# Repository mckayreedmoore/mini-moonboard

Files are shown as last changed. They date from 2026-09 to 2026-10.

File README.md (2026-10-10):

# Mini MoonBoard DIY frame

Engineering models, calculations, viewers and conditional shop documents for
a Mini MoonBoard-sized climbing wall. This independent project is not affiliated
with or endorsed by Moon Climbing.

## Main development: Compact bolted frame

Start at the **[development summary and revision map](docs/bolted-frame-development/README.md)**.
It identifies the current geometry, matching nominal shop records, applicable
numerical evidence and remaining work.

The current geometry is **`eoere-raised-kicker-screws-v1`**:
[open the current viewer](https://mckayreedmoore.github.io/mini-moonboard/?model=eoere-selected-hardware-frame-development&view=rear).
Its optional extra grid remains off and unofficial. The
[checked revision index](docs/bolted-frame-development/development-revisions.json)
separates this geometry and its matching shop plan from the preceding
six-case numerical evidence. The current viewer applies the selected bolt lengths and eight spacers
through a separately bound hardware overlay.
Actual hardware-fit, installation and joint-strength holds remain. No fabrication or climbing
release is established.

| Need | Start here |
| --- | --- |
| Model, shop records and next actions | [Main development entry](docs/bolted-frame-development/README.md) |
| Detailed evidence and task dispositions | [Development ledger](docs/wood-joints-mvp/completion-ledger.md#build-package-completion) |
| Preserved selected baseline | [Baseline reference packet](docs/README.md) · [machine authority](current-candidate.json) |
| Earlier options, failures and lessons | [Design-history catalog](docs/history/design-history.md) |
| Repository organization and evidence recovery | [Cleanup record](docs/repository-cleanup-evaluation-2026-09-28.md) |

## Selected baseline and history

The selected screw-and-bracket baseline remains `compact-floor-flush-development`
under [current-candidate.json](current-candidate.json). Its
[working set](docs/selected-working-set.md) and conditional shop/evidence packet
stay preserved. Its passes do not qualify the compact bolted development frame.

Earlier Eoere, HL35, thin-frame and wood-joint studies remain accessible through
the history catalog and [full viewer collection](https://mckayreedmoore.github.io/mini-moonboard/).
The viewer's no-query default remains the selected baseline; use the explicit
current-development link above. Original proposal contracts keep their own
revision identities.

## Contributor setup

Work on `master` and coordinate file ownership and publication with other agents.
Read [AGENTS.md](AGENTS.md) and [CONTRIBUTING.md](CONTRIBUTING.md) before changing
geometry, evidence or archived files.

```sh
uv sync --locked
uv run python -m http.server 8767 --directory site
```

Open [the local current-development viewer](http://localhost:8767/index.html?model=eoere-selected-hardware-frame-development&view=rear).
Required ignored inputs stay active; follow the documented recovery workflow
before reproducing or archiving evidence.

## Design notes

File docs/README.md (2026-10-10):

# Selected baseline reference packet

For ongoing compact bolted-frame engineering and builder-support work, start at the
**[main development summary and revision map](bolted-frame-development/README.md)**.
Its [active builder reading path](bolted-frame-development/README.md#active-builder-reading-path)
identifies the geometry, source-bound shop records, overrides and remaining holds.
The current geometry is **`eoere-raised-kicker-screws-v1`**:
[current viewer](https://mckayreedmoore.github.io/mini-moonboard/?model=eoere-selected-hardware-frame-development&view=rear).
The [checked revision index](bolted-frame-development/development-revisions.json) keeps
the matching shop plan separate from the preceding six-case numerical evidence.
The plan includes the current channel/screw changes and selected hardware
overrides, now applied by the separately bound hardware viewer overlay.
Historical results retain their own revision limits.

The instructions below belong to the selected screw-and-bracket baseline,
`compact-floor-flush-development`, governed by
[current-candidate.json](../current-candidate.json). They preserve that baseline's
conditional shop packet and evidence. Earlier models and results remain in the
[design-history catalog](history/design-history.md).

## 1. Baseline plywood variants

| You have | Open |
| --- | --- |
| Bought **4×4** sheets (or Mini kit panels) | [https://mckayreedmoore.github.io/mini-moonboard/](https://mckayreedmoore.github.io/mini-moonboard/) · [cut sheets](https://github.com/mckayreedmoore/mini-moonboard/tree/master/docs/floor-flush-construction) |
| **Cut 4×8** sheets | [https://mckayreedmoore.github.io/mini-moonboard/?model=compact-floor-flush-kerf-right](https://mckayreedmoore.github.io/mini-moonboard/?model=compact-floor-flush-kerf-right) · [cut sheets](https://github.com/mckayreedmoore/mini-moonboard/tree/master/docs/floor-flush-construction-kerf-right) |

Or open the first 3D link and pick the matching line under **Design**.
Details: [Which plywood packet](floor-flush-width-option.md).

Bought 4×4 versus cut 4×8

Left is A, right is K

## 2. Baseline cut, drill and assembly records

1. [Shop checklist](floor-flush-shop-checklist.md)
2. [Assembly guide](floor-flush-assembly-guide.md)
3. The cut-sheet folder from step 1

Supporting baseline references: [orientation](orientation.md) (left is A, right is K),
[hold hardware](moonboard-hold-hardware.md), [LED routing](led-wiring-reference.md),
[panel screws](current-panel-screw-purchase.md), [pads](current-crash-pad-construction.md),
[later insert option](screw-repair-inserts.md).

## 3. Baseline calculations and conditions

[Build package](floor-flush-build-package.md) ·
[Master plan](floor-runner-mvp-master-plan.md) ·
[Completion ledger](floor-runner-mvp-completion-ledger.md)

## Reading paths

For baseline shop records, use the matching **4×4** or **4×8** folder, the
**checklist** and the **assembly guide** together. Read their recorded conditions.
For the active development lane, return to the [compact bolted-frame summary](bolted-frame-development/README.md).
For earlier ideas and the writeup, use [history/](history/).

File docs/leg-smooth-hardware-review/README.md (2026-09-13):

# Smooth-body leg hardware investigation

> **Historical document — superseded as current guidance on September 12, 2026.**
> Start with the [current design basis](../current-design-basis.md) and
> [current design review](../current-design-review.md) for `no-shoes-development`.
> The original text below preserves its candidate-specific decisions and evidence;
> “current,” “next,” and release requirements below refer to that historical scope.
> Its dimensions, schedules and results do not qualify the latest candidate.

This is an isolated hardware candidate for the eight existing leg bolts in
`round-reinforcement-development`. It is **not selected or strength-qualified**.
The frame, holes, and all other hardware remain unchanged. Joint bending still
requires assessment; passing the stack and collision checks does not resolve it.

Each candidate stack contains a 3/8-16 × 5-inch SAE J429 Grade 5 bolt, two
fabricated A36 round plate washers (38.1 mm outside diameter, 11.1125 mm bore,
6.35 mm thickness), one nut-side steel spacer (20 mm outside diameter,
11.1125 mm bore, 19.05 mm length), and a matching Grade 5 nut. The spacer lies
between the nut-side plate and nut, outside the wood. Finished dimensions are
acceptance requirements. No existing purchased hardware is claimed compliant.

The dimensional calculation assumes each wood member measures 37.5–38.5 mm,
a maximum bolt length shortfall of 2.54 mm, a 25.4 mm reference thread length,
and five pitches of runout. The supplier must meet these assumptions. The
minimum smooth body covers both complete wood members and the head-side plate.
The nut seats beyond the maximum gaging length, with at least two pitches of
bolt projection beyond the maximum-height nut. Cylindrical head and nut
representations bound the conservative dimensional envelope; they do not model
thread engagement surfaces or certify a product standard.

`hardware.step` contains the 48 individually named candidate components only.
`review.json` records the dimensional corners, mass envelope and nominal CAD
checks. The CAD check tests intersections against the unchanged frame and other
hardware, and full ring support by translating each plate into its receiving
wood member. This is not a manufacturing-tolerance or installation-tool check.

Reproduce the review from the repository root:

```python
import json
from pathlib import Path
from mini_moonboard import leg_smooth_hardware as model

folder = Path("docs/leg-smooth-hardware-review")
report = model.export_review(folder)
report["geometry"] = model.geometry_review()
(folder / "review.json").write_text(json.dumps(report, indent=2) + "\n")
```

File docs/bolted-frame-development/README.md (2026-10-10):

# Compact bolted frame development

This is the main entry for `compact-bolted-frame-development`.
The current geometry is **`eoere-raised-kicker-screws-v1`**,
with the optional extra grid **off**: 22 timbers, six panels, 22 angles,
100 bolt stacks and 66 purchased Hillman panel/kicker screws. The retained
evidence folder keeps earlier wood-joint studies at their frozen paths. The selected
[baseline authority](../../current-candidate.json) stays separate.

The [checked revision index](development-revisions.json) binds geometry,
optional preview, applied hardware and response separately. The current geometry
raises two upper outer kicker screws/holes from Z192 to **Z212 mm**, retaining
all 100 bolt axes. The modeled maximum-bore/screw gap is **3.94375 mm**;
post-top axis distance is 26.9 mm and end-distance strength remains unqualified.
The preceding smaller channels and eleven filled principal arc cuts remain.
The viewer applies `eoere-selected-purchase-hardware-v1`: 32 longer bolts and eight spacers, with all axes retained.

## Active builder reading path

| Need | Start here | Boundary |
| --- | --- | --- |
| Current geometry | [Selected-hardware viewer](https://mckayreedmoore.github.io/mini-moonboard/?model=eoere-selected-hardware-frame-development&view=rear) · [receipt](../wood-joints-mvp/hypotheses/hl35-candidate/thin-frame-comparison/eoere-successor-v1/occupied-kicker-clearance-v1.json) | Geometry evidence only; 100 bolts fixed, two screws raised. |
| Current shop records and hardware choice | [Matching shop packet](../wood-joints-mvp/hypotheses/hl35-candidate/thin-frame-comparison/eoere-successor-v1/shop-assembly-v1/extended-cleat-followup-v1/current-model-followup-v1/README.md) · [100 selected stacks](../wood-joints-mvp/hypotheses/hl35-candidate/thin-frame-comparison/eoere-successor-v1/shop-assembly-v1/extended-cleat-followup-v1/current-model-followup-v1/hardware-selection.csv) | Current screw/channel datums; selected bolt lengths and eight spacers are now applied in the viewer. Actual fit and strength remain open. |
| Preserved fixture concepts | [Builder drilling guide](../wood-joints-mvp/eoere-builder-drilling-guide.md) | Frozen aligned-wire geometry; later v3 moved 22 shafts and ten screws. Actual reach, fixtures and tools remain unresolved. |
| Latest numerical evidence | [Six fresh cases](../../fea/generated/thin-bolted-current-contact-v1/eoere-successor-v1/adjusted-base-mechanics-v1/current-cases-v1/result-v1.json) · [parent verification](../../fea/generated/thin-bolted-current-contact-v1/eoere-successor-v1/adjusted-base-mechanics-v1/current-cases-v1/parent-verification-v1.json) | Preceding extended-cleat geometry, extra grid off. Passing numerical audits do not transfer to the channel or raised-screw revisions. |
| Structural assessment | [Current bounded assessment](../wood-joints-mvp/hypotheses/hl35-candidate/thin-frame-comparison/eoere-successor-v1/selected-hardware-v1/README.md#bounded-mechanics-review) | All 100 stacks/120 timber intervals; 68 potential thread/runout bounds exceed one quarter. Earlier references retain exceedances; current complete resistance remains null. |
| Detailed tasks and holds | [Completion ledger](../wood-joints-mvp/completion-ledger.md#build-package-completion) · [qualification status](../wood-joints-mvp/completion-ledger.md#current-model-completion-scope-and-qualification-status) | Source bindings, reviews and missing inputs; earlier “current” sections keep their historical meaning. |

## Revision map

Geometry, response and shop coverage have different boundaries:

| Role | Exact revision / record | Viewer or scope |
| --- | --- | --- |
| **Main geometry** | `eoere-raised-kicker-screws-v1` · [receipt](../wood-joints-mvp/hypotheses/hl35-candidate/thin-frame-comparison/eoere-successor-v1/occupied-kicker-clearance-v1.json) | [Extra grid off](https://mckayreedmoore.github.io/mini-moonboard/?model=eoere-selected-hardware-frame-development&view=rear); two holes/screws raised, bolts fixed. |
| Optional unofficial preview | Current geometry plus `eoere-expanded-right-column-v1` · [receipt](../wood-joints-mvp/hypotheses/hl35-candidate/thin-frame-comparison/eoere-successor-v1/occupied-right-column-v1.json) | [Extra grid on](https://mckayreedmoore.github.io/mini-moonboard/?model=eoere-selected-hardware-grid-development&view=rear); 264 main positions, with a new column 100 mm right of K. |
| Preserved 252-position preview | `eoere-2026-horizontal-midpoint-grid-v3` | [Earlier extra grid](https://mckayreedmoore.github.io/mini-moonboard/?model=eoere-kicker-clearance-2026-development&view=rear); 120 added T-nuts/lights and 119 links. |
| Smaller-channel predecessor | `eoere-uniform-small-service-channels-v1` · [receipt](../wood-joints-mvp/hypotheses/hl35-candidate/thin-frame-comparison/eoere-successor-v1/occupied-uniform-channels-v1.json) | [Preserved viewer](https://mckayreedmoore.github.io/mini-moonboard/?model=eoere-uniform-channels-frame-development&view=rear); preceding kicker positions. |
| Applied hardware geometry | `eoere-selected-purchase-hardware-v1` · [receipt](../wood-joints-mvp/hypotheses/hl35-candidate/thin-frame-comparison/eoere-successor-v1/occupied-selected-hardware-v1.json) | [Nominal installation followup](../wood-joints-mvp/hypotheses/hl35-candidate/thin-frame-comparison/eoere-successor-v1/selected-hardware-v1/README.md); 100 bolt axes retained, 32 shafts extended, eight spacers added. |
| **Current shop plan** | `eoere-raised-kicker-screws-v1` | [Current packet](../wood-joints-mvp/hypotheses/hl35-candidate/thin-frame-comparison/eoere-successor-v1/shop-assembly-v1/extended-cleat-followup-v1/current-model-followup-v1/README.md), composing current channels/screws with unchanged raw cuts, nesting, recesses and receiver axes. The separately bound hardware overlay applies the purchase override. |
| **Latest six-case response** | `eoere-base-side-edge-cleats-v1` · [receipt](../wood-joints-mvp/hypotheses/hl35-candidate/thin-frame-comparison/eoere-successor-v1/occupied-extended-cleats-v1.json) | [Preserved viewer](https://mckayreedmoore.github.io/mini-moonboard/?model=eoere-extended-cleat-frame-development&view=rear); six own-case admissions and twelve component reports, fixed-rear-leg support scenario. |
| Unadopted lower-corner proposal | `eoere-lower-cleat-z180-proposal-v1` | [Z180 preview](https://mckayreedmoore.github.io/mini-moonboard/?model=eoere-lower-cleat-z180-development&view=rear) · [separate shop packet](../wood-joints-mvp/hypotheses/hl35-candidate/thin-frame-comparison/eoere-successor-v1/shop-assembly-v1/extended-cleat-followup-v1/z180-proposal-v1/README.md); four stacks lowered 20 mm and eight replacement holes, with its own six-case response. |
| Original Eoere proposal | `eoere-far-pairs-cleat-corners-v1` · [frozen contract](../../eoere-bolted-candidate.json) | [Earlier viewer](https://mckayreedmoore.github.io/mini-moonboard/?model=eoere-bolted-development&view=rear); retained proposal identity. |

## Current disposition

The current shop packet covers 28 profiles, 120 receiver-hole occurrences,
66 screw axes, 340 panel datums, 32 base channel occurrences, 100 selected
hardware sets and 200 access sides. It keeps the 13-stick / 150-board-foot
stock scenario. The combined nominal mass estimate is 219.517834 kg,
including selected hardware increments; actual weight is unmeasured.

Selected Grade 5 full-body partial-thread lengths clear the catalog seating
and two-tip-pitch comparisons. Forty-eight added hardware envelopes clear
nominal parts. The dated fastener basket is $148.51 before angles/tax/shipping.
**Cleat/post holds concern end strength, actual tolerances/contact and
tool qualification.** The modeled screw conflict and nominal stack choice are
resolved. Nominal box-wrench insertion, a 60° handle sweep, counterhold and
removal clear all 200 sides; twelve need raised/reoriented support and up to 93.222 mm below-frame clearance.
The assumed long socket fails at 24 nut sides.
Guide rings and two clamp pads have nominal finished-face support at all
120 receivers. The proposed alignment budget has only 0.011771 mm remaining
at the longest path; actual tooling and observations stay unresolved/blank.
See the [installation study](../wood-joints-mvp/hypotheses/hl35-candidate/thin-frame-comparison/eoere-successor-v1/selected-hardware-v1/README.md) and [current followup](../wood-joints-mvp/completion-ledger.md#current-shop-and-hardware-selection).

The preceding extended-cleat numerical packet retains six genuine own-case
admissions under the original loads, 32 compression-only floor points and two
rear-leg XY restraints under the unverified no-slip assumption. Its largest
full-gradient residual is **6.128662e-6 N**, within the unchanged 1e-5-N gate.
Reference exceedances remain for generic screw heads, panel bending/rolling
shear and the t6/Ri6 heel scenario. The owner nominal t6.35/Ri6.35 heel reference
has a small margin; actual formed-product resistance remains unknown.
Physical applicability, finished sections, restraint, demand bounds and all
complete-joint resistances remain open. See the
[detailed numerical record](../wood-joints-mvp/completion-ledger.md#current-extended-cleat-numerical-completion)
for comparisons, sensitivity exceedances and the source-captured panel-RHS limit.

## Proposed Z180 evaluation

The **unadopted** Z180 layout has six fresh admitted cases and six combined
component reports under its own inputs. Maximum full-gradient residual is
**4.585086e-6 N**, within the same 1e-5-N gate. Reference exceedances and small
nominal heel margins remain; first-order applicability and complete-joint
resistance are unqualified. Its results do not select the proposal or release
current Z200 operations. The [detailed proposal record](../wood-joints-mvp/completion-ledger.md#lowered-cleat-bolt-proposal-conditional-numerical-completion)
links the full comparisons, fixtures, reviews and retained raw evidence.

The owner-requested optional column adds twelve T-nuts and matching LEDs at
X2300 mm: **264 main positions**, plus ten unchanged kicker positions.
The two right panels include the new bores. Three right rails receive the
existing smaller cable-channel profile; all 100 bolt and 66 screw axes stay fixed.
Exact CAD checks clear the new services and generic rear-bolt envelopes:
**33.625 mm** flange-to-right-4×6 gap and **14.325 mm** cable gap.
The original-grid option and preceding 252-position viewer remain available.
Future official grid/holds, actual hold footprints, cable installation and
changed-section strength remain unresolved. See the
[right-column implementation](../wood-joints-mvp/completion-ledger.md#owner-requested-right-column-preview).

## Remaining work and next actions

1. The owner-directed bounded structural assessment is complete. Current screw/end,
   complete-joint, finished-section and restraint acceptance remain unresolved.
2. Retain every recorded exceedance without a remedy. Catalog bounds do not
   establish actual thread exposure, connected contact/yield or current resistance.
3. Actual build-fit work is excluded from this continuation; observations stay blank.
   The existing physical-operation limits remain, without commissioning more fit work.
4. Keep CI passing through its existing publication gates. Preserve the 66-screw policy;
   panel/screw remedies remain stopped, and the extra grid and Z180 stay unadopted.

## Engineering reading order

Use the geometry and shop paths above, then the
[bounded studies](../wood-joints-mvp/hypotheses/hl35-candidate/thin-frame-comparison/eoere-successor-v1/bounded-strength-v1/README.md),
[resistance followup](../wood-joints-mvp/hypotheses/hl35-candidate/thin-frame-comparison/eoere-successor-v1/bounded-strength-v1/resistance-followup-v1/README.md),
[adjusted-base audit](../wood-joints-mvp/hypotheses/hl35-candidate/thin-frame-comparison/eoere-successor-v1/bounded-strength-v1/revised-base-audit-v1/README.md)
and [connected-stack followup](../wood-joints-mvp/hypotheses/hl35-candidate/thin-frame-comparison/eoere-successor-v1/bounded-strength-v1/connected-stack-followup-v1/README.md).
Their older actions, local geometry and trial bearing parameters keep their limits.
Use the [guarded reproduction entrypoints](../wood-joints-mvp/hypotheses/hl35-candidate/thin-frame-comparison/eoere-successor-v1/bounded-strength-v1/revised-base-audit-v1/reproduction-guard-v1/README.md).

## Conditional operations and purchasing

Shop tables apply only to their named revision and explicit overrides. Model
occupancy and CSV lengths are analysis envelopes. Partially threaded bolts
remain the basis; delivered shank and full nut seating require per-stack checks.
No insert pilots, physical testing, cutting or drilling release is supplied here.

## History and evidence recovery

Use the [history catalog](../history/design-history.md#eoere-development-sequence)
for preceding Eoere, thin-frame and wood-joint options. The
[frozen pre-compaction summary](../history/eoere-development-summary-before-compaction.md)
preserves the `845e2e0c` payload; [browse its original commit](https://github.com/mckayreedmoore/mini-moonboard/blob/845e2e0cf2bf1514398e115c382865579fd77141/docs/wood-joints-mvp/README.md)
for working historical relative links. The ledger and frozen packets stay in place.

Earlier [wood-joint records](../history/wood-joint-development-summary-before-navigation-cleanup.md#current-working-model),
[Eoere A12 discussion](../history/eoere-development-summary-before-compaction.md#preserved-earlier-eoere-a12-packet)
and [thin-frame discussion](../history/eoere-development-summary-before-compaction.md#preserved-thin-b103b104-predecessor)
retain their own geometry, loads and unresolved criteria.

Required cached solids, fields, operators, source banks and reviews remain
**active inputs**, including ignored `fea/generated/`. The 1,446 hardware-geometry and 1,535 access-study pins remain active. Use the
[cleanup/recovery record](../repository-cleanup-evaluation-2026-09-28.md) and
[contributor workflow](../../CONTRIBUTING.md) before moving files. Historical
viewers and mesh aliases stay available. The persistent kit restored all 1,219 recorded inputs; no raw inputs are pruned.
Pages publication requires successful CI for the exact master revision; see the [CI repair record](../wood-joints-mvp/completion-ledger.md#ci-repair-and-current-structural-assessment).

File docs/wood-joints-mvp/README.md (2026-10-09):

# Wood-joint studies and former development entry

Active work is now **[Compact bolted frame development](../bolted-frame-development/README.md)**,
with the [checked revision index](../bolted-frame-development/development-revisions.json).
Its neutral candidate name is `compact-bolted-frame-development`. This legacy
folder retains source-bound wood-joint and Eoere evidence at its original paths;
older candidate and geometry IDs keep their recorded meanings.

## Active builder reading path

Use the [current reading path](../bolted-frame-development/README.md#active-builder-reading-path).

## Revision map

Use the [current revision map](../bolted-frame-development/README.md#revision-map).

## Current disposition

Use the [current disposition](../bolted-frame-development/README.md#current-disposition).

## Proposed Z180 evaluation

The [separate proposal](../bolted-frame-development/README.md#proposed-z180-evaluation)
remains unadopted.

## Remaining work and next actions

Use the [current next actions](../bolted-frame-development/README.md#remaining-work-and-next-actions).

## Engineering reading order

Use the [current engineering reading order](../bolted-frame-development/README.md#engineering-reading-order).

## Conditional operations and purchasing

Use the [current conditions](../bolted-frame-development/README.md#conditional-operations-and-purchasing).

## History and evidence recovery

Use [history and recovery](../bolted-frame-development/README.md#history-and-evidence-recovery).
The [completion ledger](completion-ledger.md) and immutable hypothesis packets
remain here; this navigation change supplies no geometry or acceptance change.

Earlier [wood-joint records](../history/wood-joint-development-summary-before-navigation-cleanup.md#current-working-model),
[Eoere A12 discussion](../history/eoere-development-summary-before-compaction.md#preserved-earlier-eoere-a12-packet)
and [thin-frame discussion](../history/eoere-development-summary-before-compaction.md#preserved-thin-b103b104-predecessor)
retain their original evidence scope.

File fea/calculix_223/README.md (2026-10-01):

# CalculiX 2.23 development toolchain

The owner requested this update on September 27, 2026. The locally installed
image is `mini-moonboard-fea:ccx-upstream-2.23-v1`. Use the immutable image ID,
explicit binary path and binary hash in `solver-profile.json` for new wood-joint
diagnostics. The binary is `/usr/local/bin/ccx-upstream-2.23`; invoking the
inherited `/usr/bin/ccx` would still run the preserved 2.21 package.

The selected baseline, existing 2.21 images, frozen inputs and previous
evidence retain their original pins. Existing historical runners have not
been rewritten to silently use a different solver. A new joint runner must
consume the new profile explicitly and bind it into its input manifest.

The six unchanged method fixtures reproduce the 2.21 numerical audit values
exactly at the available output precision. Balanced-force loading passes;
the prescribed dynamic average-MPC route remains unsuitable. These tests do
not validate the actual joint's C3D10 elements, contact or bolt/nut coupling.
See the [upgrade record](../../docs/wood-joints-mvp/hypotheses/evaluation-resume-2026-09-24/calculix-2.23-upgrade-attempt01/README.md).

The official 2.23 source archive is pinned by SHA-256. The build uses the
existing immutable development image for its compilers and libraries. No
upstream source files are patched. `Makefile.upstream` adapts library paths
and uses `-cpp`, as required by the official 2.23 Makefile. The first attempt
omitted that flag and failed on `ifport.mod`; its record is retained.

To reproduce on a machine with the recorded base image and no existing 2.23
tag, use a fresh output directory:

```bash
python3 fea/calculix_223/build.py fea/generated/calculix-2.23-build-NEW
.venv/bin/python fea/calculix_223/replay.py \
  fea/generated/calculix-2.23-build-NEW \
  fea/generated/calculix-2.23-replay-NEW
```

The builder refuses to replace an existing evidence image. Replays copy
source-bound input decks and auditor implementations into a new directory,
run jobs serially, and preserve raw output and executable identity. A failed
motion fixture is a retained diagnostic, not an overall structural pass.

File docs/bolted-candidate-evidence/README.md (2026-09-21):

# Astra RV-3: PB-01 four-contact quarter diagnostic evidence

This directory preserves the latest relevant `a12-left` quarter-labelled
four-contact run found in `/tmp`: `mini_pb01_quarter_contact4_a12left_4c60e46`.
The top-level report SHA-256 is
`c10b2b2d1b979fe82ffc5bca31c60e374650610e4c44245e8e56431c7b0c4918`.
The copied archive SHA-256 is
`fc298a3a481437a5dc9f24c02bc9a234458074c2ffcba6753fe33875f4805546`.
It is a byte-for-byte copy of the existing frozen archive in
`docs/bolted-candidate-prototypes/`; no native solve was run for RV-3.

The [archive](pb01-quarter-contact4-a12left-evidence.tar.gz) contains the
original report and its 260-entry source SHA-256 manifest, all 260 source
snapshots, diagnostic scope, and matching `cycle-13` input and report. It also
contains that cycle's native solver deck (`frame.inp`), data (`frame.dat`),
run log (`frame.log`) and status (`frame.sta`). The report records the full
14-cycle contact history and original artifact hashes; earlier raw cycles are
not packaged. The empty or nonessential native outputs and model pickle are
not needed for the local-force extraction.

[Local forces](local-forces.json) are the signed bolt/contact actions and
interface resultants from the existing source-authenticated extractor.
[Replay seed](replay-seed.json) records the source commit, case, variant,
contact update strategy, initial contacts, solver image, trial stiffnesses,
scope and runner arguments. The native source snapshots are the preserved
source-of-record for this run; the current checkout may have changed.

To verify or regenerate the two small JSON sidecars from the frozen archive,
run `python3 docs/bolted-candidate-evidence/archive.py` from the repository
root. This checks the archive identity, source snapshots, final-cycle hashes,
and local extraction. It never invokes the solver. The source archive is only
needed if the copied archive is absent. The original extractor can also run
against this copy with `python3 -m scripts.simple_pb01_hybrid_local_actions
--archive docs/bolted-candidate-evidence/pb01-quarter-contact4-a12left-evidence.tar.gz`.

This run uses one trial 1/4-in four-bolt cleat at PB-01 with four
compression-only contact samples on each face; 23 other ML24Z/SDS stations
remain old-topology proxies. Bolt axial, bolt lateral and total face normal
stiffness were each assumed 1,000 N/mm. The quarter variant changes trial
stack mass only in this native model; bore diameter does not change its mesh.
Convergence and equilibrium apply to this numerical diagnostic only. It is
not a V4 same-case demand, joint rating, design acceptance or drilling release.

## Later six-inch, tension-only diagnostic (different model)

The separate [A12-left ZIP](pb01-short-tension-a12-165adbf-evidence.zip),
[K12-right ZIP](pb01-short-tension-k12-165adbf-evidence.zip), and
[signed comparison](pb01-short-tension-a12-k12-165adbf-comparison.json)
record the 152.4-mm corner-block variant with no-preload tension-only bolt
axial springs and compression-only face contacts. Both cases converged at
cycle 13 with numerical equilibrium. Each ZIP contains the final-cycle
input/report/native files and 260 authenticated source snapshots. Run
`uv run --no-sync python -m scripts.simple_pb01_short_tension_evidence verify`
followed by the ZIP path to verify it without the temporary run directory.
See [the case note](../bolted-candidate-prototypes/simple-pb01-short-tension-evidence.md)
for hashes and scope. These newer runs still retain 23 legacy connector
stations and do not qualify a complete V4 frame, joint or drilling plan.

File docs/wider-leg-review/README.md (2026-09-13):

# Single-2×8 leg connection review package

> **Historical document — superseded as current guidance on September 12, 2026.**
> Start with the [current design basis](../current-design-basis.md) and
> [current design review](../current-design-review.md) for `no-shoes-development`.
> The original text below preserves its candidate-specific decisions and evidence;
> “current,” “next,” and release requirements below refer to that historical scope.
> Its dimensions, schedules and results do not qualify the latest candidate.

This package implements the six-bolt connection in actual frame geometry.
**Assessment failed; do not use these drilling coordinates for construction.**
See the [decision and specific failures](../wider-leg-decision.md). It is
an isolated fresh-stock candidate, not a construction release. Use the final
[assessment](../../fea/results/wider-leg-assessment.json) for numerical decisions;
the earlier 0.818 feasibility ratio describes a different, centered-stock layout.

## What changed

- Replace both support legs and both adjoining outer rims with single nominal
  2×8 members. No doubled vertical stock is used.
- Keep the rims' panel-facing surfaces fixed; the additional depth grows rearward.
- Use six ½-inch bolts per leg, replacing four. The pattern has three stations
  at 66 mm along the leg and two stations at 84 mm along the rim.
- Move the group center 27 mm along the leg and 4 mm along the rim from the old
  four-bolt center. Extend the leg's upper end by 50 mm to maintain end distance.
- Use catalog bearing plates and extra-thick washers. The new leg detail needs
  no custom metal fabrication.

The assembly retains the preceding reinforcement candidate's other components,
including its historical base shoes. This package does not convert the whole
board to a fabrication-free design or qualify those base shoes.

## Lumber and hardware

Require dry, unincised, grade-stamped Douglas Fir–Larch No. 2 or a separately
checked substitute. Nominal section is 38.1 × 184.15 mm; accepted thickness
for the bolt stack is 37.5–38.5 mm. Dimensions and grain direction matter;
an unspecified species or grade is not interchangeable.

| New stock | Quantity | Minimum modeled blank length | Practical stock length |
| --- | ---: | ---: | ---: |
| Single 2×8 outer rim | 2 | 2608.024 mm | 10 ft |
| Single 2×8 support leg | 2 | 1863.960 mm | 8 ft |

Blank lengths are stock envelopes, not instructions to make both ends square.
The STEP model defines bearing-end cuts and the level leg foot. Hardware totals
are 12 Grade 5 ½-13 × 5-inch bolts, 12 matching nuts, 24 Simpson BP1/2 plates,
and 36 Wrought MCX 014943 washers. See the complete
[hardware schedule and acceptance dimensions](../wider-leg-hardware.md).

## Geometry and drilling

- [Complete STEP assembly](assembly.step)
- [24 member-hole drilling records](drilling.csv)
- [Geometry, mass, interference and source-hash report](review.json)
- [Parametric source](../../mini_moonboard/wider_leg_frame.py)

The CSV identifies each member, world Y/Z position, grain station, depth
coordinate and datum. Each bolt passes through two members, hence 24 records
for 12 bolts. Bore diameter is 14.2875 mm (9/16 inch). The coordinates describe
fresh stock; they are not a repair pattern for previously drilled members.
Use the STEP datum geometry when laying out the CSV. Do not substitute the
older preliminary pattern's −20 mm group shift.

Nominal checks find no new interference, all bores fully contained, and all 24
plates fully supported. The narrowest nominal plate-edge reserve is about
2.45 mm. That reserve is the total available allowance for stock-edge,
hole-location and plate-orientation errors together; it is not an additional
per-operation tolerance. Verify full plate support on the actual assembly.
This report does not claim a manufacturing-tolerance sweep.

Complete modeled assembly mass is 194.583 kg before the separately applied
hold/electrical equipment allowance. Existing panel attachment and LED axes
remain in the model. Source hashes bind the nominal geometry evidence to the
files used to generate it.

## Scope of acceptance

The wood, dowel, plate and washer calculations are analytical comparisons with
explicit load/contact/material assumptions. They are not measured breaking
strengths. A passing conditional ratio cannot establish an unverified plate
material property, foot-pressure distribution or lap-joint prying bound.
Owner acceptance of panel construction and exclusion of floor-friction testing
remain the scope basis; no additional panel or floor test is requested here.

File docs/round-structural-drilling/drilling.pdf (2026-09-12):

# main_lower_left — HOLD / LED DRILLING

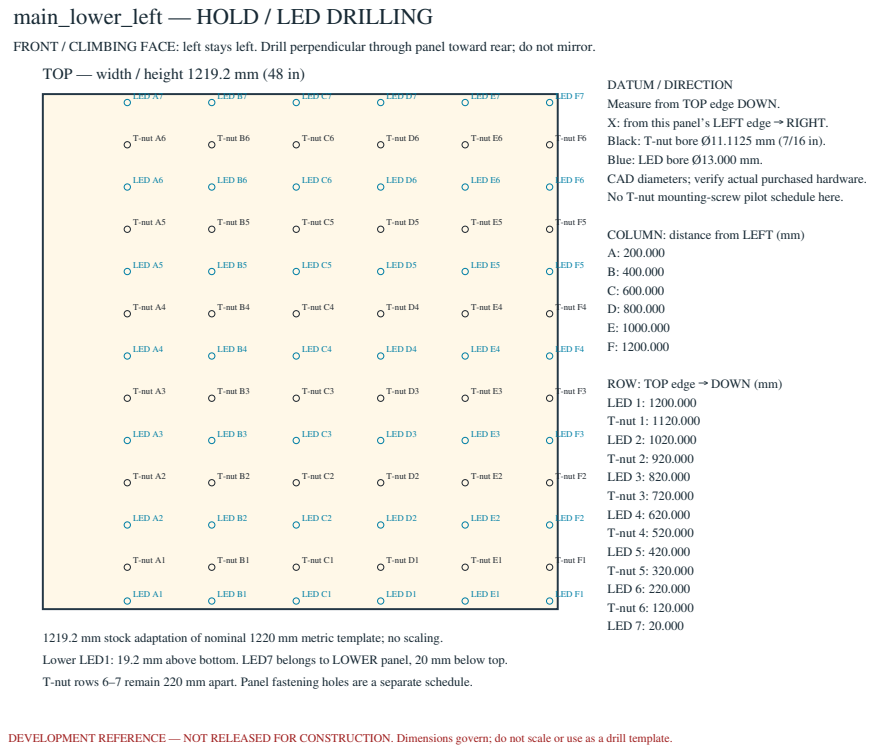
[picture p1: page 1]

FRONT / CLIMBING FACE: left stays left. Drill perpendicular through panel toward rear; do not mirror.
TOP — width / height 1219.2 mm (48 in)

DATUM / DIRECTION
Measure from TOP edge DOWN.
X: from this panel’s LEFT edge → RIGHT.
Black: T-nut bore Ø11.1125 mm (7/16 in).
Blue: LED bore Ø13.000 mm.
CAD diameters; verify actual purchased hardware.
No T-nut mounting-screw pilot schedule here.

1219.2 mm stock adaptation of nominal 1220 mm metric template; no scaling.
Lower LED1: 19.2 mm above bottom. LED7 belongs to LOWER panel, 20 mm below top.
T-nut rows 6–7 remain 220 mm apart. Panel fastening holes are a separate schedule.

DEVELOPMENT REFERENCE — NOT RELEASED FOR CONSTRUCTION. Dimensions govern; do not scale or use as a drill template.

# main_lower_right — HOLD / LED DRILLING

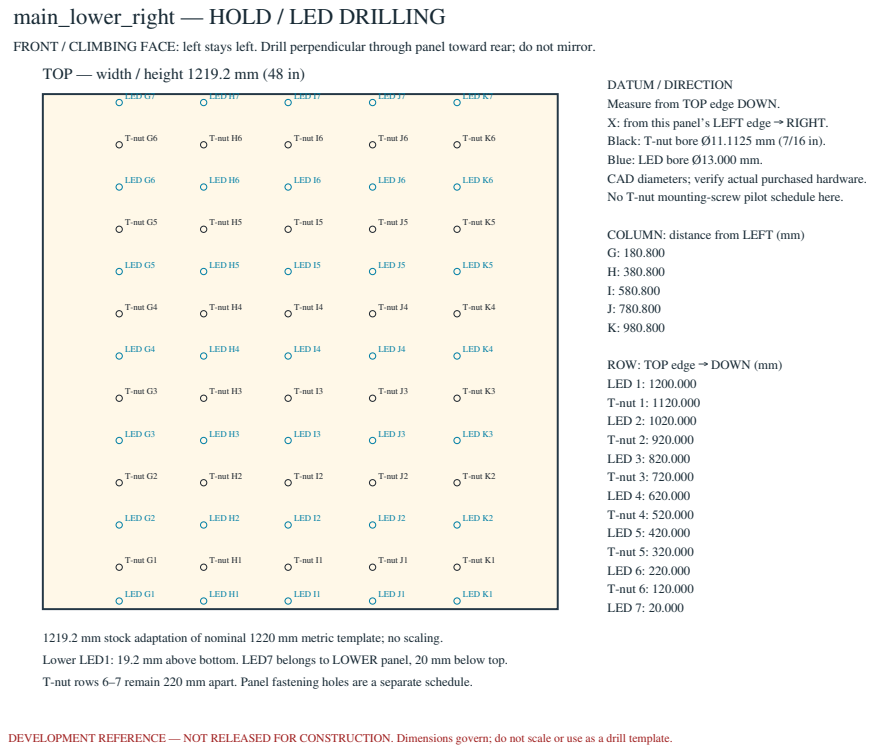
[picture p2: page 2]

FRONT / CLIMBING FACE: left stays left. Drill perpendicular through panel toward rear; do not mirror.
TOP — width / height 1219.2 mm (48 in)

DATUM / DIRECTION
Measure from TOP edge DOWN.
X: from this panel’s LEFT edge → RIGHT.
Black: T-nut bore Ø11.1125 mm (7/16 in).
Blue: LED bore Ø13.000 mm.
CAD diameters; verify actual purchased hardware.
No T-nut mounting-screw pilot schedule here.

1219.2 mm stock adaptation of nominal 1220 mm metric template; no scaling.
Lower LED1: 19.2 mm above bottom. LED7 belongs to LOWER panel, 20 mm below top.
T-nut rows 6–7 remain 220 mm apart. Panel fastening holes are a separate schedule.

# main_upper_left — HOLD / LED DRILLING

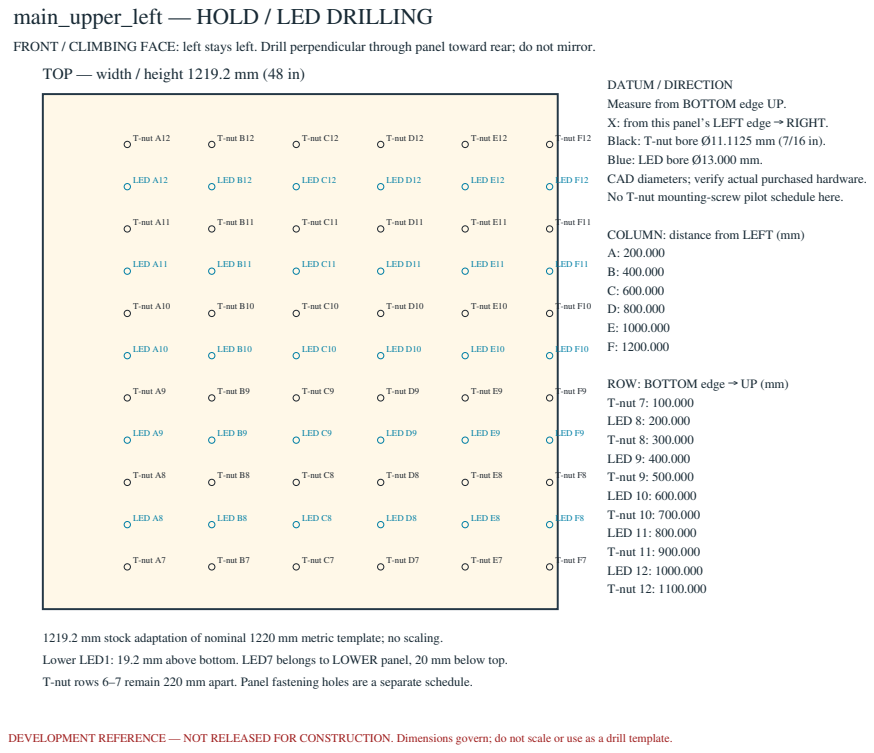
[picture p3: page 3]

FRONT / CLIMBING FACE: left stays left. Drill perpendicular through panel toward rear; do not mirror.
TOP — width / height 1219.2 mm (48 in)

DATUM / DIRECTION
Measure from BOTTOM edge UP.
X: from this panel’s LEFT edge → RIGHT.
Black: T-nut bore Ø11.1125 mm (7/16 in).
Blue: LED bore Ø13.000 mm.
CAD diameters; verify actual purchased hardware.
No T-nut mounting-screw pilot schedule here.

1219.2 mm stock adaptation of nominal 1220 mm metric template; no scaling.
Lower LED1: 19.2 mm above bottom. LED7 belongs to LOWER panel, 20 mm below top.
T-nut rows 6–7 remain 220 mm apart. Panel fastening holes are a separate schedule.

# main_upper_right — HOLD / LED DRILLING

FRONT / CLIMBING FACE: left stays left. Drill perpendicular through panel toward rear; do not mirror.

### TOP — width / height 1219.2 mm (48 in)

DATUM / DIRECTION
Measure from BOTTOM edge UP.
X: from this panel’s LEFT edge → RIGHT. Black: T-nut bore Ø11.1125 mm (7/16 in).
Blue: LED bore Ø13.000 mm.
CAD diameters; verify actual purchased hardware. No T-nut mounting-screw pilot schedule here.

COLUMN: distance from LEFT (mm)
G: 180.800
H: 380.800
I: 580.800
J: 780.800
K: 980.800

ROW: BOTTOM edge → UP (mm) T-nut 7: 100.000
LED 8: 200.000
T-nut 8: 300.000
LED 9: 400.000
T-nut 9: 500.000
LED 10: 600.000
T-nut 10: 700.000
LED 11: 800.000
T-nut 11: 900.000
LED 12: 1000.000
T-nut 12: 1100.000

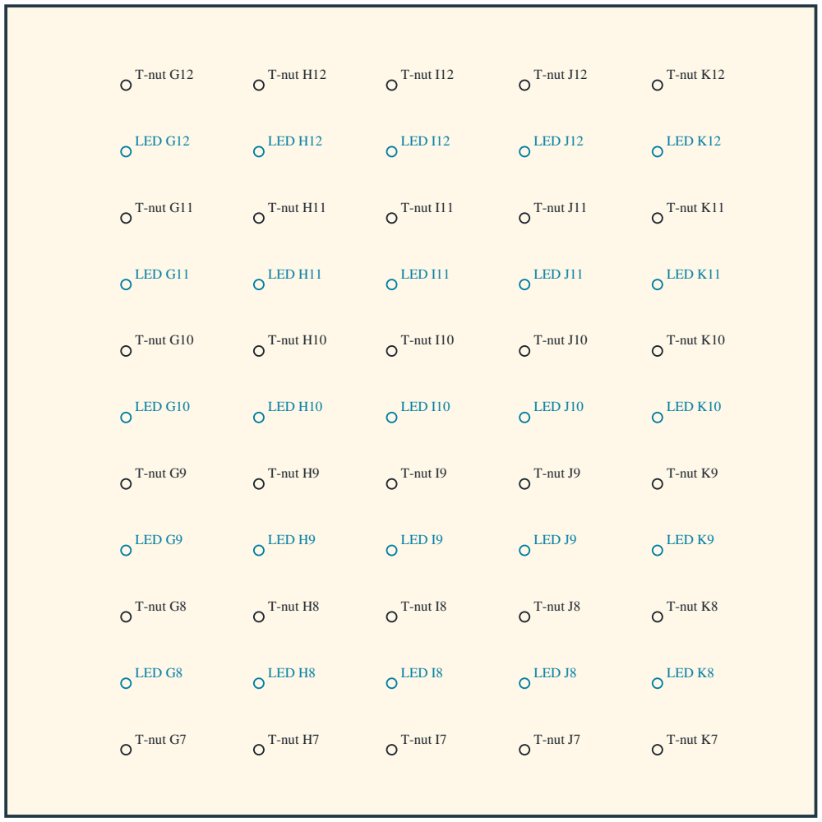
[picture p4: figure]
T-nut G7; T-nut G8; T-nut G9; T-nut G10; T-nut G11; T-nut G12; T-nut H7; T-nut H8; T-nut H9; T-nut H10; T-nut H11; T-nut H12; T-nut I7; T-nut I8; T-nut I9; T-nut I10; T-nut I11; T-nut I12; T-nut J7; T-nut J8; T-nut J9; T-nut J10; T-nut J11; T-nut J12; T-nut K7; T-nut K8; T-nut K9; T-nut K10; T-nut K11; T-nut K12; LED G8; LED G9; LED G10; LED G11; LED G12; LED H8; LED H9; LED H10; LED H11; LED H12; LED I8; LED I9; LED I10; LED I11; LED I12; LED J8; LED J9; LED J10; LED J11; LED J12; LED K8; LED K9; LED K10; LED K11; LED K12

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

# kicker_left — FIVE HOLD / T-NUT BORES

FRONT / CLIMBING FACE: left stays left. Drill perpendicular toward rear (-Y); do not mirror.

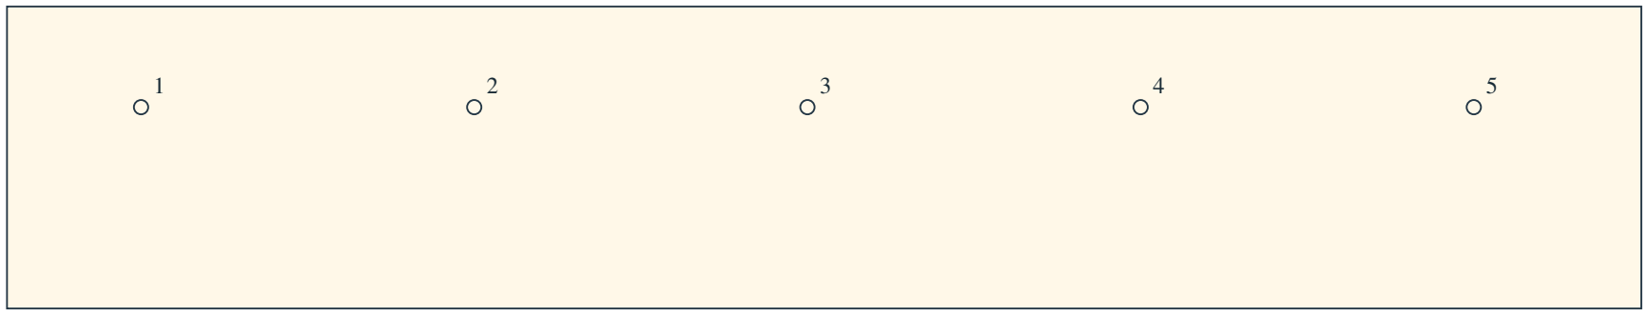
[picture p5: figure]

Panel: 1219.200 mm wide x 225.000 mm high.
Measure RIGHT from this panel’s LEFT edge (+X); measure DOWN from TOP.
Every bore: 75.000 mm below TOP, 150.000 mm above BOTTOM; diameter 11.1125 mm (7/16 in). These are existing hold/T-nut axes; no LED holes or panel-fastening pilots are added.
Verify the purchased T-nut; retention-screw instructions remain separate.

HOLD LABEL — FROM THIS PANEL’S LEFT EDGE (mm)
1: 100.000
2: 348.560
3: 597.120
4: 845.680
5: 1094.240

# kicker_right — FIVE HOLD / T-NUT BORES

FRONT / CLIMBING FACE: left stays left. Drill perpendicular toward rear (-Y); do not mirror.

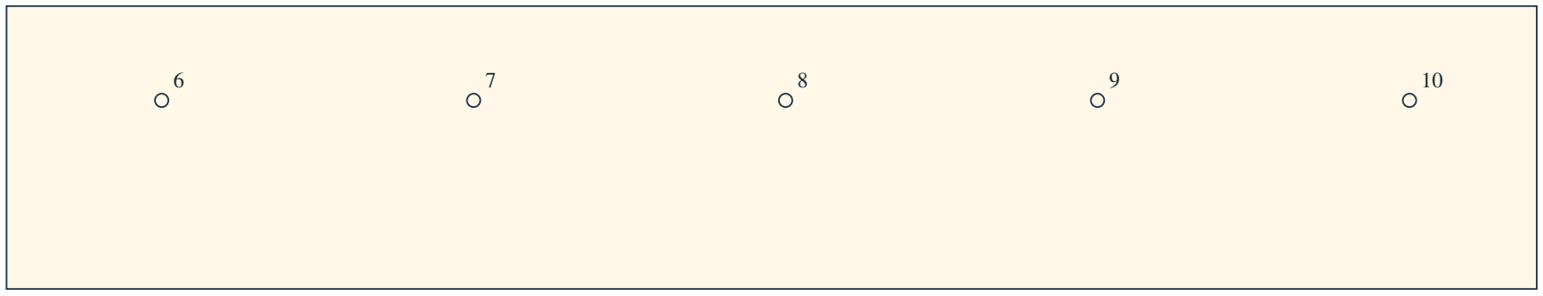
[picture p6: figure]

Panel: 1219.200 mm wide x 225.000 mm high.
Measure RIGHT from this panel’s LEFT edge (+X); measure DOWN from TOP.
Every bore: 75.000 mm below TOP, 150.000 mm above BOTTOM; diameter 11.1125 mm (7/16 in). These are existing hold/T-nut axes; no LED holes or panel-fastening pilots are added.
Verify the purchased T-nut; retention-screw instructions remain separate.

HOLD LABEL — FROM THIS PANEL’S LEFT EDGE (mm)
6: 123.600
7: 372.160
8: 620.720
9: 869.280
10: 1117.840

# main_lower_left — PANEL FASTENING AXES

FRONT / CLIMBING FACE: measure right from LEFT edge and up from BOTTOM edge; do not mirror.

Development layout: 12 screws on this panel; count does not establish resistance.
Coordinates below are panel-local millimeters. Drill axis is perpendicular to the panel.
SPAX XFT08P-2000 #8 x 2 inch: nominal 90-degree included head angle, 8.128 mm head diameter. Set a flush seat using the actual screw and a matched tool on an offcut; do not overdrive.
No full-shank pilot diameter or countersink machining depth is specified here.
Reference: docs/round-panel-countersink-reference.json (nominal US family drawing).

AXIS FROM LEFT FROM BOTTOM RECEIVER
rim 1: 19.050 / 59.050 mm; base_side_left
rim 2: 19.050 / 417.433 mm; base_side_left
rim 3: 19.050 / 775.817 mm; base_side_left
rim 4: 19.050 / 1134.200 mm; base_side_left
center 1: 1149.200 / 59.050 mm; base_principal_center_left center 2: 1149.200 / 417.433 mm; base_principal_center_left center 3: 1149.200 / 775.817 mm; base_principal_center_left center 4: 1149.200 / 1134.200 mm; base_principal_center_left edge 1: 784.125 / 59.050 mm; base_rail_bottom_left
edge 2: 384.125 / 59.050 mm; base_rail_bottom_left
service 1: 784.125 / 1134.200 mm; base_rail_service_lower_left service 2: 384.125 / 1134.200 mm; base_rail_service_lower_left

Future insert space is reserved only; no inserts installed or future insert pilots cut.

# main_upper_left — PANEL FASTENING AXES

FRONT / CLIMBING FACE: measure right from LEFT edge and up from BOTTOM edge; do not mirror.

Development layout: 12 screws on this panel; count does not establish resistance.
Coordinates below are panel-local millimeters. Drill axis is perpendicular to the panel.
SPAX XFT08P-2000 #8 x 2 inch: nominal 90-degree included head angle, 8.128 mm head diameter. Set a flush seat using the actual screw and a matched tool on an offcut; do not overdrive.
No full-shank pilot diameter or countersink machining depth is specified here.
Reference: docs/round-panel-countersink-reference.json (nominal US family drawing).

AXIS FROM LEFT FROM BOTTOM RECEIVER
rim 1: 19.050 / 59.050 mm; base_side_left
rim 2: 19.050 / 417.433 mm; base_side_left
rim 3: 19.050 / 775.817 mm; base_side_left
rim 4: 19.050 / 1134.200 mm; base_side_left
center 1: 1149.200 / 59.050 mm; base_principal_center_left center 2: 1149.200 / 417.433 mm; base_principal_center_left center 3: 1149.200 / 775.817 mm; base_principal_center_left center 4: 1149.200 / 1134.200 mm; base_principal_center_left edge 1: 784.125 / 1200.150 mm; base_rail_top
edge 2: 384.125 / 1200.150 mm; base_rail_top
service 1: 784.125 / 59.050 mm; base_rail_service_upper_left service 2: 384.125 / 59.050 mm; base_rail_service_upper_left

Future insert space is reserved only; no inserts installed or future insert pilots cut.

# kicker_left — PANEL FASTENING AXES

FRONT / CLIMBING FACE: measure right from LEFT edge and up from BOTTOM edge; do not mirror.

Development layout: 4 screws on this panel; count does not establish resistance.
Coordinates below are panel-local millimeters. Drill axis is perpendicular to the panel.
SPAX XFT08P-2000 #8 x 2 inch: nominal 90-degree included head angle, 8.128 mm head diameter. Set a flush seat using the actual screw and a matched tool on an offcut; do not overdrive.
No full-shank pilot diameter or countersink machining depth is specified here.
Reference: docs/round-panel-countersink-reference.json (nominal US family drawing).

AXIS FROM LEFT FROM BOTTOM RECEIVER
rim 1: 19.050 / 60.000 mm; base_post_outer_left
rim 2: 19.050 / 140.000 mm; base_post_outer_left center 1: 1149.200 / 60.000 mm; base_post_center_left center 2: 1149.200 / 140.000 mm; base_post_center_left

Future insert space is reserved only; no inserts installed or future insert pilots cut.

# main_lower_right — PANEL FASTENING AXES

FRONT / CLIMBING FACE: measure right from LEFT edge and up from BOTTOM edge; do not mirror.

Development layout: 12 screws on this panel; count does not establish resistance.
Coordinates below are panel-local millimeters. Drill axis is perpendicular to the panel.
SPAX XFT08P-2000 #8 x 2 inch: nominal 90-degree included head angle, 8.128 mm head diameter. Set a flush seat using the actual screw and a matched tool on an offcut; do not overdrive.
No full-shank pilot diameter or countersink machining depth is specified here.
Reference: docs/round-panel-countersink-reference.json (nominal US family drawing).

AXIS FROM LEFT FROM BOTTOM RECEIVER
rim 1: 1200.150 / 59.050 mm; base_side_right
rim 2: 1200.150 / 417.433 mm; base_side_right
rim 3: 1200.150 / 775.817 mm; base_side_right
rim 4: 1200.150 / 1134.200 mm; base_side_right
center 1: 70.000 / 59.050 mm; base_principal_center_right center 2: 70.000 / 417.433 mm; base_principal_center_right center 3: 70.000 / 775.817 mm; base_principal_center_right center 4: 70.000 / 1134.200 mm; base_principal_center_right edge 1: 435.075 / 59.050 mm; base_rail_bottom_right
edge 2: 835.075 / 59.050 mm; base_rail_bottom_right
service 1: 435.075 / 1134.200 mm; base_rail_service_lower_right service 2: 835.075 / 1134.200 mm; base_rail_service_lower_right

Future insert space is reserved only; no inserts installed or future insert pilots cut.

# main_upper_right — PANEL FASTENING AXES

FRONT / CLIMBING FACE: measure right from LEFT edge and up from BOTTOM edge; do not mirror.

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

AXIS FROM LEFT FROM BOTTOM RECEIVER
rim 1: 1200.150 / 59.050 mm; base_side_right
rim 2: 1200.150 / 417.433 mm; base_side_right
rim 3: 1200.150 / 775.817 mm; base_side_right
rim 4: 1200.150 / 1134.200 mm; base_side_right
center 1: 70.000 / 59.050 mm; base_principal_center_right center 2: 70.000 / 417.433 mm; base_principal_center_right center 3: 70.000 / 775.817 mm; base_principal_center_right center 4: 70.000 / 1134.200 mm; base_principal_center_right edge 1: 435.075 / 1200.150 mm; base_rail_top
edge 2: 835.075 / 1200.150 mm; base_rail_top
service 1: 435.075 / 59.050 mm; base_rail_service_upper_right service 2: 835.075 / 59.050 mm; base_rail_service_upper_right

Future insert space is reserved only; no inserts installed or future insert pilots cut.

# kicker_right — PANEL FASTENING AXES

FRONT / CLIMBING FACE: measure right from LEFT edge and up from BOTTOM edge; do not mirror.

Development layout: 4 screws on this panel; count does not establish resistance.
Coordinates below are panel-local millimeters. Drill axis is perpendicular to the panel.
SPAX XFT08P-2000 #8 x 2 inch: nominal 90-degree included head angle, 8.128 mm head diameter. Set a flush seat using the actual screw and a matched tool on an offcut; do not overdrive.
No full-shank pilot diameter or countersink machining depth is specified here.
Reference: docs/round-panel-countersink-reference.json (nominal US family drawing).

AXIS FROM LEFT FROM BOTTOM RECEIVER
rim 1: 1200.150 / 60.000 mm; base_post_outer_right
rim 2: 1200.150 / 140.000 mm; base_post_outer_right center 1: 70.000 / 60.000 mm; base_post_center_right center 2: 70.000 / 140.000 mm; base_post_center_right

Future insert space is reserved only; no inserts installed or future insert pilots cut.

# base_side_left — FOUR LEG-JOINT BORES

OUTER broad face, left side of assembled frame; drill +X, toward frame center.

Measure DOWN along grain from the TOP end.
Measure ACROSS from the named long edge:
panel-contact front edge.
Coordinates are per member; do not transfer a rim pattern onto its leg or mirror the opposite side. Nominal through clearance Ø11.1125 mm (7/16 in). Complete member thickness: 38.1 mm (1.5 in). Top/edge offsets below are hole CENTER distances. Outer face: smaller X on LEFT; larger X on RIGHT. Width arrow follows stated world axis; opposite outer-face views have opposite handedness.

LOCAL AXIS PROJECTION / ENLARGED HOLE REGION

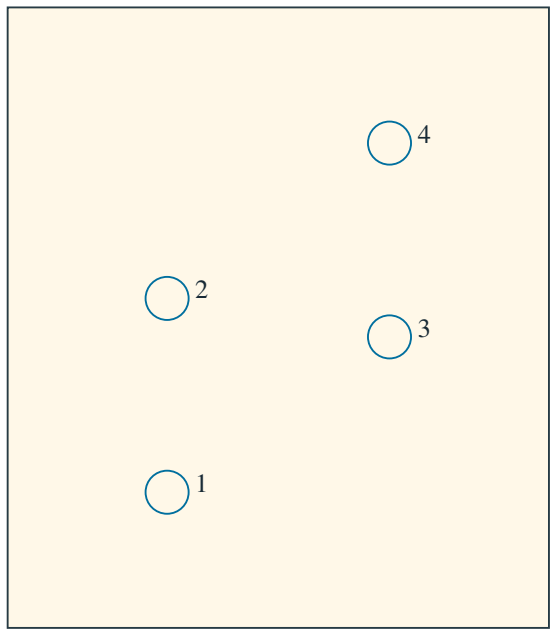
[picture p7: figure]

Width 139.700 mm; down-window starts 693.881 mm

HOLE / CONNECTION FROM TOP FROM LONG EDGE OPPOSITE EDGE NEAREST END (mm) 1 lumber_leg_bolt_left_1 818.952 41.152 98.548 818.952
2 lumber_leg_bolt_left_2 768.952 41.152 98.548 768.952
3 lumber_leg_bolt_left_3 778.881 98.548 41.152 778.881
4 lumber_leg_bolt_left_4 728.881 98.548 41.152 728.881

DOWN unit vector, world XYZ: [-0.0, -0.642788, -0.766044]
WIDTH unit vector, world XYZ: [0.0, -0.766044, 0.642788]
Dashed region is a detail window, not stock ends. End distances follow grain at each bore. These pages cover eight leg/rim bolt axes only. Panel screws are a separate schedule.

Leg joint: head OUTSIDE, nut INSIDE; retain one washer at each end.

# lumber_leg_left — FOUR LEG-JOINT BORES

OUTER broad face, left side of assembled frame; drill +X, toward frame center.

Measure DOWN along grain from the TOP end.
Measure ACROSS from the named long edge:
frontmost long edge (smaller world Y at a fixed leg station).
Coordinates are per member; do not transfer a rim
pattern onto its leg or mirror the opposite side.
Nominal through clearance Ø11.1125 mm (7/16 in). Complete member thickness: 38.1 mm (1.5 in). Top/edge offsets below are hole CENTER distances. Outer face: smaller X on LEFT; larger X on RIGHT. Width arrow follows stated world axis; opposite outer-face views have opposite handedness.

LOCAL AXIS PROJECTION / ENLARGED HOLE REGION

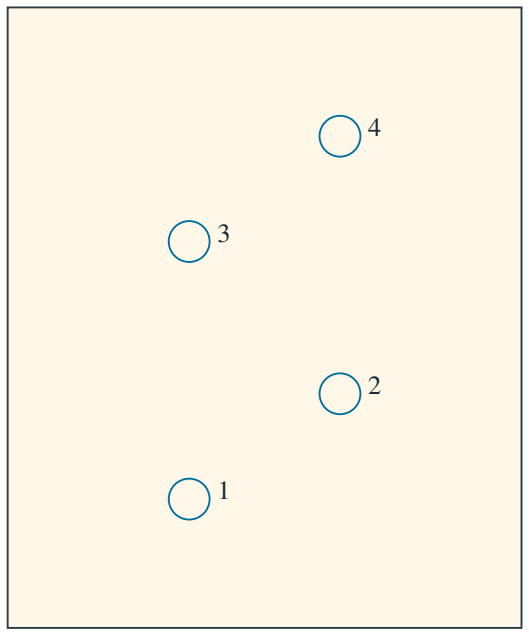
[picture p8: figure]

Width 139.700 mm; down-window starts 92.794 mm

HOLE / CONNECTION FROM TOP FROM LONG EDGE OPPOSITE EDGE NEAREST END (mm) 1 lumber_leg_bolt_left_1 226.416 49.351 90.349 226.416
2 lumber_leg_bolt_left_2 197.794 90.349 49.351 197.794
3 lumber_leg_bolt_left_3 156.416 49.351 90.349 156.416
4 lumber_leg_bolt_left_4 127.794 90.349 49.351 127.794

DOWN unit vector, world XYZ: [-0.0, 0.260157, -0.965566]
WIDTH unit vector, world XYZ: [0.0, 0.965566, 0.260157]
Dashed region is a detail window, not stock ends. End distances follow grain at each bore. These pages cover eight leg/rim bolt axes only. Panel screws are a separate schedule.

Leg joint: head OUTSIDE, nut INSIDE; retain one washer at each end.

# base_side_right — FOUR LEG-JOINT BORES

OUTER broad face, right side of assembled frame; drill -X, toward frame center.

Measure DOWN along grain from the TOP end.
Measure ACROSS from the named long edge:
panel-contact front edge.
Coordinates are per member; do not transfer a rim pattern onto its leg or mirror the opposite side. Nominal through clearance Ø11.1125 mm (7/16 in). Complete member thickness: 38.1 mm (1.5 in). Top/edge offsets below are hole CENTER distances. Outer face: smaller X on LEFT; larger X on RIGHT. Width arrow follows stated world axis; opposite outer-face views have opposite handedness.

LOCAL AXIS PROJECTION / ENLARGED HOLE REGION

Width 139.700 mm; down-window starts 693.881 mm

HOLE / CONNECTION FROM TOP FROM LONG EDGE OPPOSITE EDGE NEAREST END (mm) 1 lumber_leg_bolt_right_1 818.952 41.152 98.548 818.952
2 lumber_leg_bolt_right_2 768.952 41.152 98.548 768.952
3 lumber_leg_bolt_right_3 778.881 98.548 41.152 778.881
4 lumber_leg_bolt_right_4 728.881 98.548 41.152 728.881

DOWN unit vector, world XYZ: [-0.0, -0.642788, -0.766044]
WIDTH unit vector, world XYZ: [0.0, -0.766044, 0.642788]
Dashed region is a detail window, not stock ends. End distances follow grain at each bore. These pages cover eight leg/rim bolt axes only. Panel screws are a separate schedule.

Leg joint: head OUTSIDE, nut INSIDE; retain one washer at each end.

# lumber_leg_right — FOUR LEG-JOINT BORES

OUTER broad face, right side of assembled frame; drill -X, toward frame center.

Measure DOWN along grain from the TOP end.
Measure ACROSS from the named long edge:
frontmost long edge (smaller world Y at a fixed leg station).
Coordinates are per member; do not transfer a rim
pattern onto its leg or mirror the opposite side.
Nominal through clearance Ø11.1125 mm (7/16 in). Complete member thickness: 38.1 mm (1.5 in). Top/edge offsets below are hole CENTER distances. Outer face: smaller X on LEFT; larger X on RIGHT. Width arrow follows stated world axis; opposite outer-face views have opposite handedness.

LOCAL AXIS PROJECTION / ENLARGED HOLE REGION

Width 139.700 mm; down-window starts 92.794 mm

HOLE / CONNECTION FROM TOP FROM LONG EDGE OPPOSITE EDGE NEAREST END (mm) 1 lumber_leg_bolt_right_1 226.416 49.351 90.349 226.416
2 lumber_leg_bolt_right_2 197.794 90.349 49.351 197.794
3 lumber_leg_bolt_right_3 156.416 49.351 90.349 156.416
4 lumber_leg_bolt_right_4 127.794 90.349 49.351 127.794

DOWN unit vector, world XYZ: [-0.0, 0.260157, -0.965566]
WIDTH unit vector, world XYZ: [0.0, 0.965566, 0.260157]
Dashed region is a detail window, not stock ends. End distances follow grain at each bore. These pages cover eight leg/rim bolt axes only. Panel screws are a separate schedule.

Leg joint: head OUTSIDE, nut INSIDE; retain one washer at each end.

# bore_base_principal_center_left_060 — CIRCULAR STRAND PASSAGE

LEFT broad face; drill RIGHT along +X

LOCAL ENTRY-FACE PROJECTION; circle is not a template.

base_principal_center_left
LED segment: E12 → F12
Circular diameter: 38.100 mm.
THROUGH actual wood: 38.100 mm along stated axis.
Width datum: Member LOWER end, increasing S along slope. Center from width datum / opposite edge: 2292.915 / 181.100 mm.
Center from panel-contact FRONT / REAR face: 69.850 / 69.850 mm. Width offsets follow their axis at bore-center N; respect any oblique end cut. FRONT is N=0; depth increases INTO timber (+N).
No front-open slot, countersink or counterbore is specified.
Member entry XYZ (mm): [-89.05, 1341.177259, 1981.47472] Member exit XYZ (mm): [-50.95, 1341.177259, 1981.47472] Drill unit direction XYZ: [1.0, 0.0, 0.0]
Width unit direction XYZ: [0.0, 0.642788, 0.766044]
Local remaining wood, width low/high/front/rear (mm):
2273.865 / 162.050 / 50.800 / 50.800
Ligaments above are center-section checks, not a strength approval.
Oblique end cuts and the complete circular bore require the separate fit audit. Fit panels first; feed harness and install lights afterward.
Verify actual feeding access, bends and connector length before machining. Future insert space is reserved only; no future insert pilots cut.

# bore_base_principal_center_right_072 — CIRCULAR STRAND PASSAGE

LEFT broad face; drill RIGHT along +X

LOCAL ENTRY-FACE PROJECTION; circle is not a template.

base_principal_center_right
LED segment: F1 → G1
Circular diameter: 38.100 mm.
THROUGH actual wood: 38.100 mm along stated axis.
Width datum: Member LOWER end, increasing S along slope. Center from width datum / opposite edge: 92.915 / 2381.100 mm.
Center from panel-contact FRONT / REAR face: 69.850 / 69.850 mm. Width offsets follow their axis at bore-center N; respect any oblique end cut. FRONT is N=0; depth increases INTO timber (+N).
No front-open slot, countersink or counterbore is specified.
Member entry XYZ (mm): [50.95, -72.955482, 296.176945] Member exit XYZ (mm): [89.05, -72.955482, 296.176945] Drill unit direction XYZ: [1.0, 0.0, 0.0]
Width unit direction XYZ: [0.0, 0.642788, 0.766044] Local remaining wood, width low/high/front/rear (mm):
73.865 / 2362.050 / 50.800 / 50.800
Ligaments above are center-section checks, not a strength approval.
Oblique end cuts and the complete circular bore require the separate fit audit. Fit panels first; feed harness and install lights afterward.
Verify actual feeding access, bends and connector length before machining. Future insert space is reserved only; no future insert pilots cut.

# bore_base_rail_bottom_left_001 — CIRCULAR STRAND PASSAGE

LOWER station end face; drill UP along +S

LOCAL ENTRY-FACE PROJECTION; circle is not a template.

base_rail_bottom_left
LED segment: A1 → A2
Circular diameter: 38.100 mm.
THROUGH actual wood: 38.100 mm along stated axis.
Width datum: Member LEFT edge, increasing X.
Center from width datum / opposite edge: 191.900 / 900.150 mm.
Center from panel-contact FRONT / REAR face: 69.850 / 69.850 mm. Width offsets follow their axis at bore-center N; respect any oblique end cut. FRONT is N=0; depth increases INTO timber (+N).
No front-open slot, countersink or counterbore is specified.
Member entry XYZ (mm): [-989.2, -59.5855, 312.110669] Member exit XYZ (mm): [-989.2, -35.095292, 341.296963] Drill unit direction XYZ: [0.0, 0.642788, 0.766044]
Width unit direction XYZ: [1.0, 0.0, 0.0]
Local remaining wood, width low/high/front/rear (mm):
172.850 / 881.100 / 50.800 / 50.800
Ligaments above are center-section checks, not a strength approval.
Oblique end cuts and the complete circular bore require the separate fit audit. Fit panels first; feed harness and install lights afterward.
Verify actual feeding access, bends and connector length before machining. Future insert space is reserved only; no future insert pilots cut.

# bore_base_rail_bottom_left_023 — CIRCULAR STRAND PASSAGE

LOCAL ENTRY-FACE PROJECTION; circle is not a template.

base_rail_bottom_left
LED segment: B2 → B1
Circular diameter: 38.100 mm.
THROUGH actual wood: 38.100 mm along stated axis.
Width datum: Member LEFT edge, increasing X.
Center from width datum / opposite edge: 391.900 / 700.150 mm.
Center from panel-contact FRONT / REAR face: 69.850 / 69.850 mm. Width offsets follow their axis at bore-center N; respect any oblique end cut. FRONT is N=0; depth increases INTO timber (+N).
No front-open slot, countersink or counterbore is specified.
Member entry XYZ (mm): [-789.2, -59.5855, 312.110669] Member exit XYZ (mm): [-789.2, -35.095292, 341.296963] Drill unit direction XYZ: [0.0, 0.642788, 0.766044]
Width unit direction XYZ: [1.0, 0.0, 0.0]
Local remaining wood, width low/high/front/rear (mm):
372.850 / 681.100 / 50.800 / 50.800
Ligaments above are center-section checks, not a strength approval.
Oblique end cuts and the complete circular bore require the separate fit audit. Fit panels first; feed harness and install lights afterward.
Verify actual feeding access, bends and connector length before machining. Future insert space is reserved only; no future insert pilots cut.

# bore_base_rail_bottom_left_025 — CIRCULAR STRAND PASSAGE

LOCAL ENTRY-FACE PROJECTION; circle is not a template.

base_rail_bottom_left
LED segment: C1 → C2
Circular diameter: 38.100 mm.
THROUGH actual wood: 38.100 mm along stated axis.
Width datum: Member LEFT edge, increasing X.
Center from width datum / opposite edge: 591.900 / 500.150 mm.
Center from panel-contact FRONT / REAR face: 69.850 / 69.850 mm. Width offsets follow their axis at bore-center N; respect any oblique end cut. FRONT is N=0; depth increases INTO timber (+N).
No front-open slot, countersink or counterbore is specified.
Member entry XYZ (mm): [-589.2, -59.5855, 312.110669] Member exit XYZ (mm): [-589.2, -35.095292, 341.296963] Drill unit direction XYZ: [0.0, 0.642788, 0.766044]
Width unit direction XYZ: [1.0, 0.0, 0.0]
Local remaining wood, width low/high/front/rear (mm):
572.850 / 481.100 / 50.800 / 50.800
Ligaments above are center-section checks, not a strength approval.
Oblique end cuts and the complete circular bore require the separate fit audit. Fit panels first; feed harness and install lights afterward.
Verify actual feeding access, bends and connector length before machining. Future insert space is reserved only; no future insert pilots cut.

# bore_base_rail_bottom_left_047 — CIRCULAR STRAND PASSAGE

LOCAL ENTRY-FACE PROJECTION; circle is not a template.

base_rail_bottom_left
LED segment: D2 → D1
Circular diameter: 38.100 mm.
THROUGH actual wood: 38.100 mm along stated axis.
Width datum: Member LEFT edge, increasing X.
Center from width datum / opposite edge: 791.900 / 300.150 mm.
Center from panel-contact FRONT / REAR face: 69.850 / 69.850 mm. Width offsets follow their axis at bore-center N; respect any oblique end cut. FRONT is N=0; depth increases INTO timber (+N).
No front-open slot, countersink or counterbore is specified.
Member entry XYZ (mm): [-389.2, -59.5855, 312.110669] Member exit XYZ (mm): [-389.2, -35.095292, 341.296963] Drill unit direction XYZ: [0.0, 0.642788, 0.766044]
Width unit direction XYZ: [1.0, 0.0, 0.0]
Local remaining wood, width low/high/front/rear (mm):
772.850 / 281.100 / 50.800 / 50.800
Ligaments above are center-section checks, not a strength approval.
Oblique end cuts and the complete circular bore require the separate fit audit. Fit panels first; feed harness and install lights afterward.
Verify actual feeding access, bends and connector length before machining. Future insert space is reserved only; no future insert pilots cut.

# bore_base_rail_bottom_left_049 — CIRCULAR STRAND PASSAGE

LOCAL ENTRY-FACE PROJECTION; circle is not a template.

base_rail_bottom_left
LED segment: E1 → E2
Circular diameter: 38.100 mm.
THROUGH actual wood: 38.100 mm along stated axis.
Width datum: Member LEFT edge, increasing X.
Center from width datum / opposite edge: 991.900 / 100.150 mm.
Center from panel-contact FRONT / REAR face: 69.850 / 69.850 mm. Width offsets follow their axis at bore-center N; respect any oblique end cut. FRONT is N=0; depth increases INTO timber (+N).
No front-open slot, countersink or counterbore is specified.
Member entry XYZ (mm): [-189.2, -59.5855, 312.110669] Member exit XYZ (mm): [-189.2, -35.095292, 341.296963] Drill unit direction XYZ: [0.0, 0.642788, 0.766044]
Width unit direction XYZ: [1.0, 0.0, 0.0]
Local remaining wood, width low/high/front/rear (mm):
972.850 / 81.100 / 50.800 / 50.800
Ligaments above are center-section checks, not a strength approval.
Oblique end cuts and the complete circular bore require the separate fit audit. Fit panels first; feed harness and install lights afterward.
Verify actual feeding access, bends and connector length before machining. Future insert space is reserved only; no future insert pilots cut.

# bore_base_rail_service_lower_left_006 — CIRCULAR STRAND PASSAGE

LOCAL ENTRY-FACE PROJECTION; circle is not a template.

base_rail_service_lower_left
LED segment: A6 → A7
Circular diameter: 38.100 mm.
THROUGH actual wood: 38.100 mm along stated axis.
Width datum: Member LEFT edge, increasing X.
Center from width datum / opposite edge: 191.900 / 900.150 mm.
Center from panel-contact FRONT / REAR face: 69.850 / 69.850 mm. Width offsets follow their axis at bore-center N; respect any oblique end cut. FRONT is N=0; depth increases INTO timber (+N).
No front-open slot, countersink or counterbore is specified.
Member entry XYZ (mm): [-989.2, 631.507599, 1135.723352] Member exit XYZ (mm): [-989.2, 655.997807, 1164.909646] Drill unit direction XYZ: [0.0, 0.642788, 0.766044]
Width unit direction XYZ: [1.0, 0.0, 0.0]
Local remaining wood, width low/high/front/rear (mm):
172.850 / 881.100 / 50.800 / 50.800
Ligaments above are center-section checks, not a strength approval.
Oblique end cuts and the complete circular bore require the separate fit audit. Fit panels first; feed harness and install lights afterward.
Verify actual feeding access, bends and connector length before machining. Future insert space is reserved only; no future insert pilots cut.

# bore_base_rail_service_lower_left_018 — CIRCULAR STRAND PASSAGE

LOCAL ENTRY-FACE PROJECTION; circle is not a template.

base_rail_service_lower_left
LED segment: B7 → B6
Circular diameter: 38.100 mm.
THROUGH actual wood: 38.100 mm along stated axis.
Width datum: Member LEFT edge, increasing X.
Center from width datum / opposite edge: 391.900 / 700.150 mm.
Center from panel-contact FRONT / REAR face: 69.850 / 69.850 mm. Width offsets follow their axis at bore-center N; respect any oblique end cut. FRONT is N=0; depth increases INTO timber (+N).
No front-open slot, countersink or counterbore is specified.
Member entry XYZ (mm): [-789.2, 631.507599, 1135.723352] Member exit XYZ (mm): [-789.2, 655.997807, 1164.909646] Drill unit direction XYZ: [0.0, 0.642788, 0.766044]
Width unit direction XYZ: [1.0, 0.0, 0.0]
Local remaining wood, width low/high/front/rear (mm):
372.850 / 681.100 / 50.800 / 50.800
Ligaments above are center-section checks, not a strength approval.
Oblique end cuts and the complete circular bore require the separate fit audit. Fit panels first; feed harness and install lights afterward.
Verify actual feeding access, bends and connector length before machining. Future insert space is reserved only; no future insert pilots cut.

# bore_base_rail_service_lower_left_030 — CIRCULAR STRAND PASSAGE

LOCAL ENTRY-FACE PROJECTION; circle is not a template.

base_rail_service_lower_left
LED segment: C6 → C7
Circular diameter: 38.100 mm.
THROUGH actual wood: 38.100 mm along stated axis.
Width datum: Member LEFT edge, increasing X.
Center from width datum / opposite edge: 591.900 / 500.150 mm.
Center from panel-contact FRONT / REAR face: 69.850 / 69.850 mm. Width offsets follow their axis at bore-center N; respect any oblique end cut. FRONT is N=0; depth increases INTO timber (+N).
No front-open slot, countersink or counterbore is specified.
Member entry XYZ (mm): [-589.2, 631.507599, 1135.723352] Member exit XYZ (mm): [-589.2, 655.997807, 1164.909646] Drill unit direction XYZ: [0.0, 0.642788, 0.766044]
Width unit direction XYZ: [1.0, 0.0, 0.0]
Local remaining wood, width low/high/front/rear (mm):
572.850 / 481.100 / 50.800 / 50.800
Ligaments above are center-section checks, not a strength approval.
Oblique end cuts and the complete circular bore require the separate fit audit. Fit panels first; feed harness and install lights afterward.
Verify actual feeding access, bends and connector length before machining. Future insert space is reserved only; no future insert pilots cut.

# bore_base_rail_service_lower_left_042 — CIRCULAR STRAND PASSAGE

LOCAL ENTRY-FACE PROJECTION; circle is not a template.

base_rail_service_lower_left
LED segment: D7 → D6
Circular diameter: 38.100 mm.
THROUGH actual wood: 38.100 mm along stated axis.
Width datum: Member LEFT edge, increasing X.
Center from width datum / opposite edge: 791.900 / 300.150 mm.
Center from panel-contact FRONT / REAR face: 69.850 / 69.850 mm. Width offsets follow their axis at bore-center N; respect any oblique end cut. FRONT is N=0; depth increases INTO timber (+N).
No front-open slot, countersink or counterbore is specified.
Member entry XYZ (mm): [-389.2, 631.507599, 1135.723352] Member exit XYZ (mm): [-389.2, 655.997807, 1164.909646] Drill unit direction XYZ: [0.0, 0.642788, 0.766044]
Width unit direction XYZ: [1.0, 0.0, 0.0]
Local remaining wood, width low/high/front/rear (mm):
772.850 / 281.100 / 50.800 / 50.800
Ligaments above are center-section checks, not a strength approval.
Oblique end cuts and the complete circular bore require the separate fit audit. Fit panels first; feed harness and install lights afterward.
Verify actual feeding access, bends and connector length before machining. Future insert space is reserved only; no future insert pilots cut.

# bore_base_rail_service_lower_left_054 — CIRCULAR STRAND PASSAGE

LOCAL ENTRY-FACE PROJECTION; circle is not a template.

base_rail_service_lower_left
LED segment: E6 → E7
Circular diameter: 38.100 mm.
THROUGH actual wood: 38.100 mm along stated axis.
Width datum: Member LEFT edge, increasing X.
Center from width datum / opposite edge: 991.900 / 100.150 mm.
Center from panel-contact FRONT / REAR face: 69.850 / 69.850 mm. Width offsets follow their axis at bore-center N; respect any oblique end cut. FRONT is N=0; depth increases INTO timber (+N).
No front-open slot, countersink or counterbore is specified.
Member entry XYZ (mm): [-189.2, 631.507599, 1135.723352] Member exit XYZ (mm): [-189.2, 655.997807, 1164.909646] Drill unit direction XYZ: [0.0, 0.642788, 0.766044]
Width unit direction XYZ: [1.0, 0.0, 0.0]
Local remaining wood, width low/high/front/rear (mm):
972.850 / 81.100 / 50.800 / 50.800
Ligaments above are center-section checks, not a strength approval.
Oblique end cuts and the complete circular bore require the separate fit audit. Fit panels first; feed harness and install lights afterward.
Verify actual feeding access, bends and connector length before machining. Future insert space is reserved only; no future insert pilots cut.

# bore_base_rail_service_upper_left_007 — CIRCULAR STRAND PASSAGE

LOCAL ENTRY-FACE PROJECTION; circle is not a template.

base_rail_service_upper_left
LED segment: A7 → A8
Circular diameter: 38.100 mm.
THROUGH actual wood: 38.100 mm along stated axis.
Width datum: Member LEFT edge, increasing X.
Center from width datum / opposite edge: 191.900 / 900.150 mm.
Center from panel-contact FRONT / REAR face: 69.850 / 69.850 mm. Width offsets follow their axis at bore-center N; respect any oblique end cut. FRONT is N=0; depth increases INTO timber (+N).
No front-open slot, countersink or counterbore is specified.
Member entry XYZ (mm): [-989.2, 724.101154, 1246.072054] Member exit XYZ (mm): [-989.2, 748.591362, 1275.258348] Drill unit direction XYZ: [0.0, 0.642788, 0.766044]
Width unit direction XYZ: [1.0, 0.0, 0.0]
Local remaining wood, width low/high/front/rear (mm):
172.850 / 881.100 / 50.800 / 50.800
Ligaments above are center-section checks, not a strength approval.
Oblique end cuts and the complete circular bore require the separate fit audit. Fit panels first; feed harness and install lights afterward.
Verify actual feeding access, bends and connector length before machining. Future insert space is reserved only; no future insert pilots cut.

# bore_base_rail_service_upper_left_017 — CIRCULAR STRAND PASSAGE

LOCAL ENTRY-FACE PROJECTION; circle is not a template.

base_rail_service_upper_left
LED segment: B8 → B7
Circular diameter: 38.100 mm.
THROUGH actual wood: 38.100 mm along stated axis.
Width datum: Member LEFT edge, increasing X.
Center from width datum / opposite edge: 391.900 / 700.150 mm.
Center from panel-contact FRONT / REAR face: 69.850 / 69.850 mm. Width offsets follow their axis at bore-center N; respect any oblique end cut. FRONT is N=0; depth increases INTO timber (+N).
No front-open slot, countersink or counterbore is specified.
Member entry XYZ (mm): [-789.2, 724.101154, 1246.072054] Member exit XYZ (mm): [-789.2, 748.591362, 1275.258348] Drill unit direction XYZ: [0.0, 0.642788, 0.766044]
Width unit direction XYZ: [1.0, 0.0, 0.0]
Local remaining wood, width low/high/front/rear (mm):
372.850 / 681.100 / 50.800 / 50.800
Ligaments above are center-section checks, not a strength approval.
Oblique end cuts and the complete circular bore require the separate fit audit. Fit panels first; feed harness and install lights afterward.
Verify actual feeding access, bends and connector length before machining. Future insert space is reserved only; no future insert pilots cut.

# bore_base_rail_service_upper_left_031 — CIRCULAR STRAND PASSAGE

LOCAL ENTRY-FACE PROJECTION; circle is not a template.

base_rail_service_upper_left
LED segment: C7 → C8
Circular diameter: 38.100 mm.
THROUGH actual wood: 38.100 mm along stated axis.
Width datum: Member LEFT edge, increasing X.
Center from width datum / opposite edge: 591.900 / 500.150 mm.
Center from panel-contact FRONT / REAR face: 69.850 / 69.850 mm. Width offsets follow their axis at bore-center N; respect any oblique end cut. FRONT is N=0; depth increases INTO timber (+N).
No front-open slot, countersink or counterbore is specified.
Member entry XYZ (mm): [-589.2, 724.101154, 1246.072054] Member exit XYZ (mm): [-589.2, 748.591362, 1275.258348] Drill unit direction XYZ: [0.0, 0.642788, 0.766044]
Width unit direction XYZ: [1.0, 0.0, 0.0]
Local remaining wood, width low/high/front/rear (mm):
572.850 / 481.100 / 50.800 / 50.800
Ligaments above are center-section checks, not a strength approval.
Oblique end cuts and the complete circular bore require the separate fit audit. Fit panels first; feed harness and install lights afterward.
Verify actual feeding access, bends and connector length before machining. Future insert space is reserved only; no future insert pilots cut.

# bore_base_rail_service_upper_left_041 — CIRCULAR STRAND PASSAGE

LOCAL ENTRY-FACE PROJECTION; circle is not a template.

base_rail_service_upper_left
LED segment: D8 → D7
Circular diameter: 38.100 mm.
THROUGH actual wood: 38.100 mm along stated axis.
Width datum: Member LEFT edge, increasing X.
Center from width datum / opposite edge: 791.900 / 300.150 mm.
Center from panel-contact FRONT / REAR face: 69.850 / 69.850 mm. Width offsets follow their axis at bore-center N; respect any oblique end cut. FRONT is N=0; depth increases INTO timber (+N).
No front-open slot, countersink or counterbore is specified.
Member entry XYZ (mm): [-389.2, 724.101154, 1246.072054] Member exit XYZ (mm): [-389.2, 748.591362, 1275.258348] Drill unit direction XYZ: [0.0, 0.642788, 0.766044]
Width unit direction XYZ: [1.0, 0.0, 0.0]
Local remaining wood, width low/high/front/rear (mm):
772.850 / 281.100 / 50.800 / 50.800
Ligaments above are center-section checks, not a strength approval.
Oblique end cuts and the complete circular bore require the separate fit audit. Fit panels first; feed harness and install lights afterward.
Verify actual feeding access, bends and connector length before machining. Future insert space is reserved only; no future insert pilots cut.

# bore_base_rail_service_upper_left_055 — CIRCULAR STRAND PASSAGE

LOCAL ENTRY-FACE PROJECTION; circle is not a template.

base_rail_service_upper_left
LED segment: E7 → E8
Circular diameter: 38.100 mm.
THROUGH actual wood: 38.100 mm along stated axis.
Width datum: Member LEFT edge, increasing X.
Center from width datum / opposite edge: 991.900 / 100.150 mm.
Center from panel-contact FRONT / REAR face: 69.850 / 69.850 mm. Width offsets follow their axis at bore-center N; respect any oblique end cut. FRONT is N=0; depth increases INTO timber (+N).
No front-open slot, countersink or counterbore is specified.
Member entry XYZ (mm): [-189.2, 724.101154, 1246.072054] Member exit XYZ (mm): [-189.2, 748.591362, 1275.258348] Drill unit direction XYZ: [0.0, 0.642788, 0.766044]
Width unit direction XYZ: [1.0, 0.0, 0.0]
Local remaining wood, width low/high/front/rear (mm):
972.850 / 81.100 / 50.800 / 50.800
Ligaments above are center-section checks, not a strength approval.
Oblique end cuts and the complete circular bore require the separate fit audit. Fit panels first; feed harness and install lights afterward.
Verify actual feeding access, bends and connector length before machining. Future insert space is reserved only; no future insert pilots cut.

# bore_base_rail_bottom_right_073 — CIRCULAR STRAND PASSAGE

LOCAL ENTRY-FACE PROJECTION; circle is not a template.

base_rail_bottom_right
LED segment: G1 → G2
Circular diameter: 38.100 mm.
THROUGH actual wood: 38.100 mm along stated axis.
Width datum: Member LEFT edge, increasing X.
Center from width datum / opposite edge: 121.750 / 970.300 mm.
Center from panel-contact FRONT / REAR face: 69.850 / 69.850 mm. Width offsets follow their axis at bore-center N; respect any oblique end cut. FRONT is N=0; depth increases INTO timber (+N).
No front-open slot, countersink or counterbore is specified.
Member entry XYZ (mm): [210.8, -59.5855, 312.110669] Member exit XYZ (mm): [210.8, -35.095292, 341.296963] Drill unit direction XYZ: [0.0, 0.642788, 0.766044]
Width unit direction XYZ: [1.0, 0.0, 0.0]
Local remaining wood, width low/high/front/rear (mm):
102.700 / 951.250 / 50.800 / 50.800
Ligaments above are center-section checks, not a strength approval.
Oblique end cuts and the complete circular bore require the separate fit audit. Fit panels first; feed harness and install lights afterward.
Verify actual feeding access, bends and connector length before machining. Future insert space is reserved only; no future insert pilots cut.

# bore_base_rail_bottom_right_095 — CIRCULAR STRAND PASSAGE

LOCAL ENTRY-FACE PROJECTION; circle is not a template.

base_rail_bottom_right
LED segment: H2 → H1
Circular diameter: 38.100 mm.
THROUGH actual wood: 38.100 mm along stated axis.
Width datum: Member LEFT edge, increasing X.
Center from width datum / opposite edge: 321.750 / 770.300 mm.
Center from panel-contact FRONT / REAR face: 69.850 / 69.850 mm. Width offsets follow their axis at bore-center N; respect any oblique end cut. FRONT is N=0; depth increases INTO timber (+N).
No front-open slot, countersink or counterbore is specified.
Member entry XYZ (mm): [410.8, -59.5855, 312.110669] Member exit XYZ (mm): [410.8, -35.095292, 341.296963] Drill unit direction XYZ: [0.0, 0.642788, 0.766044]
Width unit direction XYZ: [1.0, 0.0, 0.0]
Local remaining wood, width low/high/front/rear (mm):
302.700 / 751.250 / 50.800 / 50.800
Ligaments above are center-section checks, not a strength approval.
Oblique end cuts and the complete circular bore require the separate fit audit. Fit panels first; feed harness and install lights afterward.
Verify actual feeding access, bends and connector length before machining. Future insert space is reserved only; no future insert pilots cut.

# bore_base_rail_bottom_right_097 — CIRCULAR STRAND PASSAGE

LOCAL ENTRY-FACE PROJECTION; circle is not a template.

base_rail_bottom_right
LED segment: I1 → I2
Circular diameter: 38.100 mm.
THROUGH actual wood: 38.100 mm along stated axis.
Width datum: Member LEFT edge, increasing X.
Center from width datum / opposite edge: 521.750 / 570.300 mm.
Center from panel-contact FRONT / REAR face: 69.850 / 69.850 mm. Width offsets follow their axis at bore-center N; respect any oblique end cut. FRONT is N=0; depth increases INTO timber (+N).
No front-open slot, countersink or counterbore is specified.
Member entry XYZ (mm): [610.8, -59.5855, 312.110669] Member exit XYZ (mm): [610.8, -35.095292, 341.296963] Drill unit direction XYZ: [0.0, 0.642788, 0.766044]
Width unit direction XYZ: [1.0, 0.0, 0.0]
Local remaining wood, width low/high/front/rear (mm):
502.700 / 551.250 / 50.800 / 50.800
Ligaments above are center-section checks, not a strength approval.
Oblique end cuts and the complete circular bore require the separate fit audit. Fit panels first; feed harness and install lights afterward.
Verify actual feeding access, bends and connector length before machining. Future insert space is reserved only; no future insert pilots cut.

# bore_base_rail_bottom_right_119 — CIRCULAR STRAND PASSAGE

LOCAL ENTRY-FACE PROJECTION; circle is not a template.

base_rail_bottom_right
LED segment: J2 → J1
Circular diameter: 38.100 mm.
THROUGH actual wood: 38.100 mm along stated axis.
Width datum: Member LEFT edge, increasing X.
Center from width datum / opposite edge: 721.750 / 370.300 mm.
Center from panel-contact FRONT / REAR face: 69.850 / 69.850 mm. Width offsets follow their axis at bore-center N; respect any oblique end cut. FRONT is N=0; depth increases INTO timber (+N).
No front-open slot, countersink or counterbore is specified.
Member entry XYZ (mm): [810.8, -59.5855, 312.110669] Member exit XYZ (mm): [810.8, -35.095292, 341.296963] Drill unit direction XYZ: [0.0, 0.642788, 0.766044]
Width unit direction XYZ: [1.0, 0.0, 0.0]
Local remaining wood, width low/high/front/rear (mm):
702.700 / 351.250 / 50.800 / 50.800
Ligaments above are center-section checks, not a strength approval.
Oblique end cuts and the complete circular bore require the separate fit audit. Fit panels first; feed harness and install lights afterward.
Verify actual feeding access, bends and connector length before machining. Future insert space is reserved only; no future insert pilots cut.

# bore_base_rail_bottom_right_121 — CIRCULAR STRAND PASSAGE

LOCAL ENTRY-FACE PROJECTION; circle is not a template.

base_rail_bottom_right
LED segment: K1 → K2
Circular diameter: 38.100 mm.
THROUGH actual wood: 38.100 mm along stated axis.
Width datum: Member LEFT edge, increasing X.
Center from width datum / opposite edge: 921.750 / 170.300 mm.
Center from panel-contact FRONT / REAR face: 69.850 / 69.850 mm. Width offsets follow their axis at bore-center N; respect any oblique end cut. FRONT is N=0; depth increases INTO timber (+N).
No front-open slot, countersink or counterbore is specified.
Member entry XYZ (mm): [1010.8, -59.5855, 312.110669] Member exit XYZ (mm): [1010.8, -35.095292, 341.296963] Drill unit direction XYZ: [0.0, 0.642788, 0.766044]
Width unit direction XYZ: [1.0, 0.0, 0.0]
Local remaining wood, width low/high/front/rear (mm):
902.700 / 151.250 / 50.800 / 50.800
Ligaments above are center-section checks, not a strength approval.
Oblique end cuts and the complete circular bore require the separate fit audit. Fit panels first; feed harness and install lights afterward.
Verify actual feeding access, bends and connector length before machining. Future insert space is reserved only; no future insert pilots cut.

# bore_base_rail_service_lower_right_078 — CIRCULAR STRAND PASSAGE

LOCAL ENTRY-FACE PROJECTION; circle is not a template.

base_rail_service_lower_right
LED segment: G6 → G7
Circular diameter: 38.100 mm.
THROUGH actual wood: 38.100 mm along stated axis.
Width datum: Member LEFT edge, increasing X.
Center from width datum / opposite edge: 121.750 / 970.300 mm.
Center from panel-contact FRONT / REAR face: 69.850 / 69.850 mm. Width offsets follow their axis at bore-center N; respect any oblique end cut. FRONT is N=0; depth increases INTO timber (+N).
No front-open slot, countersink or counterbore is specified.
Member entry XYZ (mm): [210.8, 631.507599, 1135.723352] Member exit XYZ (mm): [210.8, 655.997807, 1164.909646] Drill unit direction XYZ: [0.0, 0.642788, 0.766044]
Width unit direction XYZ: [1.0, 0.0, 0.0]
Local remaining wood, width low/high/front/rear (mm):
102.700 / 951.250 / 50.800 / 50.800
Ligaments above are center-section checks, not a strength approval.
Oblique end cuts and the complete circular bore require the separate fit audit. Fit panels first; feed harness and install lights afterward.
Verify actual feeding access, bends and connector length before machining. Future insert space is reserved only; no future insert pilots cut.

# bore_base_rail_service_lower_right_090 — CIRCULAR STRAND PASSAGE

LOCAL ENTRY-FACE PROJECTION; circle is not a template.

base_rail_service_lower_right
LED segment: H7 → H6
Circular diameter: 38.100 mm.
THROUGH actual wood: 38.100 mm along stated axis.
Width datum: Member LEFT edge, increasing X.
Center from width datum / opposite edge: 321.750 / 770.300 mm.
Center from panel-contact FRONT / REAR face: 69.850 / 69.850 mm. Width offsets follow their axis at bore-center N; respect any oblique end cut. FRONT is N=0; depth increases INTO timber (+N).
No front-open slot, countersink or counterbore is specified.
Member entry XYZ (mm): [410.8, 631.507599, 1135.723352] Member exit XYZ (mm): [410.8, 655.997807, 1164.909646] Drill unit direction XYZ: [0.0, 0.642788, 0.766044]
Width unit direction XYZ: [1.0, 0.0, 0.0]
Local remaining wood, width low/high/front/rear (mm):
302.700 / 751.250 / 50.800 / 50.800
Ligaments above are center-section checks, not a strength approval.
Oblique end cuts and the complete circular bore require the separate fit audit. Fit panels first; feed harness and install lights afterward.
Verify actual feeding access, bends and connector length before machining. Future insert space is reserved only; no future insert pilots cut.

# bore_base_rail_service_lower_right_102 — CIRCULAR STRAND PASSAGE

LOCAL ENTRY-FACE PROJECTION; circle is not a template.

base_rail_service_lower_right
LED segment: I6 → I7
Circular diameter: 38.100 mm.
THROUGH actual wood: 38.100 mm along stated axis.
Width datum: Member LEFT edge, increasing X.
Center from width datum / opposite edge: 521.750 / 570.300 mm.
Center from panel-contact FRONT / REAR face: 69.850 / 69.850 mm. Width offsets follow their axis at bore-center N; respect any oblique end cut. FRONT is N=0; depth increases INTO timber (+N).
No front-open slot, countersink or counterbore is specified.
Member entry XYZ (mm): [610.8, 631.507599, 1135.723352] Member exit XYZ (mm): [610.8, 655.997807, 1164.909646] Drill unit direction XYZ: [0.0, 0.642788, 0.766044]
Width unit direction XYZ: [1.0, 0.0, 0.0]
Local remaining wood, width low/high/front/rear (mm):
502.700 / 551.250 / 50.800 / 50.800
Ligaments above are center-section checks, not a strength approval.
Oblique end cuts and the complete circular bore require the separate fit audit. Fit panels first; feed harness and install lights afterward.
Verify actual feeding access, bends and connector length before machining. Future insert space is reserved only; no future insert pilots cut.

# bore_base_rail_service_lower_right_114 — CIRCULAR STRAND PASSAGE

LOCAL ENTRY-FACE PROJECTION; circle is not a template.

base_rail_service_lower_right
LED segment: J7 → J6
Circular diameter: 38.100 mm.
THROUGH actual wood: 38.100 mm along stated axis.
Width datum: Member LEFT edge, increasing X.
Center from width datum / opposite edge: 721.750 / 370.300 mm.
Center from panel-contact FRONT / REAR face: 69.850 / 69.850 mm. Width offsets follow their axis at bore-center N; respect any oblique end cut. FRONT is N=0; depth increases INTO timber (+N).
No front-open slot, countersink or counterbore is specified.
Member entry XYZ (mm): [810.8, 631.507599, 1135.723352] Member exit XYZ (mm): [810.8, 655.997807, 1164.909646] Drill unit direction XYZ: [0.0, 0.642788, 0.766044]
Width unit direction XYZ: [1.0, 0.0, 0.0]
Local remaining wood, width low/high/front/rear (mm):
702.700 / 351.250 / 50.800 / 50.800
Ligaments above are center-section checks, not a strength approval.
Oblique end cuts and the complete circular bore require the separate fit audit. Fit panels first; feed harness and install lights afterward.
Verify actual feeding access, bends and connector length before machining. Future insert space is reserved only; no future insert pilots cut.

# bore_base_rail_service_lower_right_126 — CIRCULAR STRAND PASSAGE

LOCAL ENTRY-FACE PROJECTION; circle is not a template.

base_rail_service_lower_right
LED segment: K6 → K7
Circular diameter: 38.100 mm.
THROUGH actual wood: 38.100 mm along stated axis.
Width datum: Member LEFT edge, increasing X.
Center from width datum / opposite edge: 921.750 / 170.300 mm.
Center from panel-contact FRONT / REAR face: 69.850 / 69.850 mm. Width offsets follow their axis at bore-center N; respect any oblique end cut. FRONT is N=0; depth increases INTO timber (+N).
No front-open slot, countersink or counterbore is specified.
Member entry XYZ (mm): [1010.8, 631.507599, 1135.723352] Member exit XYZ (mm): [1010.8, 655.997807, 1164.909646] Drill unit direction XYZ: [0.0, 0.642788, 0.766044]
Width unit direction XYZ: [1.0, 0.0, 0.0]
Local remaining wood, width low/high/front/rear (mm):
902.700 / 151.250 / 50.800 / 50.800
Ligaments above are center-section checks, not a strength approval.
Oblique end cuts and the complete circular bore require the separate fit audit. Fit panels first; feed harness and install lights afterward.
Verify actual feeding access, bends and connector length before machining. Future insert space is reserved only; no future insert pilots cut.

# bore_base_rail_service_upper_right_079 — CIRCULAR STRAND PASSAGE

LOCAL ENTRY-FACE PROJECTION; circle is not a template.

base_rail_service_upper_right
LED segment: G7 → G8
Circular diameter: 38.100 mm.
THROUGH actual wood: 38.100 mm along stated axis.
Width datum: Member LEFT edge, increasing X.
Center from width datum / opposite edge: 121.750 / 970.300 mm.
Center from panel-contact FRONT / REAR face: 69.850 / 69.850 mm. Width offsets follow their axis at bore-center N; respect any oblique end cut. FRONT is N=0; depth increases INTO timber (+N).
No front-open slot, countersink or counterbore is specified.
Member entry XYZ (mm): [210.8, 724.101154, 1246.072054] Member exit XYZ (mm): [210.8, 748.591362, 1275.258348] Drill unit direction XYZ: [0.0, 0.642788, 0.766044]
Width unit direction XYZ: [1.0, 0.0, 0.0]
Local remaining wood, width low/high/front/rear (mm):
102.700 / 951.250 / 50.800 / 50.800
Ligaments above are center-section checks, not a strength approval.
Oblique end cuts and the complete circular bore require the separate fit audit. Fit panels first; feed harness and install lights afterward.
Verify actual feeding access, bends and connector length before machining. Future insert space is reserved only; no future insert pilots cut.

# bore_base_rail_service_upper_right_089 — CIRCULAR STRAND PASSAGE

LOCAL ENTRY-FACE PROJECTION; circle is not a template.

base_rail_service_upper_right
LED segment: H8 → H7
Circular diameter: 38.100 mm.
THROUGH actual wood: 38.100 mm along stated axis.
Width datum: Member LEFT edge, increasing X.
Center from width datum / opposite edge: 321.750 / 770.300 mm.
Center from panel-contact FRONT / REAR face: 69.850 / 69.850 mm. Width offsets follow their axis at bore-center N; respect any oblique end cut. FRONT is N=0; depth increases INTO timber (+N).
No front-open slot, countersink or counterbore is specified.
Member entry XYZ (mm): [410.8, 724.101154, 1246.072054] Member exit XYZ (mm): [410.8, 748.591362, 1275.258348] Drill unit direction XYZ: [0.0, 0.642788, 0.766044]
Width unit direction XYZ: [1.0, 0.0, 0.0]
Local remaining wood, width low/high/front/rear (mm):
302.700 / 751.250 / 50.800 / 50.800
Ligaments above are center-section checks, not a strength approval.
Oblique end cuts and the complete circular bore require the separate fit audit. Fit panels first; feed harness and install lights afterward.
Verify actual feeding access, bends and connector length before machining. Future insert space is reserved only; no future insert pilots cut.

# bore_base_rail_service_upper_right_103 — CIRCULAR STRAND PASSAGE

LOCAL ENTRY-FACE PROJECTION; circle is not a template.

base_rail_service_upper_right
LED segment: I7 → I8
Circular diameter: 38.100 mm.
THROUGH actual wood: 38.100 mm along stated axis.
Width datum: Member LEFT edge, increasing X.
Center from width datum / opposite edge: 521.750 / 570.300 mm.
Center from panel-contact FRONT / REAR face: 69.850 / 69.850 mm. Width offsets follow their axis at bore-center N; respect any oblique end cut. FRONT is N=0; depth increases INTO timber (+N).
No front-open slot, countersink or counterbore is specified.
Member entry XYZ (mm): [610.8, 724.101154, 1246.072054] Member exit XYZ (mm): [610.8, 748.591362, 1275.258348] Drill unit direction XYZ: [0.0, 0.642788, 0.766044]
Width unit direction XYZ: [1.0, 0.0, 0.0]
Local remaining wood, width low/high/front/rear (mm):
502.700 / 551.250 / 50.800 / 50.800
Ligaments above are center-section checks, not a strength approval.
Oblique end cuts and the complete circular bore require the separate fit audit. Fit panels first; feed harness and install lights afterward.
Verify actual feeding access, bends and connector length before machining. Future insert space is reserved only; no future insert pilots cut.

# bore_base_rail_service_upper_right_113 — CIRCULAR STRAND PASSAGE

LOCAL ENTRY-FACE PROJECTION; circle is not a template.

base_rail_service_upper_right
LED segment: J8 → J7
Circular diameter: 38.100 mm.
THROUGH actual wood: 38.100 mm along stated axis.
Width datum: Member LEFT edge, increasing X.
Center from width datum / opposite edge: 721.750 / 370.300 mm.
Center from panel-contact FRONT / REAR face: 69.850 / 69.850 mm. Width offsets follow their axis at bore-center N; respect any oblique end cut. FRONT is N=0; depth increases INTO timber (+N).
No front-open slot, countersink or counterbore is specified.
Member entry XYZ (mm): [810.8, 724.101154, 1246.072054] Member exit XYZ (mm): [810.8, 748.591362, 1275.258348] Drill unit direction XYZ: [0.0, 0.642788, 0.766044]
Width unit direction XYZ: [1.0, 0.0, 0.0]
Local remaining wood, width low/high/front/rear (mm):
702.700 / 351.250 / 50.800 / 50.800
Ligaments above are center-section checks, not a strength approval.
Oblique end cuts and the complete circular bore require the separate fit audit. Fit panels first; feed harness and install lights afterward.
Verify actual feeding access, bends and connector length before machining. Future insert space is reserved only; no future insert pilots cut.

# bore_base_rail_service_upper_right_127 — CIRCULAR STRAND PASSAGE

LOCAL ENTRY-FACE PROJECTION; circle is not a template.

base_rail_service_upper_right
LED segment: K7 → K8
Circular diameter: 38.100 mm.
THROUGH actual wood: 38.100 mm along stated axis.
Width datum: Member LEFT edge, increasing X.
Center from width datum / opposite edge: 921.750 / 170.300 mm.
Center from panel-contact FRONT / REAR face: 69.850 / 69.850 mm. Width offsets follow their axis at bore-center N; respect any oblique end cut. FRONT is N=0; depth increases INTO timber (+N).
No front-open slot, countersink or counterbore is specified.
Member entry XYZ (mm): [1010.8, 724.101154, 1246.072054] Member exit XYZ (mm): [1010.8, 748.591362, 1275.258348] Drill unit direction XYZ: [0.0, 0.642788, 0.766044]
Width unit direction XYZ: [1.0, 0.0, 0.0]
Local remaining wood, width low/high/front/rear (mm):
902.700 / 151.250 / 50.800 / 50.800
Ligaments above are center-section checks, not a strength approval.
Oblique end cuts and the complete circular bore require the separate fit audit. Fit panels first; feed harness and install lights afterward.
Verify actual feeding access, bends and connector length before machining. Future insert space is reserved only; no future insert pilots cut.

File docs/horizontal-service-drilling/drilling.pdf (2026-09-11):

## main_lower_left — HOLD / LED DRILLING

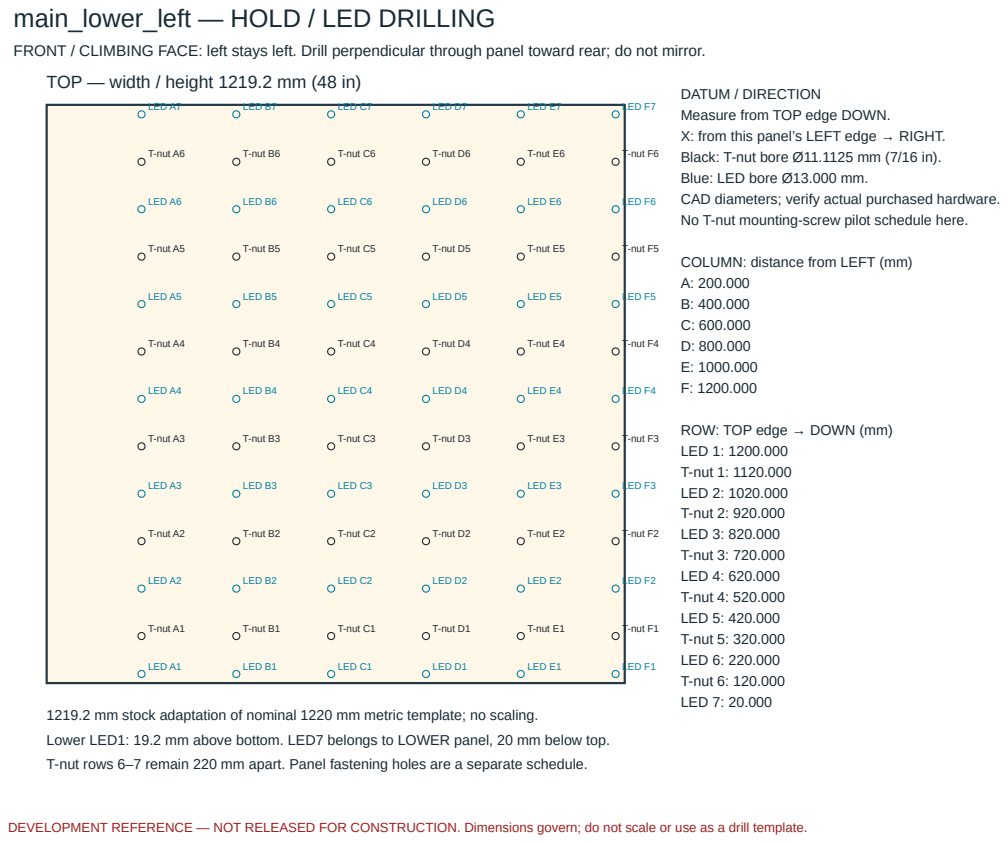
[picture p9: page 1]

FRONT / CLIMBING FACE: left stays left. Drill perpendicular through panel toward rear; do not mirror.
TOP — width / height 1219.2 mm (48 in)

DATUM / DIRECTION
Measure from TOP edge DOWN.
X: from this panel’s LEFT edge → RIGHT.
Black: T-nut bore Ø11.1125 mm (7/16 in).
Blue: LED bore Ø13.000 mm.
CAD diameters; verify actual purchased hardware.
No T-nut mounting-screw pilot schedule here.

1219.2 mm stock adaptation of nominal 1220 mm metric template; no scaling.
Lower LED1: 19.2 mm above bottom. LED7 belongs to LOWER panel, 20 mm below top.
T-nut rows 6–7 remain 220 mm apart. Panel fastening holes are a separate schedule.

DEVELOPMENT REFERENCE — NOT RELEASED FOR CONSTRUCTION. Dimensions govern; do not scale or use as a drill template.

## main_lower_right — HOLD / LED DRILLING

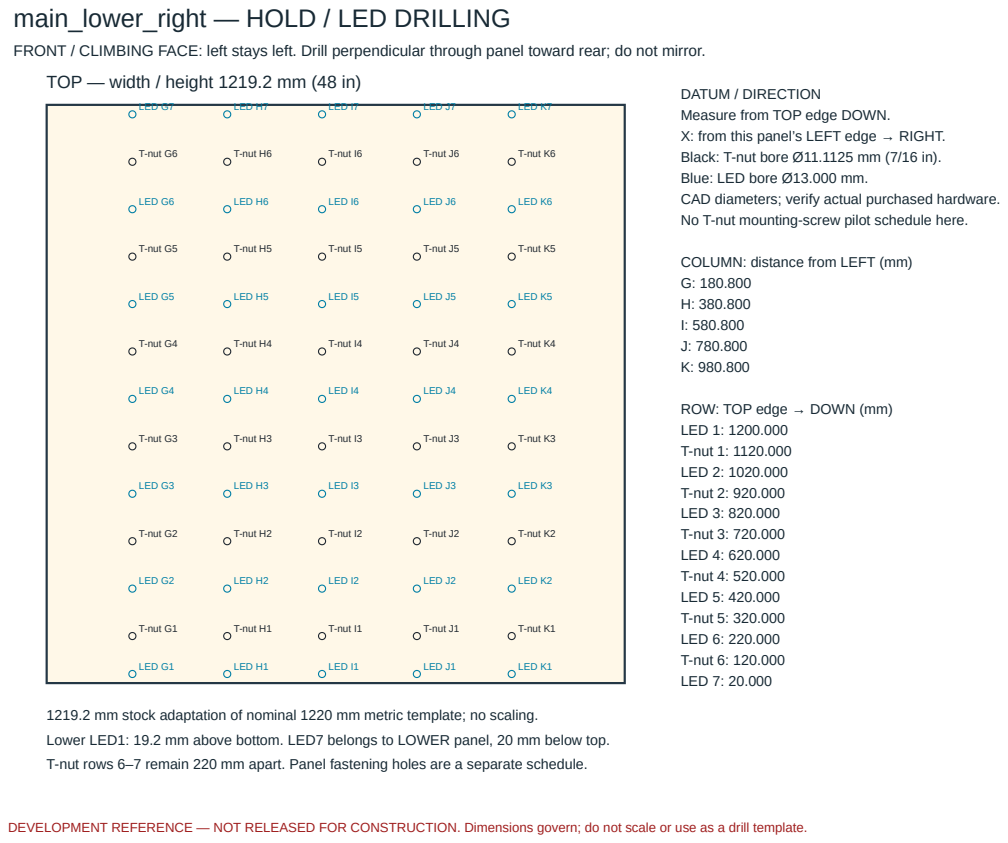
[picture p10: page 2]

FRONT / CLIMBING FACE: left stays left. Drill perpendicular through panel toward rear; do not mirror.
TOP — width / height 1219.2 mm (48 in)

DATUM / DIRECTION
Measure from TOP edge DOWN.
X: from this panel’s LEFT edge → RIGHT.
Black: T-nut bore Ø11.1125 mm (7/16 in).
Blue: LED bore Ø13.000 mm.
CAD diameters; verify actual purchased hardware.
No T-nut mounting-screw pilot schedule here.

1219.2 mm stock adaptation of nominal 1220 mm metric template; no scaling.
Lower LED1: 19.2 mm above bottom. LED7 belongs to LOWER panel, 20 mm below top.
T-nut rows 6–7 remain 220 mm apart. Panel fastening holes are a separate schedule.

## main_upper_left — HOLD / LED DRILLING

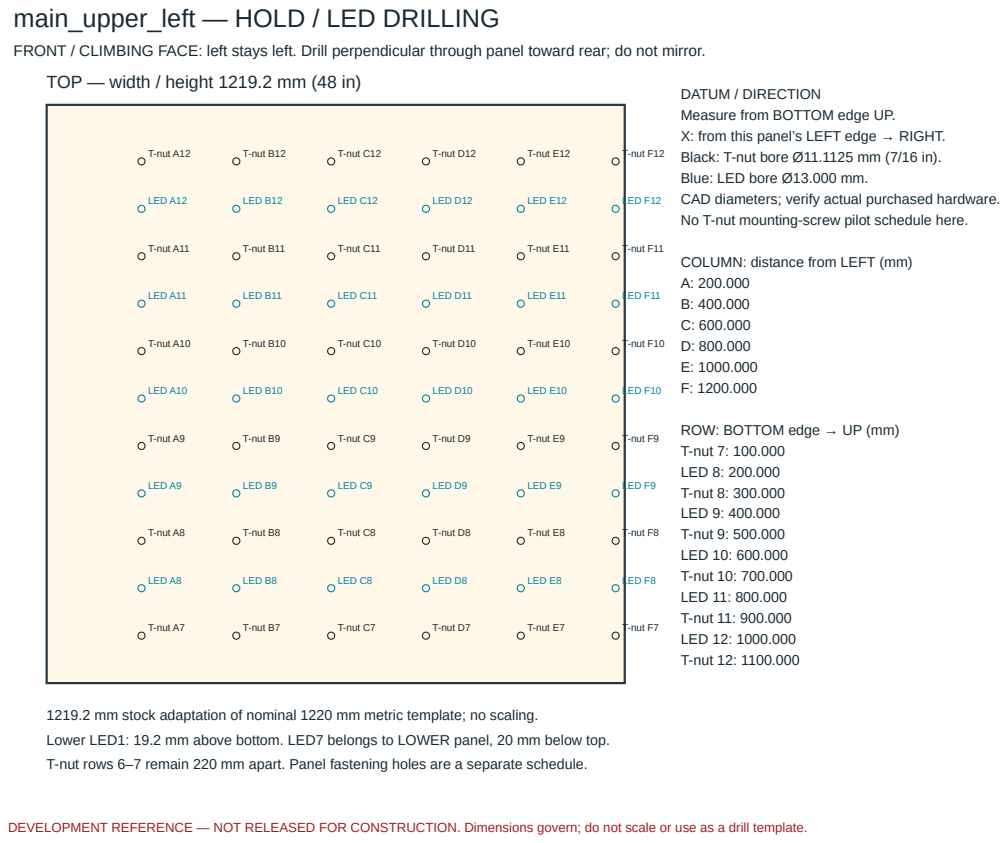
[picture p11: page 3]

FRONT / CLIMBING FACE: left stays left. Drill perpendicular through panel toward rear; do not mirror.
TOP — width / height 1219.2 mm (48 in)

DATUM / DIRECTION
Measure from BOTTOM edge UP.
X: from this panel’s LEFT edge → RIGHT.
Black: T-nut bore Ø11.1125 mm (7/16 in).
Blue: LED bore Ø13.000 mm.
CAD diameters; verify actual purchased hardware.
No T-nut mounting-screw pilot schedule here.

1219.2 mm stock adaptation of nominal 1220 mm metric template; no scaling.
Lower LED1: 19.2 mm above bottom. LED7 belongs to LOWER panel, 20 mm below top.
T-nut rows 6–7 remain 220 mm apart. Panel fastening holes are a separate schedule.

## main_upper_right — HOLD / LED DRILLING

FRONT / CLIMBING FACE: left stays left. Drill perpendicular through panel toward rear; do not mirror. TOP — width / height 1219.2 mm (48 in)
DATUM / DIRECTION
Measure from BOTTOM edge UP.
X: from this panel’s LEFT edge → RIGHT.
Black: T-nut bore Ø11.1125 mm (7/16 in).
Blue: LED bore Ø13.000 mm.
CAD diameters; verify actual purchased hardware. No T-nut mounting-screw pilot schedule here.

COLUMN: distance from LEFT (mm)
G: 180.800
H: 380.800
I: 580.800
J: 780.800
K: 980.800

ROW: BOTTOM edge → UP (mm) T-nut 7: 100.000
LED 8: 200.000
T-nut 8: 300.000
LED 9: 400.000
T-nut 9: 500.000
LED 10: 600.000
T-nut 10: 700.000
LED 11: 800.000
T-nut 11: 900.000
LED 12: 1000.000
T-nut 12: 1100.000

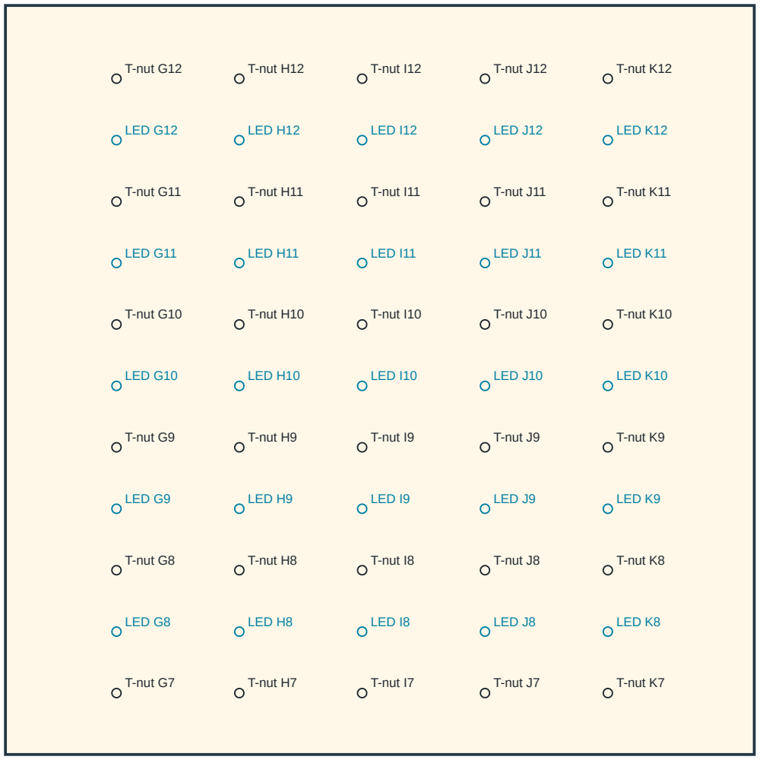
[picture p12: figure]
T-nut G7; T-nut G8; T-nut G9; T-nut G10; T-nut G11; T-nut G12; T-nut H7; T-nut H8; T-nut H9; T-nut H10; T-nut H11; T-nut H12; T-nut I7; T-nut I8; T-nut I9; T-nut I10; T-nut I11; T-nut I12; T-nut J7; T-nut J8; T-nut J9; T-nut J10; T-nut J11; T-nut J12; T-nut K7; T-nut K8; T-nut K9; T-nut K10; T-nut K11; T-nut K12; LED G8; LED G9; LED G10; LED G11; LED G12; LED H8; LED H9; LED H10; LED H11; LED H12; LED I8; LED I9; LED I10; LED I11; LED I12; LED J8; LED J9; LED J10; LED J11; LED J12; LED K8; LED K9; LED K10; LED K11; LED K12

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

## base_side_left — FOUR LEG-JOINT BORES

OUTER broad face, left side of assembled frame; drill +X, toward frame center.

Measure DOWN along grain from the TOP end.
Measure ACROSS from the named long edge:
panel-contact front edge.
Coordinates are per member; do not transfer a rim pattern onto its leg or mirror the opposite side. Nominal through clearance Ø11.1125 mm (7/16 in). Complete member thickness: 38.1 mm (1.5 in). Top/edge offsets below are hole CENTER distances. Outer face: smaller X on LEFT; larger X on RIGHT. Width arrow follows stated world axis; opposite outer-face views have opposite handedness.

LOCAL AXIS PROJECTION / ENLARGED HOLE REGION

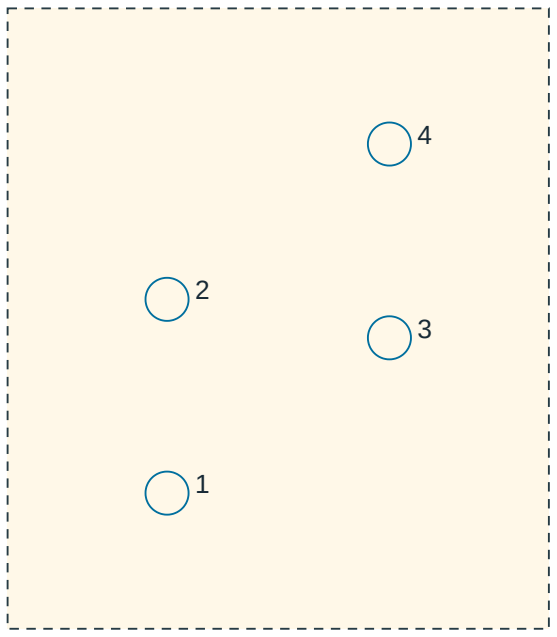
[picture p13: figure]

Width 139.700 mm; down-window starts 693.881 mm

HOLE / CONNECTION FROM TOP FROM LONG EDGE OPPOSITE EDGE NEAREST END (mm) 1 lumber_leg_bolt_left_1 818.952 41.152 98.548 818.952
2 lumber_leg_bolt_left_2 768.952 41.152 98.548 768.952
3 lumber_leg_bolt_left_3 778.881 98.548 41.152 778.881
4 lumber_leg_bolt_left_4 728.881 98.548 41.152 728.881

DOWN unit vector, world XYZ: [-0.0, -0.642788, -0.766044]
WIDTH unit vector, world XYZ: [0.0, -0.766044, 0.642788]
Dashed region is a detail window, not stock ends. End distances follow grain at each bore. These pages cover eight leg/rim bolt axes only. Panel screws are a separate schedule.

## lumber_leg_left — FOUR LEG-JOINT BORES

OUTER broad face, left side of assembled frame; drill +X, toward frame center.

Measure DOWN along grain from the TOP end.
Measure ACROSS from the named long edge:
frontmost long edge (smaller world Y at a fixed leg station).
Coordinates are per member; do not transfer a rim pattern onto its leg or mirror the opposite side.
Nominal through clearance Ø11.1125 mm (7/16 in). Complete member thickness: 38.1 mm (1.5 in). Top/edge offsets below are hole CENTER distances. Outer face: smaller X on LEFT; larger X on RIGHT. Width arrow follows stated world axis; opposite outer-face views have opposite handedness.

LOCAL AXIS PROJECTION / ENLARGED HOLE REGION

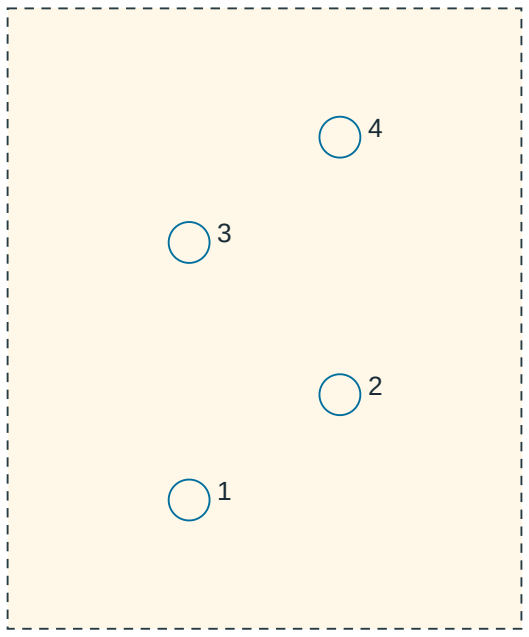
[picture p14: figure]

Width 139.700 mm; down-window starts 92.794 mm

HOLE / CONNECTION FROM TOP FROM LONG EDGE OPPOSITE EDGE NEAREST END (mm) 1 lumber_leg_bolt_left_1 226.416 49.351 90.349 226.416
2 lumber_leg_bolt_left_2 197.794 90.349 49.351 197.794
3 lumber_leg_bolt_left_3 156.416 49.351 90.349 156.416
4 lumber_leg_bolt_left_4 127.794 90.349 49.351 127.794

DOWN unit vector, world XYZ: [-0.0, 0.260157, -0.965566]
WIDTH unit vector, world XYZ: [0.0, 0.965566, 0.260157]
Dashed region is a detail window, not stock ends. End distances follow grain at each bore. These pages cover eight leg/rim bolt axes only. Panel screws are a separate schedule.

## base_side_right — FOUR LEG-JOINT BORES

OUTER broad face, right side of assembled frame; drill -X, toward frame center.

Measure DOWN along grain from the TOP end.
Measure ACROSS from the named long edge:
panel-contact front edge.
Coordinates are per member; do not transfer a rim pattern onto its leg or mirror the opposite side. Nominal through clearance Ø11.1125 mm (7/16 in). Complete member thickness: 38.1 mm (1.5 in). Top/edge offsets below are hole CENTER distances. Outer face: smaller X on LEFT; larger X on RIGHT. Width arrow follows stated world axis; opposite outer-face views have opposite handedness.

LOCAL AXIS PROJECTION / ENLARGED HOLE REGION

Width 139.700 mm; down-window starts 693.881 mm

HOLE / CONNECTION FROM TOP FROM LONG EDGE OPPOSITE EDGE NEAREST END (mm) 1 lumber_leg_bolt_right_1 818.952 41.152 98.548 818.952
2 lumber_leg_bolt_right_2 768.952 41.152 98.548 768.952
3 lumber_leg_bolt_right_3 778.881 98.548 41.152 778.881
4 lumber_leg_bolt_right_4 728.881 98.548 41.152 728.881

DOWN unit vector, world XYZ: [-0.0, -0.642788, -0.766044]
WIDTH unit vector, world XYZ: [0.0, -0.766044, 0.642788]
Dashed region is a detail window, not stock ends. End distances follow grain at each bore. These pages cover eight leg/rim bolt axes only. Panel screws are a separate schedule.

## lumber_leg_right — FOUR LEG-JOINT BORES

OUTER broad face, right side of assembled frame; drill -X, toward frame center.

Measure DOWN along grain from the TOP end.
Measure ACROSS from the named long edge:
frontmost long edge (smaller world Y at a fixed leg station).
Coordinates are per member; do not transfer a rim pattern onto its leg or mirror the opposite side.
Nominal through clearance Ø11.1125 mm (7/16 in). Complete member thickness: 38.1 mm (1.5 in). Top/edge offsets below are hole CENTER distances. Outer face: smaller X on LEFT; larger X on RIGHT. Width arrow follows stated world axis; opposite outer-face views have opposite handedness.

LOCAL AXIS PROJECTION / ENLARGED HOLE REGION

Width 139.700 mm; down-window starts 92.794 mm

HOLE / CONNECTION FROM TOP FROM LONG EDGE OPPOSITE EDGE NEAREST END (mm) 1 lumber_leg_bolt_right_1 226.416 49.351 90.349 226.416
2 lumber_leg_bolt_right_2 197.794 90.349 49.351 197.794
3 lumber_leg_bolt_right_3 156.416 49.351 90.349 156.416
4 lumber_leg_bolt_right_4 127.794 90.349 49.351 127.794

DOWN unit vector, world XYZ: [-0.0, 0.260157, -0.965566]
WIDTH unit vector, world XYZ: [0.0, 0.965566, 0.260157]
Dashed region is a detail window, not stock ends. End distances follow grain at each bore. These pages cover eight leg/rim bolt axes only. Panel screws are a separate schedule.
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

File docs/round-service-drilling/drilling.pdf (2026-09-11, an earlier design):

# main_lower_left — HOLD / LED DRILLING


FRONT / CLIMBING FACE: left stays left. Drill perpendicular through panel toward rear; do not mirror.
TOP — width / height 1219.2 mm (48 in)

DATUM / DIRECTION
Measure from TOP edge DOWN.
X: from this panel’s LEFT edge → RIGHT.
Black: T-nut bore Ø11.1125 mm (7/16 in).
Blue: LED bore Ø13.000 mm.
CAD diameters; verify actual purchased hardware.
No T-nut mounting-screw pilot schedule here.

1219.2 mm stock adaptation of nominal 1220 mm metric template; no scaling.
Lower LED1: 19.2 mm above bottom. LED7 belongs to LOWER panel, 20 mm below top.
T-nut rows 6–7 remain 220 mm apart. Panel fastening holes are a separate schedule.

DEVELOPMENT REFERENCE — NOT RELEASED FOR CONSTRUCTION. Dimensions govern; do not scale or use as a drill template.
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

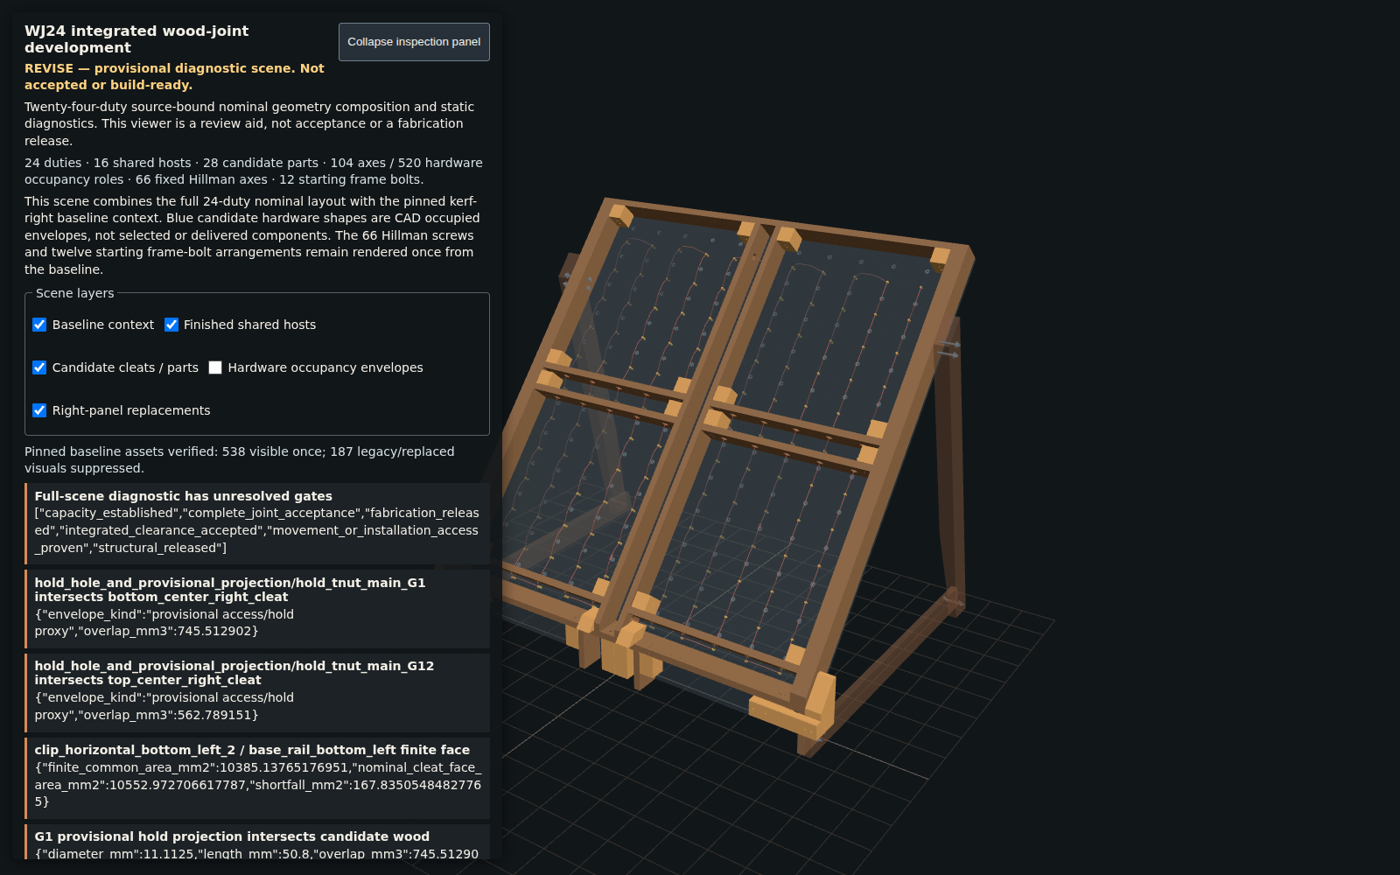
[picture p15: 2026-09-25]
docs/wood-joints-mvp/hypotheses/wj24-viewer-review/browser-evidence/final/layer-candidate_hardware-hidden.png

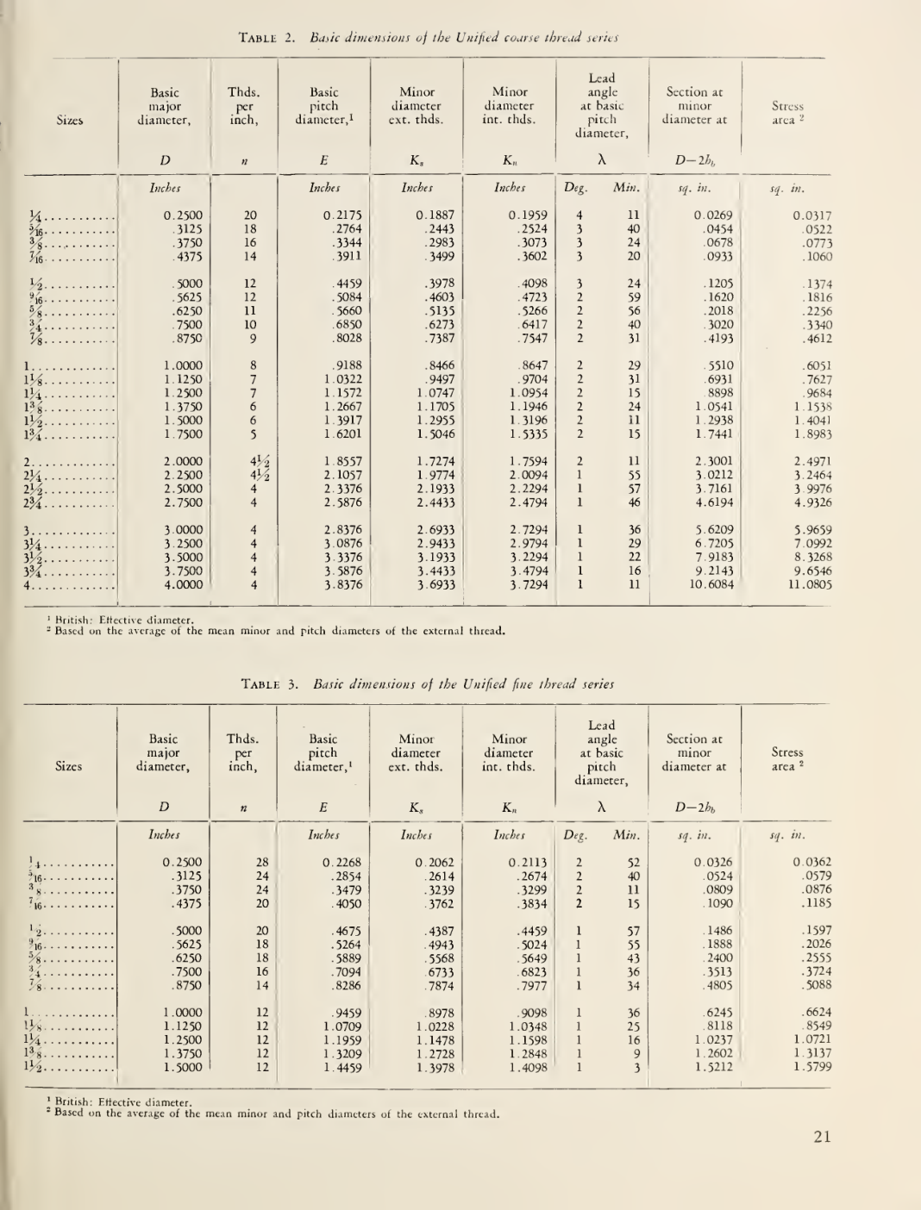
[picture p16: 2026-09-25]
docs/wood-joints-mvp/hypotheses/wj04-mechanics-hardware/nbs-table2-parent-render.png

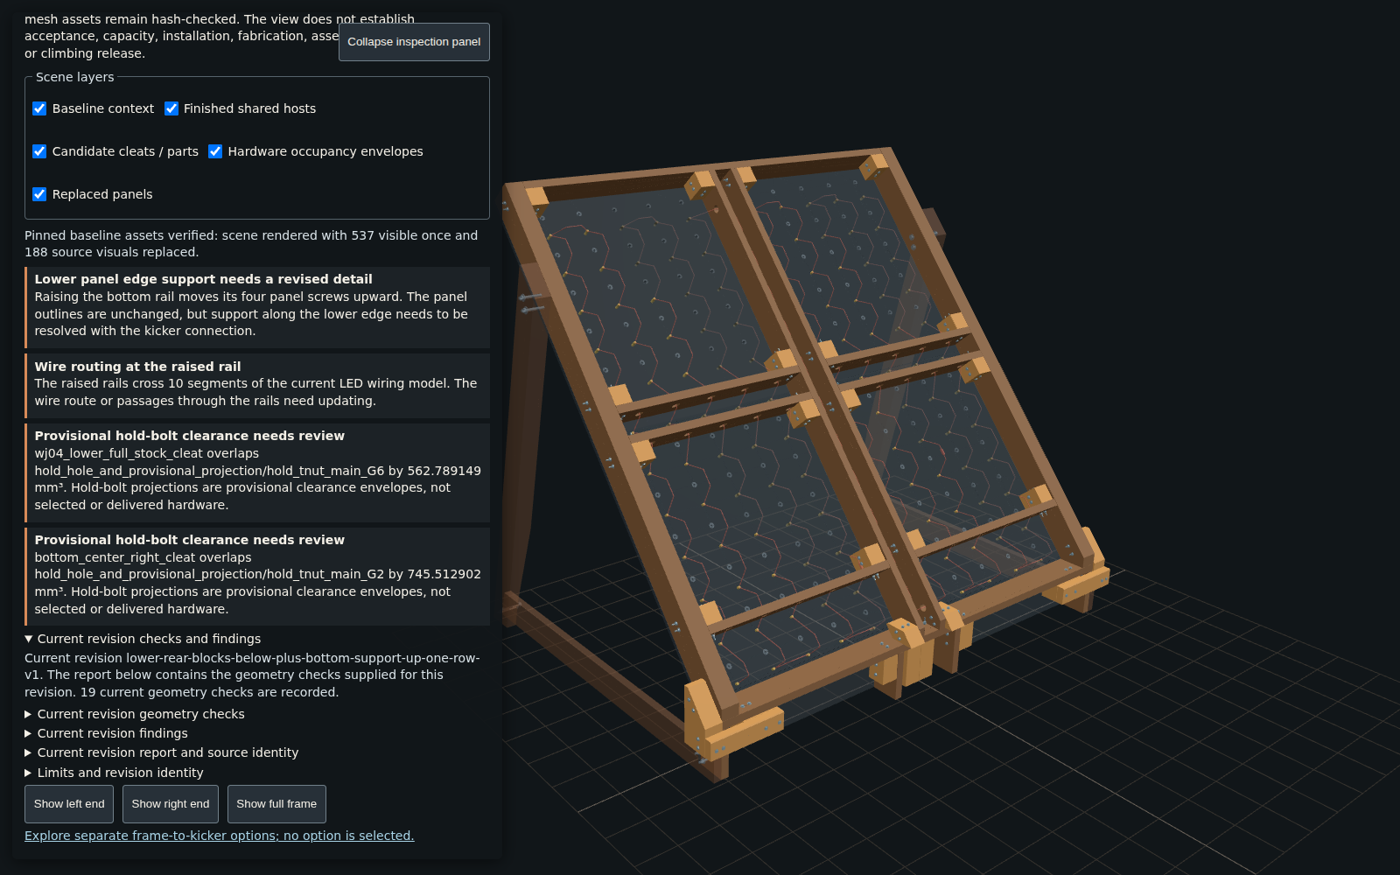
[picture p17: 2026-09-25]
docs/wood-joints-mvp/hypotheses/wj24-owner-design-review-2026-09-24/browser-evidence/desktop-left-end.png

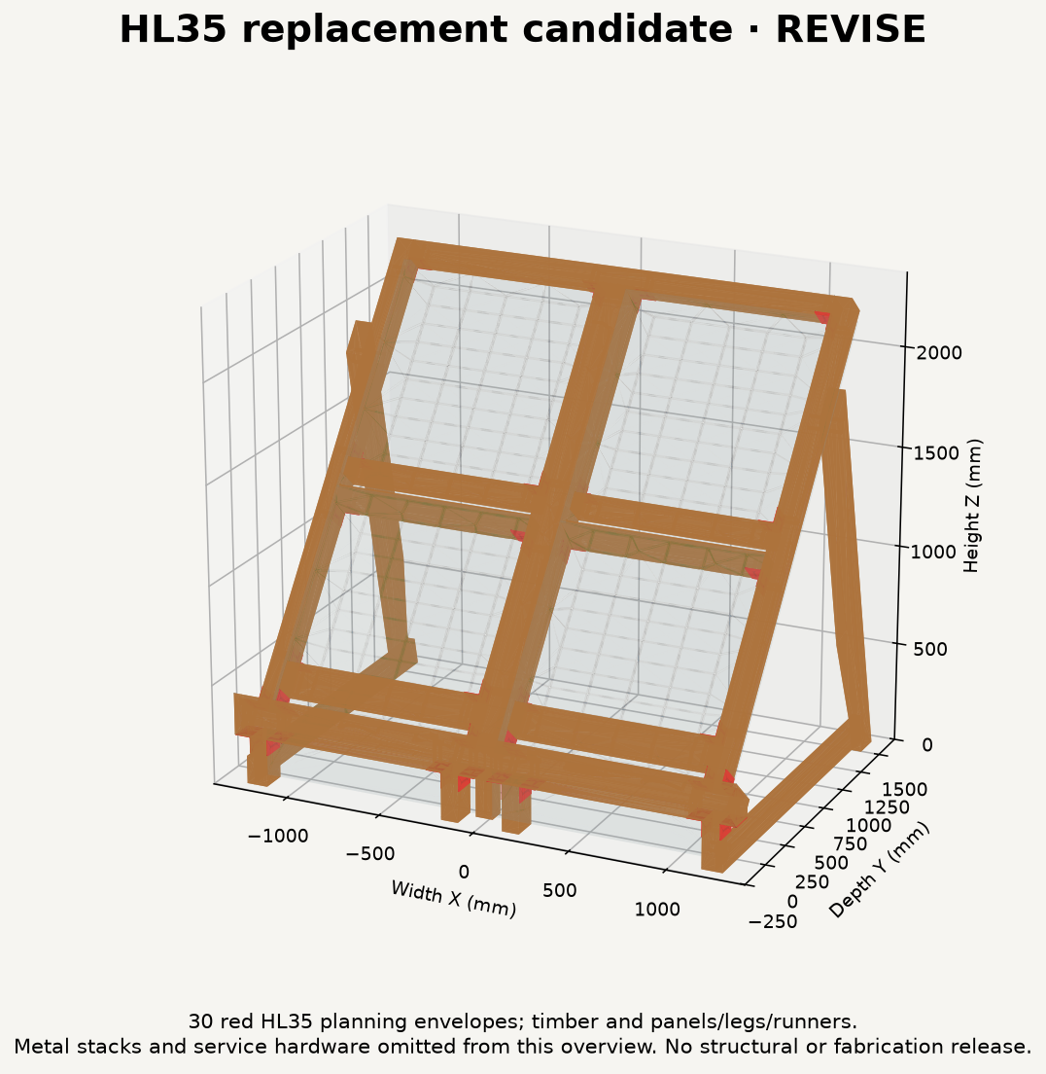
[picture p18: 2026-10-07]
docs/wood-joints-mvp/hypotheses/hl35-candidate/counterbore-fit-v8/overview.png

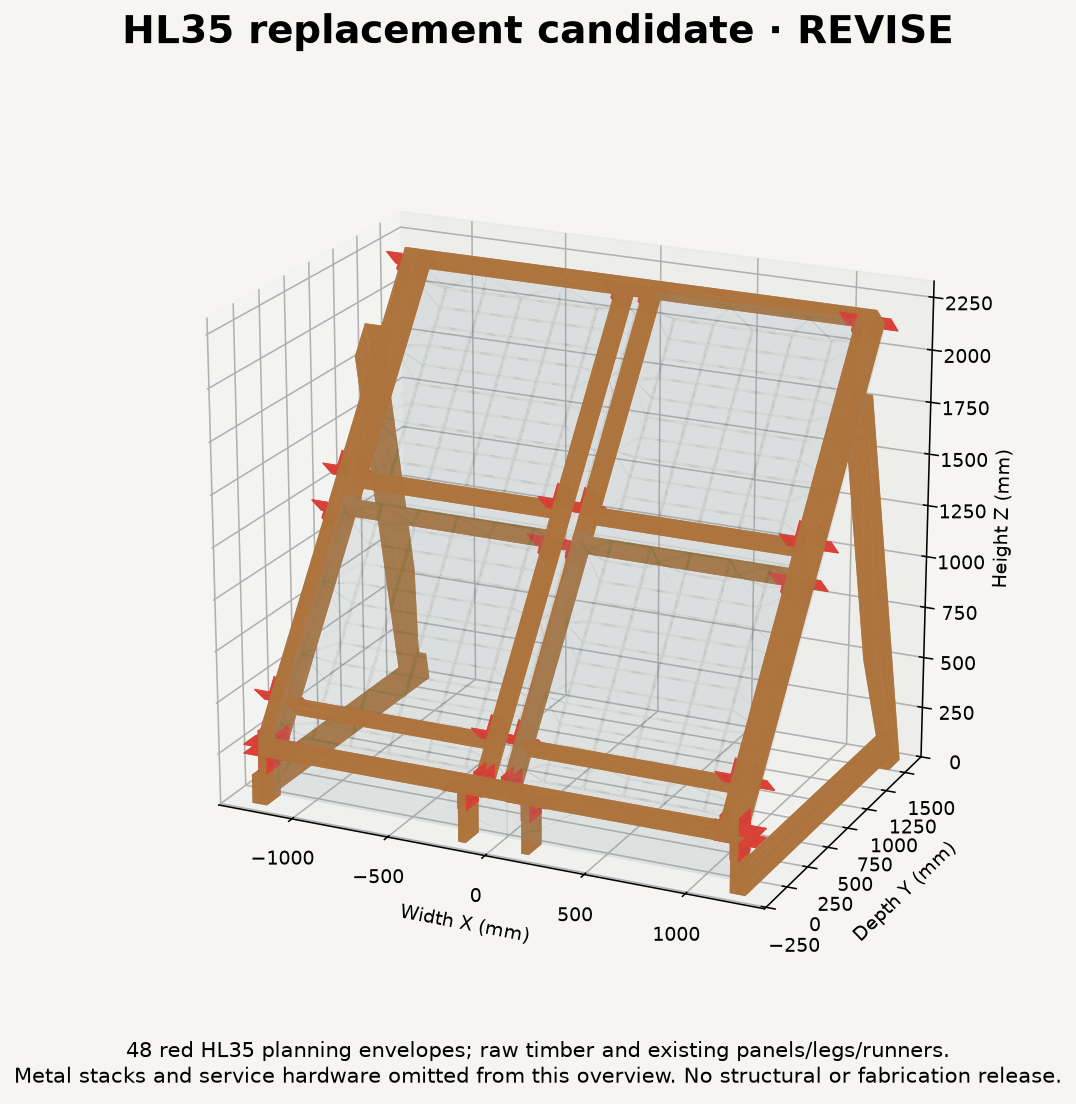
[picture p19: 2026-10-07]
docs/wood-joints-mvp/hypotheses/hl35-candidate/overview.png

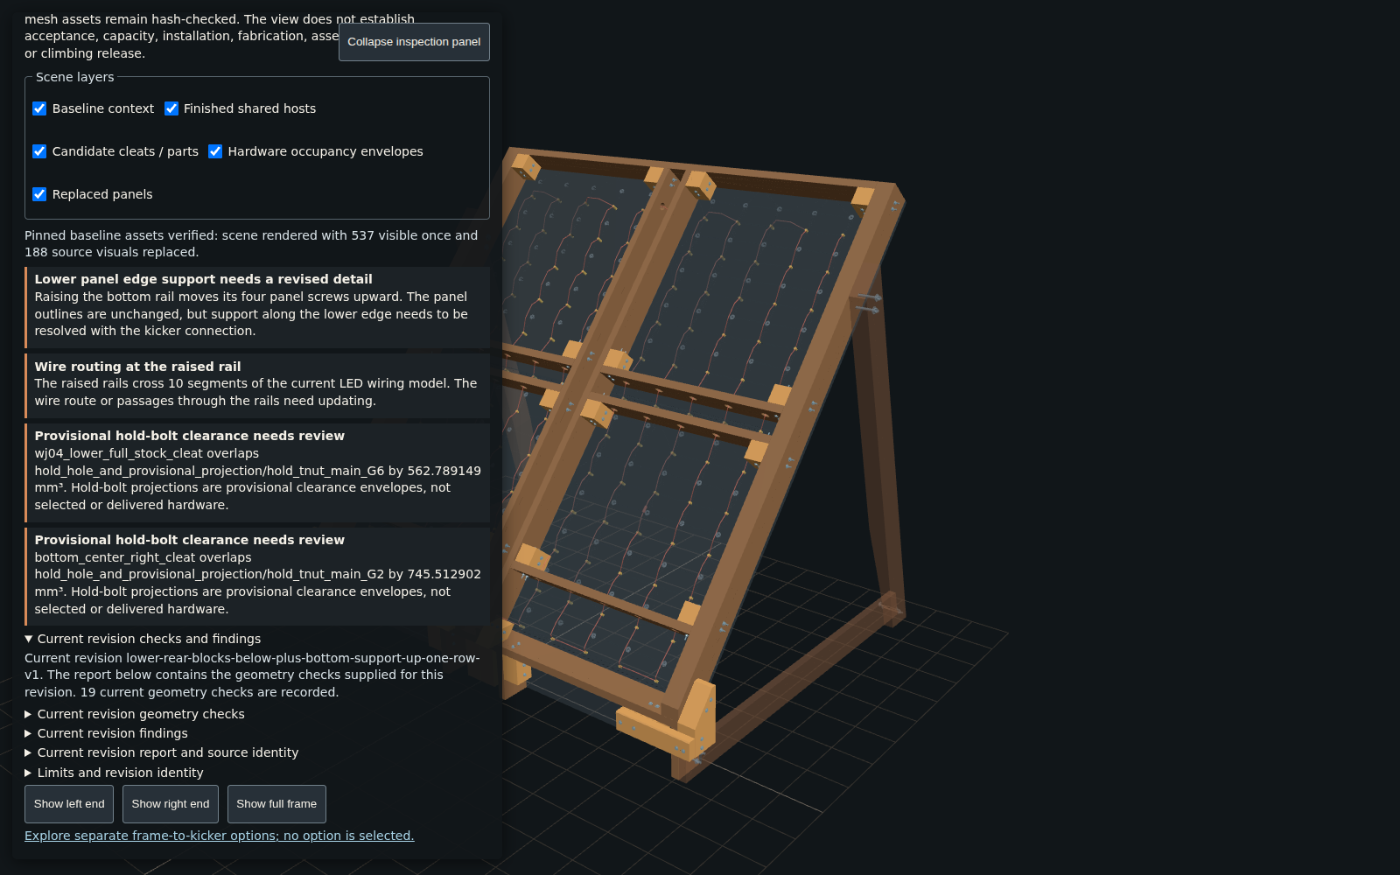
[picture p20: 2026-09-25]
docs/wood-joints-mvp/hypotheses/wj24-owner-design-review-2026-09-24/browser-evidence/desktop-right-end.png

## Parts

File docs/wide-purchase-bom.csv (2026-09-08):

item | product | quantity | nominal_length_mm | nominal_length_in | source_url | qualification
bolt | Conquest-family 3/8-16 A307 Grade A plain hex bolt | 6 | 63.5 | 2.5 | https://www.fastenersplus.com/cdn/shop/files/CQ-Hex-Head-Bolts-Spec-Sheet.pdf?v=17509241941931126534 | Nominal candidate length; verify exact orderable SKU, thread engagement and connection resistance
bolt | Conquest-family 3/8-16 A307 Grade A plain hex bolt | 8 | 76.2 | 3.0 | https://www.fastenersplus.com/cdn/shop/files/CQ-Hex-Head-Bolts-Spec-Sheet.pdf?v=17509241941931126534 | Nominal candidate length; verify exact orderable SKU, thread engagement and connection resistance
bolt | Conquest-family 3/8-16 A307 Grade A plain hex bolt | 8 | 95.25 | 3.75 | https://www.fastenersplus.com/cdn/shop/files/CQ-Hex-Head-Bolts-Spec-Sheet.pdf?v=17509241941931126534 | Nominal candidate length; verify exact orderable SKU, thread engagement and connection resistance
bolt | Conquest-family 3/8-16 A307 Grade A plain hex bolt | 2 | 152.4 | 6.0 | https://www.fastenersplus.com/cdn/shop/files/CQ-Hex-Head-Bolts-Spec-Sheet.pdf?v=17509241941931126534 | Nominal candidate length; verify exact orderable SKU, thread engagement and connection resistance
nut | FMW 3/8-16 ASTM A563 Grade A finished hex nut zinc | 24 |  |  | https://www.fmwfasteners.com/products/3-8-16-grade-2-finished-hex-nut-zinc-plated | One per bolt; fit, tightening and locking practice unqualified
washer | CDE 599192 3/8 SAE carbon-steel zinc washer | 48 |  |  | https://cdefasteners.com/sites/default/files/product-specs/washerssae.pdf | Two per bolt; washer material certificate and bending resistance unqualified; not F844-certified
insert | E-Z LOK 801420-13 | 56 | 13.0048 | 0.512 | https://www.ezlok.com/ezhex-insert-801420-13 | Effective engagement, torque and wood anchorage unqualified
machine screw | L.H. Dottie FMDD14114 1/4-20 flat head | 56 | 31.75 | 1.25 | https://lhdottie.com/14-20-flat-head-squarephillips/fmdd14114 | Length includes head; engagement, seating and panel pull-through unqualified
angle | Simpson Strong-Tie ML24Z | 18 |  |  | https://ssttoolbox.widen.net/content/iczmiabsx6/pdf/L-C-MLZ25.pdf | Installation orientation and resistance unqualified; screws purchased separately
connector screw | Simpson Strong-Tie SDS25112 1/4 x1-1/2 in | 108 | 38.1 | 1.5 | https://ssttoolbox.widen.net/content/iczmiabsx6/pdf/L-C-MLZ25.pdf | Six per ML24Z; installation and directional resistance unqualified

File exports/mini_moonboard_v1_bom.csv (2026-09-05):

item | quantity | note
19.05 mm / 3/4 in birch plywood for laminations | 7 sheets | Conservative bounding-blank sheet layout; two layers = 38.1 mm; 2.4 mm separating kerf.
18 mm climbing plywood | 5 sheets | 4 main panels + 2 kicker panels; separate stock thickness.
Mini MoonBoard 2025 Setup Hold Bundle | 1, SKU 60-105-2025 | User-owned; hold-specific bolts and pin screws separate.
Escape 3-hole screw-in T-nuts, 3/8-16 | 142 + spares | Received flange geometry; fixing screws included per selected listing.
MoonBoard LED System | 1, SKU 60-201-V5 | 132 installed lights; retain unused kit lights.
3/8 in washers, 25.4 mm OD x 2 mm | 40 | Two per bolt; nominal dimensions modelled.
3/8 in nuts, 9 mm axial envelope | 20 | Actual thread engagement and locking method require review.
Lamination adhesive | coverage-dependent | Select product and documented spread/clamping/cure procedure.
Floor pads / anti-slip interface | pending floor properties | No anchoring; pad is a separate user element.
bolt: diameter 9.525 mm, length 95.25 mm / 3.75 in | 20 | Provisional hardware envelope; connection schedule gives each axis and joined members.
screw: diameter 4.826 mm, length 50.8 mm / 2 in | 64 | Provisional hardware envelope; connection schedule gives each axis and joined members.
screw: diameter 4.826 mm, length 63.5 mm / 2.5 in | 8 | Provisional hardware envelope; connection schedule gives each axis and joined members.
screw: diameter 4.826 mm, length 88.9 mm / 3.5 in | 54 | Provisional hardware envelope; connection schedule gives each axis and joined members.

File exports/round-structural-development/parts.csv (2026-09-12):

part | kind | dimension_1_mm | dimension_2_mm | dimension_3_mm | description
main_lower_left | part | 1219.2 | 1219.2 | 18.256249999999998 | Purchased 23/32 CAT face; unchanged main backplane; opt-in panel_grid_v2 datums; GEOMETRY CONCEPT ONLY; retention, service access and structural capacity unqualified; NOT build-ready; 56 SPAX structural panel/kicker screws; future inserts optional and unqualified; 38.1 mm LED passages in nominal 2x6 stock, 25.4 mm in other stock; frame, connections, residual sections and stability unqualified; NOT build-ready
main_lower_right | part | 1219.2 | 1219.2 | 18.256249999999998 | Purchased 23/32 CAT face; unchanged main backplane; opt-in panel_grid_v2 datums; GEOMETRY CONCEPT ONLY; retention, service access and structural capacity unqualified; NOT build-ready; 56 SPAX structural panel/kicker screws; future inserts optional and unqualified; 38.1 mm LED passages in nominal 2x6 stock, 25.4 mm in other stock; frame, connections, residual sections and stability unqualified; NOT build-ready
main_upper_left | part | 1219.2 | 1219.2 | 18.256249999999998 | Purchased 23/32 CAT face; unchanged main backplane; opt-in panel_grid_v2 datums; GEOMETRY CONCEPT ONLY; retention, service access and structural capacity unqualified; NOT build-ready; 56 SPAX structural panel/kicker screws; future inserts optional and unqualified; 38.1 mm LED passages in nominal 2x6 stock, 25.4 mm in other stock; frame, connections, residual sections and stability unqualified; NOT build-ready
main_upper_right | part | 1219.2 | 1219.2 | 18.256249999999998 | Purchased 23/32 CAT face; unchanged main backplane; opt-in panel_grid_v2 datums; GEOMETRY CONCEPT ONLY; retention, service access and structural capacity unqualified; NOT build-ready; 56 SPAX structural panel/kicker screws; future inserts optional and unqualified; 38.1 mm LED passages in nominal 2x6 stock, 25.4 mm in other stock; frame, connections, residual sections and stability unqualified; NOT build-ready
kicker_left | part | 1219.2 | 225.0 | 18.256249999999998 | 225mm kicker; ten total active-zone T-nut holes; no main-grid LEDs in kicker; GEOMETRY CONCEPT ONLY; retention, service access and structural capacity unqualified; NOT build-ready; 56 SPAX structural panel/kicker screws; future inserts optional and unqualified; 38.1 mm LED passages in nominal 2x6 stock, 25.4 mm in other stock; frame, connections, residual sections and stability unqualified; NOT build-ready
kicker_right | part | 1219.2 | 225.0 | 18.256249999999998 | 225mm kicker; ten total active-zone T-nut holes; no main-grid LEDs in kicker; GEOMETRY CONCEPT ONLY; retention, service access and structural capacity unqualified; NOT build-ready; 56 SPAX structural panel/kicker screws; future inserts optional and unqualified; 38.1 mm LED passages in nominal 2x6 stock, 25.4 mm in other stock; frame, connections, residual sections and stability unqualified; NOT build-ready
base_side_left | part | 2608.023990442487 | 139.7 | 38.1 | Single nominal 2x6 outer rim; grain along slope; level bearing cut; Four horizontal single 2x6 service rails replace four intermediate principals and posts; split center pair and outer base angles retained; provisional rail placement, panel spans, wiring access, connections and stability unqualified; NOT build-ready; 56 SPAX structural panel/kicker screws; future inserts optional and unqualified; 38.1 mm LED passages in nominal 2x6 stock, 25.4 mm in other stock; frame, connections, residual sections and stability unqualified; NOT build-ready
base_side_right | part | 2608.023990442487 | 139.7 | 38.1 | Single nominal 2x6 outer rim; grain along slope; level bearing cut; Four horizontal single 2x6 service rails replace four intermediate principals and posts; split center pair and outer base angles retained; provisional rail placement, panel spans, wiring access, connections and stability unqualified; NOT build-ready; 56 SPAX structural panel/kicker screws; future inserts optional and unqualified; 38.1 mm LED passages in nominal 2x6 stock, 25.4 mm in other stock; frame, connections, residual sections and stability unqualified; NOT build-ready
base_rail_top | part | 2362.2000000000003 | 139.7 | 38.1 | Single nominal 2x6 top crossmember; grain X; square cut; Four horizontal single 2x6 service rails replace four intermediate principals and posts; split center pair and outer base angles retained; provisional rail placement, panel spans, wiring access, connections and stability unqualified; NOT build-ready; 56 SPAX structural panel/kicker screws; future inserts optional and unqualified; 38.1 mm LED passages in nominal 2x6 stock, 25.4 mm in other stock; frame, connections, residual sections and stability unqualified; NOT build-ready
base_header | part | 2438.4 | 234.95 | 38.1 | Single nominal 2x10 flat header; retained front datum and height; Four horizontal single 2x6 service rails replace four intermediate principals and posts; split center pair and outer base angles retained; provisional rail placement, panel spans, wiring access, connections and stability unqualified; NOT build-ready; 56 SPAX structural panel/kicker screws; future inserts optional and unqualified; 38.1 mm LED passages in nominal 2x6 stock, 25.4 mm in other stock; frame, connections, residual sections and stability unqualified; NOT build-ready
base_post_outer_left | part | 186.9 | 234.95 | 38.1 | Single nominal 2x10 outer post; full-depth header support; retained gusset bolt grips; Four horizontal single 2x6 service rails replace four intermediate principals and posts; split center pair and outer base angles retained; provisional rail placement, panel spans, wiring access, connections and stability unqualified; NOT build-ready; 56 SPAX structural panel/kicker screws; future inserts optional and unqualified; 38.1 mm LED passages in nominal 2x6 stock, 25.4 mm in other stock; frame, connections, residual sections and stability unqualified; NOT build-ready
base_post_outer_right | part | 186.9 | 234.95 | 38.1 | Single nominal 2x10 outer post; full-depth header support; retained gusset bolt grips; Four horizontal single 2x6 service rails replace four intermediate principals and posts; split center pair and outer base angles retained; provisional rail placement, panel spans, wiring access, connections and stability unqualified; NOT build-ready; 56 SPAX structural panel/kicker screws; future inserts optional and unqualified; 38.1 mm LED passages in nominal 2x6 stock, 25.4 mm in other stock; frame, connections, residual sections and stability unqualified; NOT build-ready
lumber_leg_left | part | 1807.9717682704706 | 139.7 | 38.1 | Single nominal 2x6 leg; retained square top and level foot; relocated bolt group; Four horizontal single 2x6 service rails replace four intermediate principals and posts; split center pair and outer base angles retained; provisional rail placement, panel spans, wiring access, connections and stability unqualified; NOT build-ready; 56 SPAX structural panel/kicker screws; future inserts optional and unqualified; 38.1 mm LED passages in nominal 2x6 stock, 25.4 mm in other stock; frame, connections, residual sections and stability unqualified; NOT build-ready
lumber_leg_right | part | 1807.9717682704706 | 139.7 | 38.1 | Single nominal 2x6 leg; retained square top and level foot; relocated bolt group; Four horizontal single 2x6 service rails replace four intermediate principals and posts; split center pair and outer base angles retained; provisional rail placement, panel spans, wiring access, connections and stability unqualified; NOT build-ready; 56 SPAX structural panel/kicker screws; future inserts optional and unqualified; 38.1 mm LED passages in nominal 2x6 stock, 25.4 mm in other stock; frame, connections, residual sections and stability unqualified; NOT build-ready
base_principal_center_left | part | 2532.626011836657 | 139.7 | 38.1 | Independent single nominal 2x6 center principal; no service pockets or housing; level bearing cut; grain along slope; Four horizontal single 2x6 service rails replace four intermediate principals and posts; split center pair and outer base angles retained; provisional rail placement, panel spans, wiring access, connections and stability unqualified; NOT build-ready; 56 SPAX structural panel/kicker screws; future inserts optional and unqualified; 38.1 mm LED passages in nominal 2x6 stock, 25.4 mm in other stock; frame, connections, residual sections and stability unqualified; NOT build-ready; enclosed 38.1 mm strand passage
base_post_center_left | part | 186.9 | 234.95 | 38.1 | Independent single nominal 2x10 center post; vertical grain; full-depth header support; Four horizontal single 2x6 service rails replace four intermediate principals and posts; split center pair and outer base angles retained; provisional rail placement, panel spans, wiring access, connections and stability unqualified; NOT build-ready; 56 SPAX structural panel/kicker screws; future inserts optional and unqualified; 38.1 mm LED passages in nominal 2x6 stock, 25.4 mm in other stock; frame, connections, residual sections and stability unqualified; NOT build-ready
base_principal_center_right | part | 2532.626011836657 | 139.7 | 38.1 | Independent single nominal 2x6 center principal; no service pockets or housing; level bearing cut; grain along slope; Four horizontal single 2x6 service rails replace four intermediate principals and posts; split center pair and outer base angles retained; provisional rail placement, panel spans, wiring access, connections and stability unqualified; NOT build-ready; 56 SPAX structural panel/kicker screws; future inserts optional and unqualified; 38.1 mm LED passages in nominal 2x6 stock, 25.4 mm in other stock; frame, connections, residual sections and stability unqualified; NOT build-ready; enclosed 38.1 mm strand passage
base_post_center_right | part | 186.9 | 234.95 | 38.1 | Independent single nominal 2x10 center post; vertical grain; full-depth header support; Four horizontal single 2x6 service rails replace four intermediate principals and posts; split center pair and outer base angles retained; provisional rail placement, panel spans, wiring access, connections and stability unqualified; NOT build-ready; 56 SPAX structural panel/kicker screws; future inserts optional and unqualified; 38.1 mm LED passages in nominal 2x6 stock, 25.4 mm in other stock; frame, connections, residual sections and stability unqualified; NOT build-ready
base_rail_bottom_left | part | 1092.0500000000002 | 139.7 | 38.1 | Independent square-cut single 2x6 horizontal rail; grain X; no inherited service pockets; Four horizontal single 2x6 service rails replace four intermediate principals and posts; split center pair and outer base angles retained; provisional rail placement, panel spans, wiring access, connections and stability unqualified; NOT build-ready; 56 SPAX structural panel/kicker screws; future inserts optional and unqualified; 38.1 mm LED passages in nominal 2x6 stock, 25.4 mm in other stock; frame, connections, residual sections and stability unqualified; NOT build-ready; enclosed 38.1 mm strand passage; enclosed 38.1 mm strand passage; enclosed 38.1 mm strand passage; enclosed 38.1 mm strand passage; enclosed 38.1 mm strand passage
base_rail_service_lower_left | part | 1092.0500000000002 | 139.7 | 38.1 | Independent square-cut single 2x6 horizontal rail; grain X; no inherited service pockets; Four horizontal single 2x6 service rails replace four intermediate principals and posts; split center pair and outer base angles retained; provisional rail placement, panel spans, wiring access, connections and stability unqualified; NOT build-ready; 56 SPAX structural panel/kicker screws; future inserts optional and unqualified; 38.1 mm LED passages in nominal 2x6 stock, 25.4 mm in other stock; frame, connections, residual sections and stability unqualified; NOT build-ready; enclosed 38.1 mm strand passage; enclosed 38.1 mm strand passage; enclosed 38.1 mm strand passage; enclosed 38.1 mm strand passage; enclosed 38.1 mm strand passage
base_rail_service_upper_left | part | 1092.0500000000002 | 139.7 | 38.1 | Independent square-cut single 2x6 horizontal rail; grain X; no inherited service pockets; Four horizontal single 2x6 service rails replace four intermediate principals and posts; split center pair and outer base angles retained; provisional rail placement, panel spans, wiring access, connections and stability unqualified; NOT build-ready; 56 SPAX structural panel/kicker screws; future inserts optional and unqualified; 38.1 mm LED passages in nominal 2x6 stock, 25.4 mm in other stock; frame, connections, residual sections and stability unqualified; NOT build-ready; enclosed 38.1 mm strand passage; enclosed 38.1 mm strand passage; enclosed 38.1 mm strand passage; enclosed 38.1 mm strand passage; enclosed 38.1 mm strand passage
base_rail_bottom_right | part | 1092.0500000000002 | 139.7 | 38.1 | Independent square-cut single 2x6 horizontal rail; grain X; no inherited service pockets; Four horizontal single 2x6 service rails replace four intermediate principals and posts; split center pair and outer base angles retained; provisional rail placement, panel spans, wiring access, connections and stability unqualified; NOT build-ready; 56 SPAX structural panel/kicker screws; future inserts optional and unqualified; 38.1 mm LED passages in nominal 2x6 stock, 25.4 mm in other stock; frame, connections, residual sections and stability unqualified; NOT build-ready; enclosed 38.1 mm strand passage; enclosed 38.1 mm strand passage; enclosed 38.1 mm strand passage; enclosed 38.1 mm strand passage; enclosed 38.1 mm strand passage
base_rail_service_lower_right | part | 1092.0500000000002 | 139.7 | 38.1 | Independent square-cut single 2x6 horizontal rail; grain X; no inherited service pockets; Four horizontal single 2x6 service rails replace four intermediate principals and posts; split center pair and outer base angles retained; provisional rail placement, panel spans, wiring access, connections and stability unqualified; NOT build-ready; 56 SPAX structural panel/kicker screws; future inserts optional and unqualified; 38.1 mm LED passages in nominal 2x6 stock, 25.4 mm in other stock; frame, connections, residual sections and stability unqualified; NOT build-ready; enclosed 38.1 mm strand passage; enclosed 38.1 mm strand passage; enclosed 38.1 mm strand passage; enclosed 38.1 mm strand passage; enclosed 38.1 mm strand passage
base_rail_service_upper_right | part | 1092.0500000000002 | 139.7 | 38.1 | Independent square-cut single 2x6 horizontal rail; grain X; no inherited service pockets; Four horizontal single 2x6 service rails replace four intermediate principals and posts; split center pair and outer base angles retained; provisional rail placement, panel spans, wiring access, connections and stability unqualified; NOT build-ready; 56 SPAX structural panel/kicker screws; future inserts optional and unqualified; 38.1 mm LED passages in nominal 2x6 stock, 25.4 mm in other stock; frame, connections, residual sections and stability unqualified; NOT build-ready; enclosed 38.1 mm strand passage; enclosed 38.1 mm strand passage; enclosed 38.1 mm strand passage; enclosed 38.1 mm strand passage; enclosed 38.1 mm strand passage
clip_single_top_left_1 | part | 101.6 | 53.35524 | 53.35524 | Purchased ML24Z; six separately purchased SDS25112 screws; Manufacturer nominal geometry; actual fit, installation and resistance unqualified; NOT build-ready
clip_single_top_right_2 | part | 101.6 | 53.35524 | 53.35524 | Purchased ML24Z; six separately purchased SDS25112 screws; Manufacturer nominal geometry; actual fit, installation and resistance unqualified; NOT build-ready
clip_timber_header_outer_left | part | 101.6 | 53.35524 | 53.35524 | Purchased ML24Z; six separately purchased SDS25112 screws; Manufacturer nominal geometry; actual fit, installation and resistance unqualified; NOT build-ready
clip_timber_header_outer_right | part | 101.6 | 53.35524 | 53.35524 | Purchased ML24Z; six separately purchased SDS25112 screws; Manufacturer nominal geometry; actual fit, installation and resistance unqualified; NOT build-ready
clip_split_top_center_left | part | 101.6 | 53.35524 | 53.35524 | Purchased ML24Z; six separately purchased SDS25112 screws; Manufacturer nominal geometry; actual fit, installation and resistance unqualified; NOT build-ready
clip_split_base_center_left | part | 101.6 | 53.35524 | 53.35524 | Purchased ML24Z; six separately purchased SDS25112 screws; Manufacturer nominal geometry; actual fit, installation and resistance unqualified; NOT build-ready
clip_split_header_center_left | part | 101.6 | 53.35524 | 53.35524 | Purchased ML24Z; six separately purchased SDS25112 screws; Manufacturer nominal geometry; actual fit, installation and resistance unqualified; NOT build-ready
clip_split_top_center_right | part | 101.6 | 53.35524 | 53.35524 | Purchased ML24Z; six separately purchased SDS25112 screws; Manufacturer nominal geometry; actual fit, installation and resistance unqualified; NOT build-ready
clip_split_base_center_right | part | 101.6 | 53.35524 | 53.35524 | Purchased ML24Z; six separately purchased SDS25112 screws; Manufacturer nominal geometry; actual fit, installation and resistance unqualified; NOT build-ready
clip_split_header_center_right | part | 101.6 | 53.35524 | 53.35524 | Purchased ML24Z; six separately purchased SDS25112 screws; Manufacturer nominal geometry; actual fit, installation and resistance unqualified; NOT build-ready
clip_angle_base_left | part | 101.6 | 53.35524 | 53.35524 | Purchased ML24Z; six separately purchased SDS25112 screws; Manufacturer nominal geometry; actual fit, installation and resistance unqualified; NOT build-ready
clip_angle_base_right | part | 101.6 | 53.35524 | 53.35524 | Purchased ML24Z; six separately purchased SDS25112 screws; Manufacturer nominal geometry; actual fit, installation and resistance unqualified; NOT build-ready
clip_horizontal_bottom_left_1 | part | 101.6 | 53.35524 | 53.35524 | Purchased ML24Z; six separately purchased SDS25112 screws; Manufacturer nominal geometry; actual fit, installation and resistance unqualified; NOT build-ready
clip_horizontal_bottom_left_2 | part | 101.6 | 53.35524 | 53.35524 | Purchased ML24Z; six separately purchased SDS25112 screws; Manufacturer nominal geometry; actual fit, installation and resistance unqualified; NOT build-ready
clip_horizontal_lower_left_1 | part | 101.6 | 53.35524 | 53.35524 | Purchased ML24Z; six separately purchased SDS25112 screws; Manufacturer nominal geometry; actual fit, installation and resistance unqualified; NOT build-ready
clip_horizontal_lower_left_2 | part | 101.6 | 53.35524 | 53.35524 | Purchased ML24Z; six separately purchased SDS25112 screws; Manufacturer nominal geometry; actual fit, installation and resistance unqualified; NOT build-ready
clip_horizontal_upper_left_1 | part | 101.6 | 53.35524 | 53.35524 | Purchased ML24Z; six separately purchased SDS25112 screws; Manufacturer nominal geometry; actual fit, installation and resistance unqualified; NOT build-ready
clip_horizontal_upper_left_2 | part | 101.6 | 53.35524 | 53.35524 | Purchased ML24Z; six separately purchased SDS25112 screws; Manufacturer nominal geometry; actual fit, installation and resistance unqualified; NOT build-ready
clip_horizontal_bottom_right_1 | part | 101.6 | 53.35524 | 53.35524 | Purchased ML24Z; six separately purchased SDS25112 screws; Manufacturer nominal geometry; actual fit, installation and resistance unqualified; NOT build-ready
clip_horizontal_bottom_right_2 | part | 101.6 | 53.35524 | 53.35524 | Purchased ML24Z; six separately purchased SDS25112 screws; Manufacturer nominal geometry; actual fit, installation and resistance unqualified; NOT build-ready
clip_horizontal_lower_right_1 | part | 101.6 | 53.35524 | 53.35524 | Purchased ML24Z; six separately purchased SDS25112 screws; Manufacturer nominal geometry; actual fit, installation and resistance unqualified; NOT build-ready
clip_horizontal_lower_right_2 | part | 101.6 | 53.35524 | 53.35524 | Purchased ML24Z; six separately purchased SDS25112 screws; Manufacturer nominal geometry; actual fit, installation and resistance unqualified; NOT build-ready
clip_horizontal_upper_right_1 | part | 101.6 | 53.35524 | 53.35524 | Purchased ML24Z; six separately purchased SDS25112 screws; Manufacturer nominal geometry; actual fit, installation and resistance unqualified; NOT build-ready
clip_horizontal_upper_right_2 | part | 101.6 | 53.35524 | 53.35524 | Purchased ML24Z; six separately purchased SDS25112 screws; Manufacturer nominal geometry; actual fit, installation and resistance unqualified; NOT build-ready
light_A1 | light | 12.699999999999932 | 31.34103482513763 | 29.177107043189352 | Provisional light envelope; unknown mass excluded; 56 SPAX structural panel/kicker screws; future inserts optional and unqualified; 38.1 mm LED passages in nominal 2x6 stock, 25.4 mm in other stock; frame, connections, residual sections and stability unqualified; NOT build-ready
light_A2 | light | 12.699999999999932 | 31.34103482513764 | 29.17710704318938 | Provisional light envelope; unknown mass excluded; 56 SPAX structural panel/kicker screws; future inserts optional and unqualified; 38.1 mm LED passages in nominal 2x6 stock, 25.4 mm in other stock; frame, connections, residual sections and stability unqualified; NOT build-ready
light_A3 | light | 12.699999999999932 | 31.341034825137598 | 29.177107043189267 | Provisional light envelope; unknown mass excluded; 56 SPAX structural panel/kicker screws; future inserts optional and unqualified; 38.1 mm LED passages in nominal 2x6 stock, 25.4 mm in other stock; frame, connections, residual sections and stability unqualified; NOT build-ready
light_A4 | light | 12.699999999999932 | 31.341034825137626 | 29.177107043189267 | Provisional light envelope; unknown mass excluded; 56 SPAX structural panel/kicker screws; future inserts optional and unqualified; 38.1 mm LED passages in nominal 2x6 stock, 25.4 mm in other stock; frame, connections, residual sections and stability unqualified; NOT build-ready
light_A5 | light | 12.699999999999932 | 31.341034825137626 | 29.177107043189267 | Provisional light envelope; unknown mass excluded; 56 SPAX structural panel/kicker screws; future inserts optional and unqualified; 38.1 mm LED passages in nominal 2x6 stock, 25.4 mm in other stock; frame, connections, residual sections and stability unqualified; NOT build-ready
light_A6 | light | 12.699999999999932 | 31.341034825137626 | 29.177107043189267 | Provisional light envelope; unknown mass excluded; 56 SPAX structural panel/kicker screws; future inserts optional and unqualified; 38.1 mm LED passages in nominal 2x6 stock, 25.4 mm in other stock; frame, connections, residual sections and stability unqualified; NOT build-ready
light_A7 | light | 12.699999999999932 | 31.341034825137626 | 29.177107043189608 | Provisional light envelope; unknown mass excluded; 56 SPAX structural panel/kicker screws; future inserts optional and unqualified; 38.1 mm LED passages in nominal 2x6 stock, 25.4 mm in other stock; frame, connections, residual sections and stability unqualified; NOT build-ready
light_A8 | light | 12.699999999999932 | 31.341034825137626 | 29.177107043189608 | Provisional light envelope; unknown mass excluded; 56 SPAX structural panel/kicker screws; future inserts optional and unqualified; 38.1 mm LED passages in nominal 2x6 stock, 25.4 mm in other stock; frame, connections, residual sections and stability unqualified; NOT build-ready
light_A9 | light | 12.699999999999932 | 31.341034825137626 | 29.177107043189608 | Provisional light envelope; unknown mass excluded; 56 SPAX structural panel/kicker screws; future inserts optional and unqualified; 38.1 mm LED passages in nominal 2x6 stock, 25.4 mm in other stock; frame, connections, residual sections and stability unqualified; NOT build-ready
light_A10 | light | 12.699999999999932 | 31.34103482513774 | 29.177107043189608 | Provisional light envelope; unknown mass excluded; 56 SPAX structural panel/kicker screws; future inserts optional and unqualified; 38.1 mm LED passages in nominal 2x6 stock, 25.4 mm in other stock; frame, connections, residual sections and stability unqualified; NOT build-ready
light_A11 | light | 12.699999999999932 | 31.34103482513774 | 29.177107043189608 | Provisional light envelope; unknown mass excluded; 56 SPAX structural panel/kicker screws; future inserts optional and unqualified; 38.1 mm LED passages in nominal 2x6 stock, 25.4 mm in other stock; frame, connections, residual sections and stability unqualified; NOT build-ready
light_A12 | light | 12.699999999999932 | 31.34103482513774 | 29.177107043189608 | Provisional light envelope; unknown mass excluded; 56 SPAX structural panel/kicker screws; future inserts optional and unqualified; 38.1 mm LED passages in nominal 2x6 stock, 25.4 mm in other stock; frame, connections, residual sections and stability unqualified; NOT build-ready
light_B1 | light | 12.700000000000045 | 31.34103482513763 | 29.177107043189352 | Provisional light envelope; unknown mass excluded; 56 SPAX structural panel/kicker screws; future inserts optional and unqualified; 38.1 mm LED passages in nominal 2x6 stock, 25.4 mm in other stock; frame, connections, residual sections and stability unqualified; NOT build-ready
light_B2 | light | 12.700000000000045 | 31.34103482513764 | 29.17710704318938 | Provisional light envelope; unknown mass excluded; 56 SPAX structural panel/kicker screws; future inserts optional and unqualified; 38.1 mm LED passages in nominal 2x6 stock, 25.4 mm in other stock; frame, connections, residual sections and stability unqualified; NOT build-ready
light_B3 | light | 12.700000000000045 | 31.341034825137598 | 29.177107043189267 | Provisional light envelope; unknown mass excluded; 56 SPAX structural panel/kicker screws; future inserts optional and unqualified; 38.1 mm LED passages in nominal 2x6 stock, 25.4 mm in other stock; frame, connections, residual sections and stability unqualified; NOT build-ready
light_B4 | light | 12.700000000000045 | 31.341034825137626 | 29.177107043189267 | Provisional light envelope; unknown mass excluded; 56 SPAX structural panel/kicker screws; future inserts optional and unqualified; 38.1 mm LED passages in nominal 2x6 stock, 25.4 mm in other stock; frame, connections, residual sections and stability unqualified; NOT build-ready
light_B5 | light | 12.700000000000045 | 31.341034825137626 | 29.177107043189267 | Provisional light envelope; unknown mass excluded; 56 SPAX structural panel/kicker screws; future inserts optional and unqualified; 38.1 mm LED passages in nominal 2x6 stock, 25.4 mm in other stock; frame, connections, residual sections and stability unqualified; NOT build-ready
light_B6 | light | 12.700000000000045 | 31.341034825137626 | 29.177107043189267 | Provisional light envelope; unknown mass excluded; 56 SPAX structural panel/kicker screws; future inserts optional and unqualified; 38.1 mm LED passages in nominal 2x6 stock, 25.4 mm in other stock; frame, connections, residual sections and stability unqualified; NOT build-ready
light_B7 | light | 12.700000000000045 | 31.341034825137626 | 29.177107043189608 | Provisional light envelope; unknown mass excluded; 56 SPAX structural panel/kicker screws; future inserts optional and unqualified; 38.1 mm LED passages in nominal 2x6 stock, 25.4 mm in other stock; frame, connections, residual sections and stability unqualified; NOT build-ready
light_B8 | light | 12.700000000000045 | 31.341034825137626 | 29.177107043189608 | Provisional light envelope; unknown mass excluded; 56 SPAX structural panel/kicker screws; future inserts optional and unqualified; 38.1 mm LED passages in nominal 2x6 stock, 25.4 mm in other stock; frame, connections, residual sections and stability unqualified; NOT build-ready
light_B9 | light | 12.700000000000045 | 31.341034825137626 | 29.177107043189608 | Provisional light envelope; unknown mass excluded; 56 SPAX structural panel/kicker screws; future inserts optional and unqualified; 38.1 mm LED passages in nominal 2x6 stock, 25.4 mm in other stock; frame, connections, residual sections and stability unqualified; NOT build-ready
light_B10 | light | 12.700000000000045 | 31.34103482513774 | 29.177107043189608 | Provisional light envelope; unknown mass excluded; 56 SPAX structural panel/kicker screws; future inserts optional and unqualified; 38.1 mm LED passages in nominal 2x6 stock, 25.4 mm in other stock; frame, connections, residual sections and stability unqualified; NOT build-ready
light_B11 | light | 12.700000000000045 | 31.34103482513774 | 29.177107043189608 | Provisional light envelope; unknown mass excluded; 56 SPAX structural panel/kicker screws; future inserts optional and unqualified; 38.1 mm LED passages in nominal 2x6 stock, 25.4 mm in other stock; frame, connections, residual sections and stability unqualified; NOT build-ready
light_B12 | light | 12.700000000000045 | 31.34103482513774 | 29.177107043189608 | Provisional light envelope; unknown mass excluded; 56 SPAX structural panel/kicker screws; future inserts optional and unqualified; 38.1 mm LED passages in nominal 2x6 stock, 25.4 mm in other stock; frame, connections, residual sections and stability unqualified; NOT build-ready
light_C1 | light | 12.700000000000045 | 31.34103482513763 | 29.177107043189352 | Provisional light envelope; unknown mass excluded; 56 SPAX structural panel/kicker screws; future inserts optional and unqualified; 38.1 mm LED passages in nominal 2x6 stock, 25.4 mm in other stock; frame, connections, residual sections and stability unqualified; NOT build-ready
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

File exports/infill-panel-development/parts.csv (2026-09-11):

part | kind | dimension_1_mm | dimension_2_mm | dimension_3_mm | description
main_lower_left | part | 1219.2 | 1219.2 | 18.256249999999998 | Purchased 23/32 CAT face; unchanged main backplane; opt-in panel_grid_v2 datums; GEOMETRY CONCEPT ONLY; retention, service access and structural capacity unqualified; NOT build-ready
main_lower_right | part | 1219.2 | 1219.2 | 18.256249999999998 | Purchased 23/32 CAT face; unchanged main backplane; opt-in panel_grid_v2 datums; GEOMETRY CONCEPT ONLY; retention, service access and structural capacity unqualified; NOT build-ready
main_upper_left | part | 1219.2 | 1219.2 | 18.256249999999998 | Purchased 23/32 CAT face; unchanged main backplane; opt-in panel_grid_v2 datums; GEOMETRY CONCEPT ONLY; retention, service access and structural capacity unqualified; NOT build-ready
main_upper_right | part | 1219.2 | 1219.2 | 18.256249999999998 | Purchased 23/32 CAT face; unchanged main backplane; opt-in panel_grid_v2 datums; GEOMETRY CONCEPT ONLY; retention, service access and structural capacity unqualified; NOT build-ready
kicker_left | part | 1219.2 | 225.0 | 18.256249999999998 | 225mm kicker; ten total active-zone T-nut holes; no main-grid LEDs in kicker; GEOMETRY CONCEPT ONLY; retention, service access and structural capacity unqualified; NOT build-ready
kicker_right | part | 1219.2 | 225.0 | 18.256249999999998 | 225mm kicker; ten total active-zone T-nut holes; no main-grid LEDs in kicker; GEOMETRY CONCEPT ONLY; retention, service access and structural capacity unqualified; NOT build-ready
base_side_left | part | 2608.023990442487 | 139.7 | 38.1 | Single nominal 2x6 outer rim; grain along slope; level bearing cut; Six independent single 2x6 interior principals; separated center pair with open service corridor and single 2x10 support posts; retained outer gussets; panel joint overhang, connections, header and stability unqualified; NOT build-ready
base_side_right | part | 2608.023990442487 | 139.7 | 38.1 | Single nominal 2x6 outer rim; grain along slope; level bearing cut; Six independent single 2x6 interior principals; separated center pair with open service corridor and single 2x10 support posts; retained outer gussets; panel joint overhang, connections, header and stability unqualified; NOT build-ready
base_rail_top | part | 2362.2000000000003 | 139.7 | 38.1 | Single nominal 2x6 top crossmember; grain X; square cut; Six independent single 2x6 interior principals; separated center pair with open service corridor and single 2x10 support posts; retained outer gussets; panel joint overhang, connections, header and stability unqualified; NOT build-ready
base_header | part | 2438.4 | 234.95 | 38.1 | Single nominal 2x10 flat header; retained front datum and height; Six independent single 2x6 interior principals; separated center pair with open service corridor and single 2x10 support posts; retained outer gussets; panel joint overhang, connections, header and stability unqualified; NOT build-ready
base_post_outer_left | part | 186.9 | 234.95 | 38.1 | Single nominal 2x10 outer post; full-depth header support; retained gusset bolt grips; Six independent single 2x6 interior principals; separated center pair with open service corridor and single 2x10 support posts; retained outer gussets; panel joint overhang, connections, header and stability unqualified; NOT build-ready
base_post_outer_right | part | 186.9 | 234.95 | 38.1 | Single nominal 2x10 outer post; full-depth header support; retained gusset bolt grips; Six independent single 2x6 interior principals; separated center pair with open service corridor and single 2x10 support posts; retained outer gussets; panel joint overhang, connections, header and stability unqualified; NOT build-ready
timber_base_gusset_left | part | 460.0 | 285.75 | 19.05 | Removable 3/4 in plywood side gusset; face grain vertical; four through-bolts; plywood thickness assumed, not purchased-face measurement; Development geometry; connections and structural resistance unqualified; NOT build-ready
timber_base_gusset_right | part | 460.0 | 285.75 | 19.05 | Removable 3/4 in plywood side gusset; face grain vertical; four through-bolts; plywood thickness assumed, not purchased-face measurement; Development geometry; connections and structural resistance unqualified; NOT build-ready
lumber_leg_left | part | 1807.9717682704706 | 139.7 | 38.1 | Single nominal 2x6 leg; retained square top and level foot; relocated bolt group; Six independent single 2x6 interior principals; separated center pair with open service corridor and single 2x10 support posts; retained outer gussets; panel joint overhang, connections, header and stability unqualified; NOT build-ready
lumber_leg_right | part | 1807.9717682704706 | 139.7 | 38.1 | Single nominal 2x6 leg; retained square top and level foot; relocated bolt group; Six independent single 2x6 interior principals; separated center pair with open service corridor and single 2x10 support posts; retained outer gussets; panel joint overhang, connections, header and stability unqualified; NOT build-ready
base_principal_left_1 | part | 2532.626011836657 | 139.7 | 38.1 | Independent single nominal 2x6 principal; no service pockets or lower housing; level full bearing cut; grain along slope; Six independent single 2x6 interior principals; separated center pair with open service corridor and single 2x10 support posts; retained outer gussets; panel joint overhang, connections, header and stability unqualified; NOT build-ready
base_post_left_1 | part | 186.9 | 234.95 | 38.1 | Single nominal 2x10 vertical-grain post; full header-depth support beneath added principal; Six independent single 2x6 interior principals; separated center pair with open service corridor and single 2x10 support posts; retained outer gussets; panel joint overhang, connections, header and stability unqualified; NOT build-ready
base_principal_left_2 | part | 2532.626011836657 | 139.7 | 38.1 | Independent single nominal 2x6 principal; no service pockets or lower housing; level full bearing cut; grain along slope; Six independent single 2x6 interior principals; separated center pair with open service corridor and single 2x10 support posts; retained outer gussets; panel joint overhang, connections, header and stability unqualified; NOT build-ready
base_post_left_2 | part | 186.9 | 234.95 | 38.1 | Single nominal 2x10 vertical-grain post; full header-depth support beneath added principal; Six independent single 2x6 interior principals; separated center pair with open service corridor and single 2x10 support posts; retained outer gussets; panel joint overhang, connections, header and stability unqualified; NOT build-ready
base_principal_right_1 | part | 2532.626011836657 | 139.7 | 38.1 | Independent single nominal 2x6 principal; no service pockets or lower housing; level full bearing cut; grain along slope; Six independent single 2x6 interior principals; separated center pair with open service corridor and single 2x10 support posts; retained outer gussets; panel joint overhang, connections, header and stability unqualified; NOT build-ready
base_post_right_1 | part | 186.9 | 234.95 | 38.1 | Single nominal 2x10 vertical-grain post; full header-depth support beneath added principal; Six independent single 2x6 interior principals; separated center pair with open service corridor and single 2x10 support posts; retained outer gussets; panel joint overhang, connections, header and stability unqualified; NOT build-ready
base_principal_right_2 | part | 2532.626011836657 | 139.7 | 38.1 | Independent single nominal 2x6 principal; no service pockets or lower housing; level full bearing cut; grain along slope; Six independent single 2x6 interior principals; separated center pair with open service corridor and single 2x10 support posts; retained outer gussets; panel joint overhang, connections, header and stability unqualified; NOT build-ready
base_post_right_2 | part | 186.9 | 234.95 | 38.1 | Single nominal 2x10 vertical-grain post; full header-depth support beneath added principal; Six independent single 2x6 interior principals; separated center pair with open service corridor and single 2x10 support posts; retained outer gussets; panel joint overhang, connections, header and stability unqualified; NOT build-ready
base_rail_bottom_left_1 | part | 392.0500000000002 | 139.7 | 38.1 | Independent square-cut single 2x6 bottom-rail segment; no service pockets; Six independent single 2x6 interior principals; separated center pair with open service corridor and single 2x10 support posts; retained outer gussets; panel joint overhang, connections, header and stability unqualified; NOT build-ready
base_rail_bottom_left_2 | part | 361.90000000000003 | 139.7 | 38.1 | Independent square-cut single 2x6 bottom-rail segment; no service pockets; Six independent single 2x6 interior principals; separated center pair with open service corridor and single 2x10 support posts; retained outer gussets; panel joint overhang, connections, header and stability unqualified; NOT build-ready
base_rail_bottom_left_3 | part | 261.9 | 139.7 | 38.1 | Shortened square-cut 2x6 bottom segment; no service pockets; Six independent single 2x6 interior principals; separated center pair with open service corridor and single 2x10 support posts; retained outer gussets; panel joint overhang, connections, header and stability unqualified; NOT build-ready
base_rail_bottom_right_1 | part | 321.9 | 139.7 | 38.1 | Shortened square-cut 2x6 bottom segment; no service pockets; Six independent single 2x6 interior principals; separated center pair with open service corridor and single 2x10 support posts; retained outer gussets; panel joint overhang, connections, header and stability unqualified; NOT build-ready
base_rail_bottom_right_2 | part | 361.90000000000003 | 139.7 | 38.1 | Independent square-cut single 2x6 bottom-rail segment; no service pockets; Six independent single 2x6 interior principals; separated center pair with open service corridor and single 2x10 support posts; retained outer gussets; panel joint overhang, connections, header and stability unqualified; NOT build-ready
base_rail_bottom_right_3 | part | 332.0500000000002 | 139.7 | 38.1 | Independent square-cut single 2x6 bottom-rail segment; no service pockets; Six independent single 2x6 interior principals; separated center pair with open service corridor and single 2x10 support posts; retained outer gussets; panel joint overhang, connections, header and stability unqualified; NOT build-ready
base_principal_center_left | part | 2532.626011836657 | 139.7 | 38.1 | Independent single nominal 2x6 center principal; no service pockets or housing; level bearing cut; grain along slope; Six independent single 2x6 interior principals; separated center pair with open service corridor and single 2x10 support posts; retained outer gussets; panel joint overhang, connections, header and stability unqualified; NOT build-ready
base_post_center_left | part | 186.9 | 234.95 | 38.1 | Independent single nominal 2x10 center post; vertical grain; full-depth header support; Six independent single 2x6 interior principals; separated center pair with open service corridor and single 2x10 support posts; retained outer gussets; panel joint overhang, connections, header and stability unqualified; NOT build-ready
base_principal_center_right | part | 2532.626011836657 | 139.7 | 38.1 | Independent single nominal 2x6 center principal; no service pockets or housing; level bearing cut; grain along slope; Six independent single 2x6 interior principals; separated center pair with open service corridor and single 2x10 support posts; retained outer gussets; panel joint overhang, connections, header and stability unqualified; NOT build-ready
base_post_center_right | part | 186.9 | 234.95 | 38.1 | Independent single nominal 2x10 center post; vertical grain; full-depth header support; Six independent single 2x6 interior principals; separated center pair with open service corridor and single 2x10 support posts; retained outer gussets; panel joint overhang, connections, header and stability unqualified; NOT build-ready
clip_single_top_left_1 | part | 101.6 | 53.35524 | 53.35524 | Purchased ML24Z; six separately purchased SDS25112 screws; Manufacturer nominal geometry; actual fit, installation and resistance unqualified; NOT build-ready
clip_single_top_right_2 | part | 101.6 | 53.35524 | 53.35524 | Purchased ML24Z; six separately purchased SDS25112 screws; Manufacturer nominal geometry; actual fit, installation and resistance unqualified; NOT build-ready
clip_timber_header_outer_left | part | 101.6 | 53.35524 | 53.35524 | Purchased ML24Z; six separately purchased SDS25112 screws; Manufacturer nominal geometry; actual fit, installation and resistance unqualified; NOT build-ready
clip_timber_header_outer_right | part | 101.6 | 53.35524 | 53.35524 | Purchased ML24Z; six separately purchased SDS25112 screws; Manufacturer nominal geometry; actual fit, installation and resistance unqualified; NOT build-ready
clip_vertical_bottom_left_1_1 | part | 101.6 | 53.35524 | 53.35524 | Purchased ML24Z; six separately purchased SDS25112 screws; Manufacturer nominal geometry; actual fit, installation and resistance unqualified; NOT build-ready
clip_vertical_bottom_left_1_2 | part | 101.6 | 53.35524 | 53.35524 | Purchased ML24Z; six separately purchased SDS25112 screws; Manufacturer nominal geometry; actual fit, installation and resistance unqualified; NOT build-ready
clip_vertical_bottom_left_2_1 | part | 101.6 | 53.35524 | 53.35524 | Purchased ML24Z; six separately purchased SDS25112 screws; Manufacturer nominal geometry; actual fit, installation and resistance unqualified; NOT build-ready
clip_vertical_bottom_left_2_2 | part | 101.6 | 53.35524 | 53.35524 | Purchased ML24Z; six separately purchased SDS25112 screws; Manufacturer nominal geometry; actual fit, installation and resistance unqualified; NOT build-ready
clip_vertical_bottom_left_3_1 | part | 101.6 | 53.35524 | 53.35524 | Purchased ML24Z; six separately purchased SDS25112 screws; Manufacturer nominal geometry; actual fit, installation and resistance unqualified; NOT build-ready
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

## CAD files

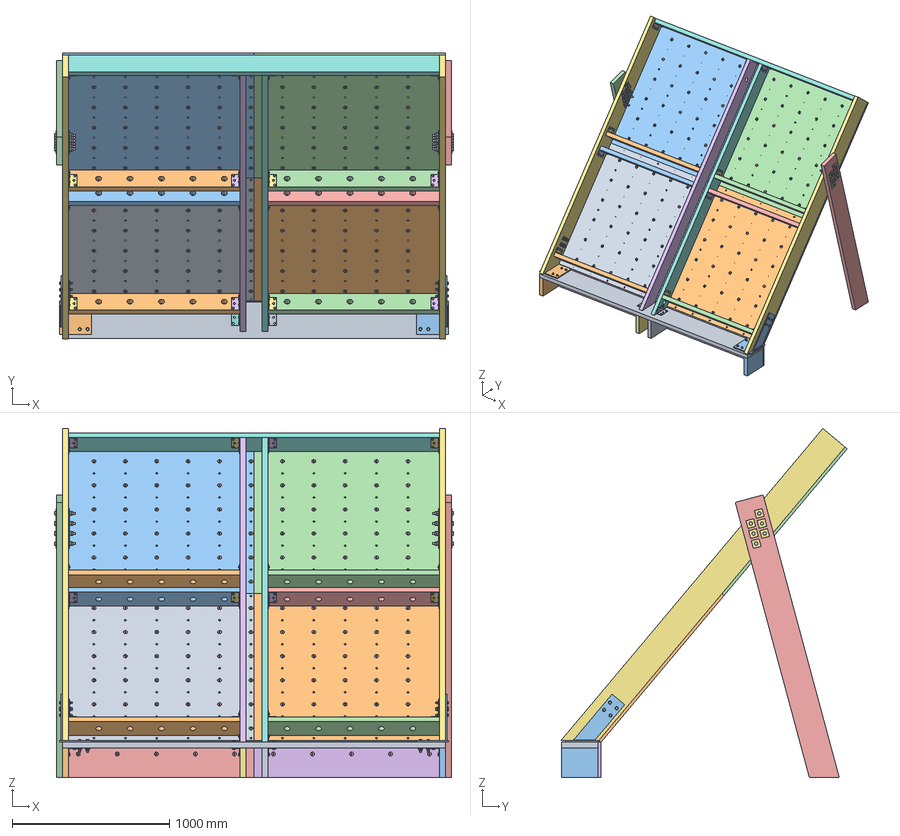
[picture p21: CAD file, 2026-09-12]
docs/wider-leg-review/assembly.step
2540.5 x 1823.5 x 2222.9 mm
main_lower_left
main_lower_right
main_upper_left
main_upper_right
kicker_left
kicker_right
base_side_left
base_side_right
base_rail_top
base_header
base_post_outer_left
base_post_outer_right
lumber_leg_left
lumber_leg_right
base_principal_center_left
base_post_center_left
base_principal_center_right
base_post_center_right
base_rail_bottom_left
base_rail_service_lower_left
base_rail_service_upper_left
base_rail_bottom_right
base_rail_service_lower_right
base_rail_service_upper_right
clip_single_top_left_1
clip_single_top_right_2
clip_timber_header_outer_left
clip_timber_header_outer_right
clip_split_top_center_left
clip_split_base_center_left
clip_split_header_center_left
clip_split_top_center_right
clip_split_base_center_right
clip_split_header_center_right
clip_horizontal_bottom_left_1
clip_horizontal_bottom_left_2
clip_horizontal_lower_left_1
clip_horizontal_lower_left_2
clip_horizontal_upper_left_1
clip_horizontal_upper_left_2
clip_horizontal_bottom_right_1
clip_horizontal_bottom_right_2
clip_horizontal_lower_right_1
clip_horizontal_lower_right_2
clip_horizontal_upper_right_1
clip_horizontal_upper_right_2
clip_steel_shoe_left
clip_steel_shoe_right
clip_plate_steel_shoe_rim_left_1
clip_plate_steel_shoe_rim_left_2
clip_plate_steel_shoe_rim_left_3
clip_plate_steel_shoe_rim_left_4
clip_plate_steel_shoe_header_left_1
clip_plate_steel_shoe_header_left_2
clip_plate_steel_shoe_header_left_3
clip_plate_steel_shoe_header_left_4
clip_plate_steel_shoe_rim_right_1
clip_plate_steel_shoe_rim_right_2
clip_plate_steel_shoe_rim_right_3
clip_plate_steel_shoe_rim_right_4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

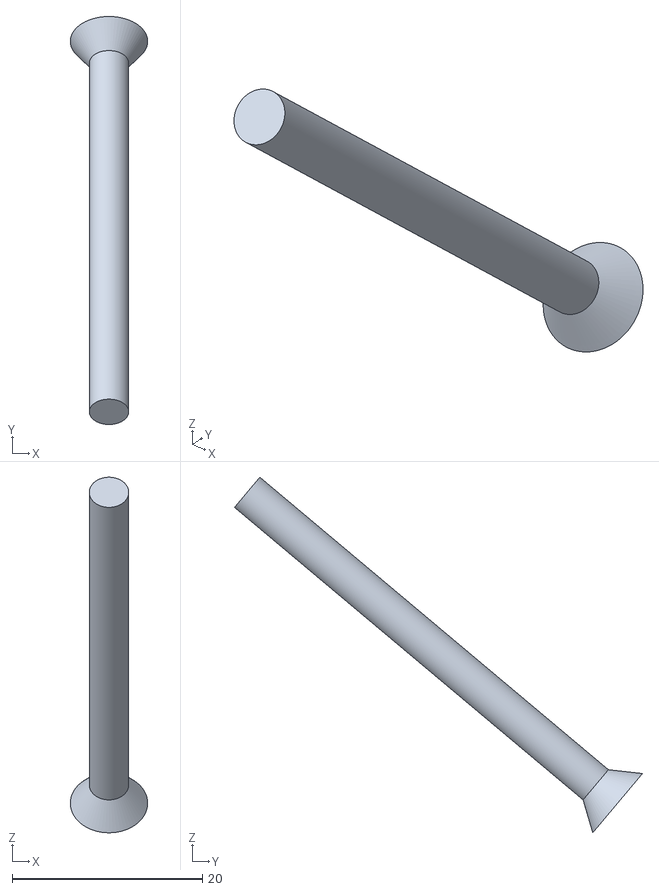
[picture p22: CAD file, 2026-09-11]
site/hybrid/angle-base-development/models/fastener_infill_main_lower_right_base_principal_right_2_3_2.stl
8.13 x 42.9 x 37.4

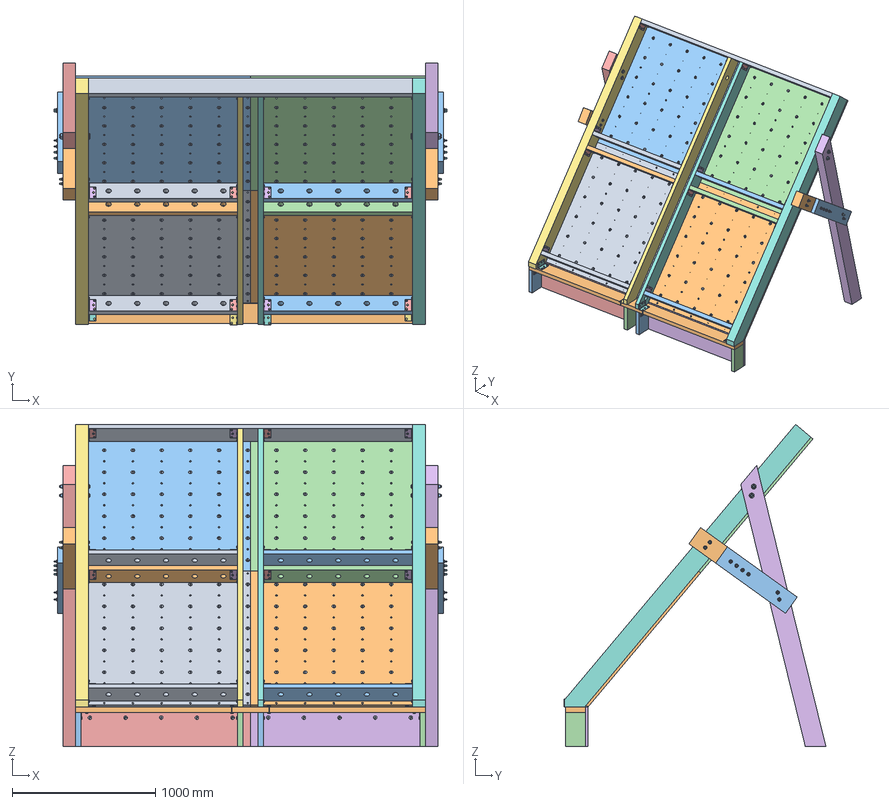
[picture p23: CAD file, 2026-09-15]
site/hybrid/compact-exterior-brace-development/assembly.step
2739.1 x 1825.7 x 2246.3 mm
main_lower_left
main_lower_right
main_upper_left
main_upper_right
kicker_left
kicker_right
base_side_left
base_side_right
base_rail_top
base_header
base_post_outer_left
base_post_outer_right
lumber_leg_left
lumber_leg_right
base_principal_center_left
base_post_center_left
base_principal_center_right
base_post_center_right
base_rail_bottom_left
base_rail_service_lower_left
base_rail_service_upper_left
base_rail_bottom_right
base_rail_service_lower_right
base_rail_service_upper_right
clip_single_top_left_1
clip_single_top_right_2
clip_timber_header_outer_left
clip_timber_header_outer_right
clip_split_top_center_left
clip_split_base_center_left
clip_split_header_center_left
clip_split_top_center_right
clip_split_base_center_right
clip_split_header_center_right
clip_angle_base_left
clip_angle_base_right
clip_horizontal_bottom_left_1
clip_horizontal_bottom_left_2
clip_horizontal_lower_left_1
clip_horizontal_lower_left_2
clip_horizontal_upper_left_1
clip_horizontal_upper_left_2
clip_horizontal_bottom_right_1
clip_horizontal_bottom_right_2
clip_horizontal_lower_right_1
clip_horizontal_lower_right_2
clip_horizontal_upper_right_1
clip_horizontal_upper_right_2
hold_tnut_main_A1
hold_tnut_main_A2
hold_tnut_main_A3
hold_tnut_main_A4
hold_tnut_main_A5
hold_tnut_main_A6
hold_tnut_main_A7
hold_tnut_main_A8
hold_tnut_main_A9
hold_tnut_main_A10
hold_tnut_main_A11
hold_tnut_main_A12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

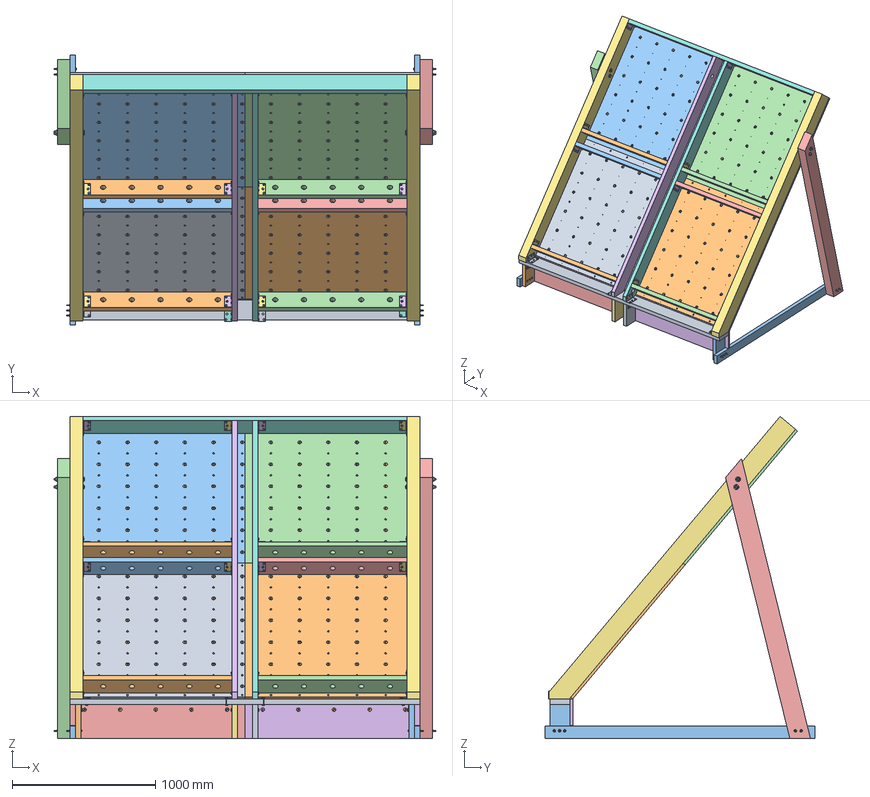
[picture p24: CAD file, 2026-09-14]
site/hybrid/compact-floor-rail-2x4-development/assembly.step
2663.8 x 1880.0 x 2246.3 mm
main_lower_left
main_lower_right
main_upper_left
main_upper_right
kicker_left
kicker_right
base_side_left
base_side_right
base_rail_top
base_header
base_post_outer_left
base_post_outer_right
lumber_leg_left
lumber_leg_right
base_principal_center_left
base_post_center_left
base_principal_center_right
base_post_center_right
base_rail_bottom_left
base_rail_service_lower_left
base_rail_service_upper_left
base_rail_bottom_right
base_rail_service_lower_right
base_rail_service_upper_right
clip_single_top_left_1
clip_single_top_right_2
clip_timber_header_outer_left
clip_timber_header_outer_right
clip_split_top_center_left
clip_split_base_center_left
clip_split_header_center_left
clip_split_top_center_right
clip_split_base_center_right
clip_split_header_center_right
clip_angle_base_left
clip_angle_base_right
clip_horizontal_bottom_left_1
clip_horizontal_bottom_left_2
clip_horizontal_lower_left_1
clip_horizontal_lower_left_2
clip_horizontal_upper_left_1
clip_horizontal_upper_left_2
clip_horizontal_bottom_right_1
clip_horizontal_bottom_right_2
clip_horizontal_lower_right_1
clip_horizontal_lower_right_2
clip_horizontal_upper_right_1
clip_horizontal_upper_right_2
hold_tnut_main_A1
hold_tnut_main_A2
hold_tnut_main_A3
hold_tnut_main_A4
hold_tnut_main_A5
hold_tnut_main_A6
hold_tnut_main_A7
hold_tnut_main_A8
hold_tnut_main_A9
hold_tnut_main_A10
hold_tnut_main_A11
hold_tnut_main_A12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

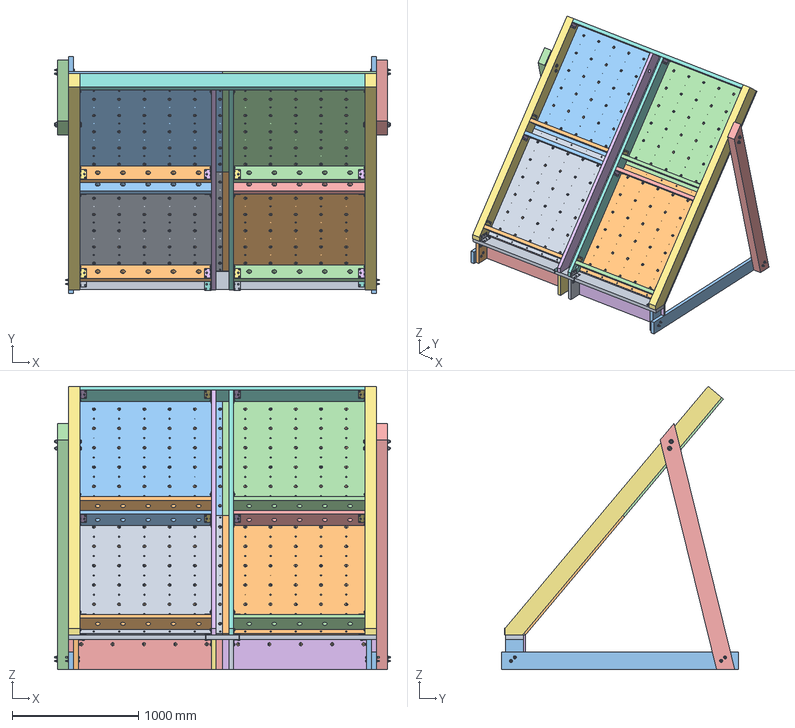
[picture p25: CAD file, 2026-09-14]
site/hybrid/compact-floor-rail-development/assembly.step
2662.9 x 1880.0 x 2246.3 mm
main_lower_left
main_lower_right
main_upper_left
main_upper_right
kicker_left
kicker_right
base_side_left
base_side_right
base_rail_top
base_header
base_post_outer_left
base_post_outer_right
lumber_leg_left
lumber_leg_right
base_principal_center_left
base_post_center_left
base_principal_center_right
base_post_center_right
base_rail_bottom_left
base_rail_service_lower_left
base_rail_service_upper_left
base_rail_bottom_right
base_rail_service_lower_right
base_rail_service_upper_right
clip_single_top_left_1
clip_single_top_right_2
clip_timber_header_outer_left
clip_timber_header_outer_right
clip_split_top_center_left
clip_split_base_center_left
clip_split_header_center_left
clip_split_top_center_right
clip_split_base_center_right
clip_split_header_center_right
clip_angle_base_left
clip_angle_base_right
clip_horizontal_bottom_left_1
clip_horizontal_bottom_left_2
clip_horizontal_lower_left_1
clip_horizontal_lower_left_2
clip_horizontal_upper_left_1
clip_horizontal_upper_left_2
clip_horizontal_bottom_right_1
clip_horizontal_bottom_right_2
clip_horizontal_lower_right_1
clip_horizontal_lower_right_2
clip_horizontal_upper_right_1
clip_horizontal_upper_right_2
hold_tnut_main_A1
hold_tnut_main_A2
hold_tnut_main_A3
hold_tnut_main_A4
hold_tnut_main_A5
hold_tnut_main_A6
hold_tnut_main_A7
hold_tnut_main_A8
hold_tnut_main_A9
hold_tnut_main_A10
hold_tnut_main_A11
hold_tnut_main_A12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

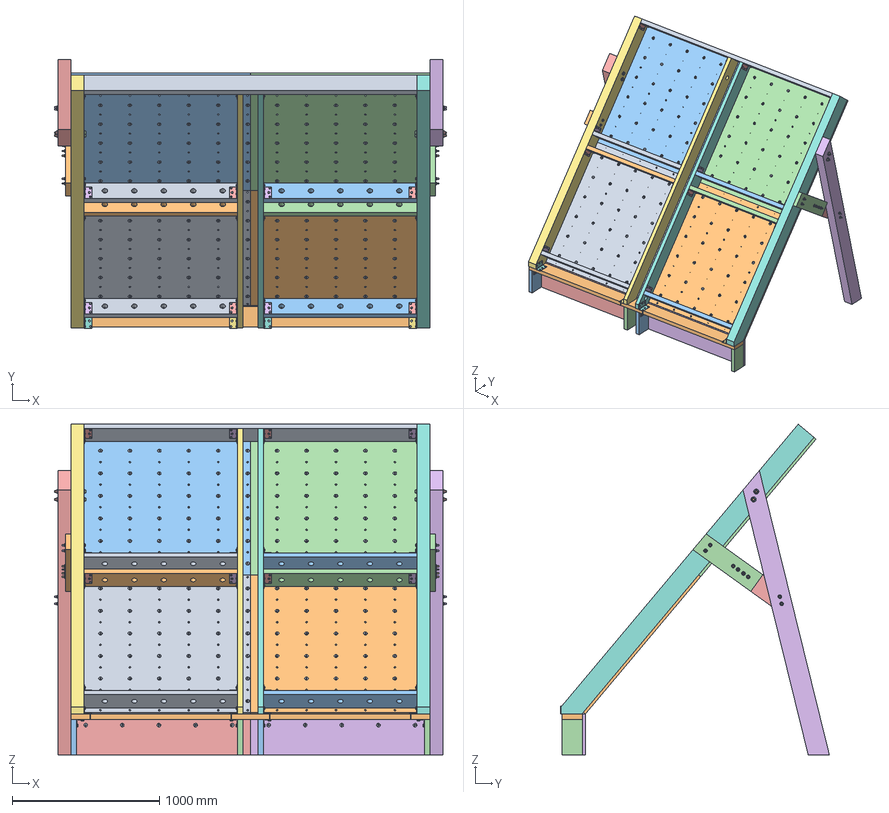
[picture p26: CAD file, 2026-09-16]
site/hybrid/compact-spliced-flush-top-development/assembly.step
2662.9 x 1825.7 x 2246.3 mm
main_lower_left
main_lower_right
main_upper_left
main_upper_right
kicker_left
kicker_right
base_side_left
base_side_right
base_rail_top
base_header
base_post_outer_left
base_post_outer_right
lumber_leg_left
lumber_leg_right
base_principal_center_left
base_post_center_left
base_principal_center_right
base_post_center_right
base_rail_bottom_left
base_rail_service_lower_left
base_rail_service_upper_left
base_rail_bottom_right
base_rail_service_lower_right
base_rail_service_upper_right
clip_single_top_left_1
clip_single_top_right_2
clip_timber_header_outer_left
clip_timber_header_outer_right
clip_split_top_center_left
clip_split_base_center_left
clip_split_header_center_left
clip_split_top_center_right
clip_split_base_center_right
clip_split_header_center_right
clip_angle_base_left
clip_angle_base_right
clip_horizontal_bottom_left_1
clip_horizontal_bottom_left_2
clip_horizontal_lower_left_1
clip_horizontal_lower_left_2
clip_horizontal_upper_left_1
clip_horizontal_upper_left_2
clip_horizontal_bottom_right_1
clip_horizontal_bottom_right_2
clip_horizontal_lower_right_1
clip_horizontal_lower_right_2
clip_horizontal_upper_right_1
clip_horizontal_upper_right_2
hold_tnut_main_A1
hold_tnut_main_A2
hold_tnut_main_A3
hold_tnut_main_A4
hold_tnut_main_A5
hold_tnut_main_A6
hold_tnut_main_A7
hold_tnut_main_A8
hold_tnut_main_A9
hold_tnut_main_A10
hold_tnut_main_A11
hold_tnut_main_A12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

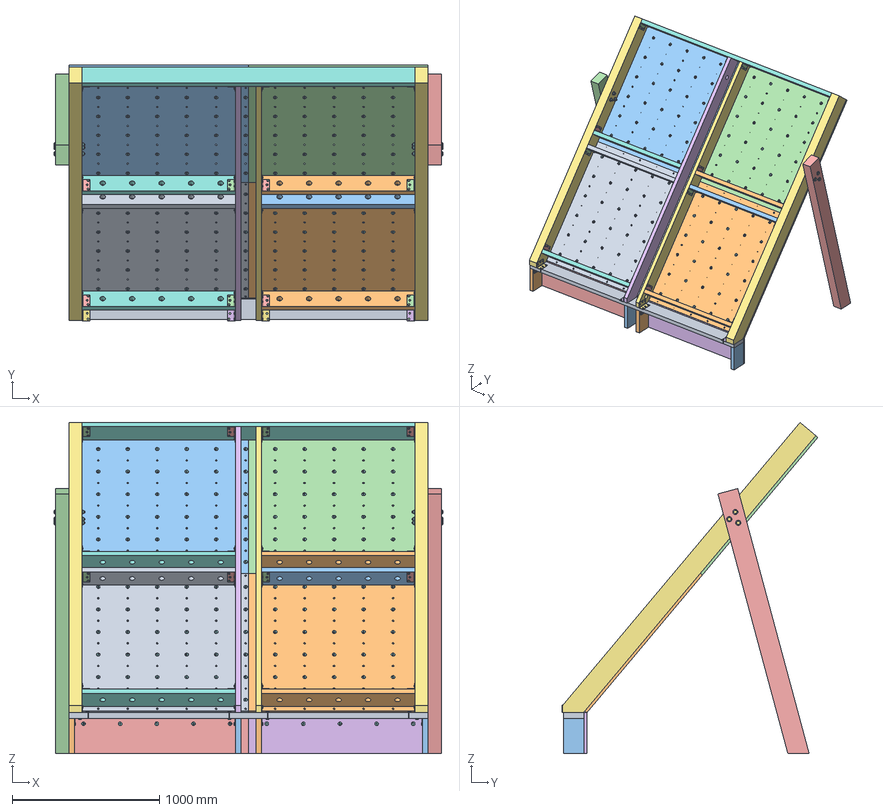
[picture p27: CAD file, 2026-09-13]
site/hybrid/compact-thick-development/assembly.step
2639.0 x 1735.4 x 2246.3 mm
main_lower_left
main_lower_right
main_upper_left
main_upper_right
kicker_left
kicker_right
base_side_left
base_side_right
base_rail_top
base_header
base_post_outer_left
base_post_outer_right
lumber_leg_left
lumber_leg_right
base_principal_center_left
base_post_center_left
base_principal_center_right
base_post_center_right
base_rail_bottom_left
base_rail_service_lower_left
base_rail_service_upper_left
base_rail_bottom_right
base_rail_service_lower_right
base_rail_service_upper_right
clip_single_top_left_1
clip_single_top_right_2
clip_timber_header_outer_left
clip_timber_header_outer_right
clip_split_top_center_left
clip_split_base_center_left
clip_split_header_center_left
clip_split_top_center_right
clip_split_base_center_right
clip_split_header_center_right
clip_angle_base_left
clip_angle_base_right
clip_horizontal_bottom_left_1
clip_horizontal_bottom_left_2
clip_horizontal_lower_left_1
clip_horizontal_lower_left_2
clip_horizontal_upper_left_1
clip_horizontal_upper_left_2
clip_horizontal_bottom_right_1
clip_horizontal_bottom_right_2
clip_horizontal_lower_right_1
clip_horizontal_lower_right_2
clip_horizontal_upper_right_1
clip_horizontal_upper_right_2
hold_tnut_main_A1
hold_tnut_main_A2
hold_tnut_main_A3
hold_tnut_main_A4
hold_tnut_main_A5
hold_tnut_main_A6
hold_tnut_main_A7
hold_tnut_main_A8
hold_tnut_main_A9
hold_tnut_main_A10
hold_tnut_main_A11
hold_tnut_main_A12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

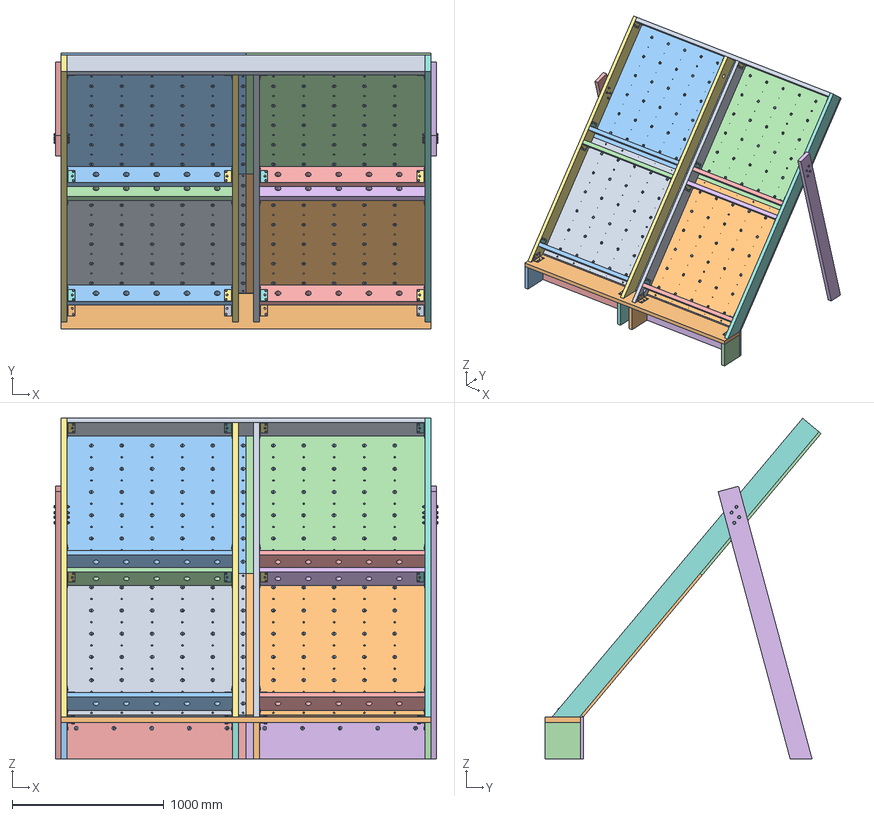
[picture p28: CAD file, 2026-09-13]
site/hybrid/no-shoes-development/assembly.step
2532.3 x 1820.5 x 2246.3 mm
main_lower_left
main_lower_right
main_upper_left
main_upper_right
kicker_left
kicker_right
base_side_left
base_side_right
base_rail_top
base_header
base_post_outer_left
base_post_outer_right
lumber_leg_left
lumber_leg_right
base_principal_center_left
base_post_center_left
base_principal_center_right
base_post_center_right
base_rail_bottom_left
base_rail_service_lower_left
base_rail_service_upper_left
base_rail_bottom_right
base_rail_service_lower_right
base_rail_service_upper_right
clip_single_top_left_1
clip_single_top_right_2
clip_timber_header_outer_left
clip_timber_header_outer_right
clip_split_top_center_left
clip_split_base_center_left
clip_split_header_center_left
clip_split_top_center_right
clip_split_base_center_right
clip_split_header_center_right
clip_angle_base_left
clip_angle_base_right
clip_horizontal_bottom_left_1
clip_horizontal_bottom_left_2
clip_horizontal_lower_left_1
clip_horizontal_lower_left_2
clip_horizontal_upper_left_1
clip_horizontal_upper_left_2
clip_horizontal_bottom_right_1
clip_horizontal_bottom_right_2
clip_horizontal_lower_right_1
clip_horizontal_lower_right_2
clip_horizontal_upper_right_1
clip_horizontal_upper_right_2
hold_tnut_main_A1
hold_tnut_main_A2
hold_tnut_main_A3
hold_tnut_main_A4
hold_tnut_main_A5
hold_tnut_main_A6
hold_tnut_main_A7
hold_tnut_main_A8
hold_tnut_main_A9
hold_tnut_main_A10
hold_tnut_main_A11
hold_tnut_main_A12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

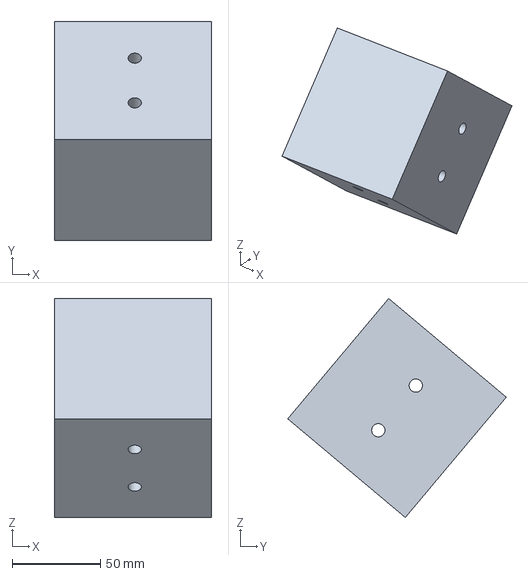
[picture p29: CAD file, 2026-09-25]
fea/results/diagnostics/wj24-baseline-patch-geometry-v1/wood/wj04_upper_g7_crosscut_full_stock_cleat.step
88.9 x 123.7 x 124.0 mm

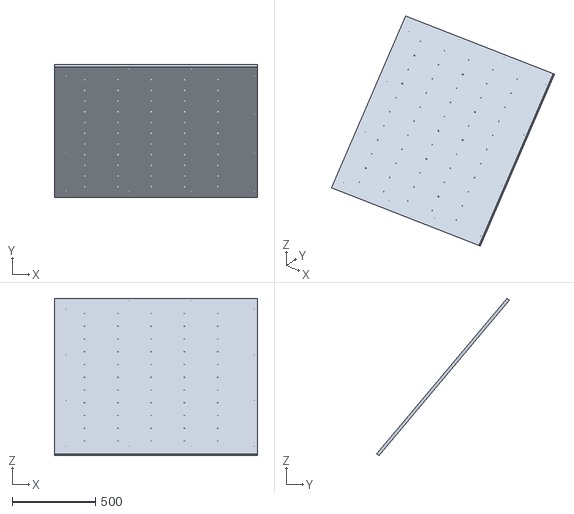
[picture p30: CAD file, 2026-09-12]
site/hybrid/round-insert-development/models/main_upper_right.stl
1219.2 x 797.7 x 945.7

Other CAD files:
site/hybrid/compact-floor-flush-development/assembly.step
site/hybrid/compact-floor-flush-kerf-right/assembly.step
site/hybrid/compact-floor-recess-development/assembly.step
site/hybrid/compact-floor-taper-development/assembly.step
site/hybrid/compact-spliced-knee-development/assembly.step
site/hybrid/thick-leg-centered-pivot-development/assembly.step
site/hybrid/angle-base-development/models/fastener_infill_main_lower_right_base_principal_right_2_2_2.stl
site/hybrid/angle-base-development/models/fastener_infill_main_lower_left_base_principal_left_1_1_2.stl
docs/leg-smooth-hardware-review/hardware.step
docs/wood-joints-mvp/hypotheses/evaluation-resume-2026-09-24/current-retained-bolt-access-attempt01/parent-export-attempt04/brep-export/modeled_wires/wire_001_A1_A2.step
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

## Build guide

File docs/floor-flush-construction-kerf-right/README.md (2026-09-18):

# Flush floor-beam construction coordinates

**Cut and drill sheets for `compact-floor-flush-development`. DIY documentation, not a factory release.**

This packet is for **4×8 plywood cut into two faces**. Each face is 1/16 in narrower; 1/8 in (3.175 mm) is missing at the right (K) edge because layout starts from the left. Bought 4×4 sheets are in [floor-flush-construction](../floor-flush-construction/). Six-case evidence remains the official geometry.

Shop instructions are in the [shop checklist](../floor-flush-shop-checklist.md) and
[assembly guide](../floor-flush-assembly-guide.md). Occupied CAD diameters and
`modeled_length_mm` values are analysis envelopes. Use the `shop_*` columns for
finished bolt-hole range, purchased Hillman length and SDS wood-lead-hole rules.

Candidate: `compact-floor-flush-development`. Width option: `kerf-right`. See
[the current package](../floor-flush-build-package.md) for evidence status.

- `stock.csv` gives stock allowances, not finished lengths.
- `stock-profiles.json` records actual trimmed raw timber vertices in world millimetres.
- Eight `*-bolt-sheet.svg` sheets show those actual profiles and relocated bolt axes.
- `bolt-member-datums.csv` and `profile-corner-datums.csv` share a physical corner datum,
  along-grain A and signed cross-grain C. Identify the corner on the sheet before layout.
- Leg taper sheets and `leg-taper-cuts.csv` specify separate inner-face removal.
- `runner-end-geometry.json` records the square front and inclined rear cut endpoints.
- `connection-axes.csv`, `panel-attachment-axes.csv`, `panel-hole-axes.csv` and
  `timber-passages.json` retain the current screw, panel and passage coordinates.
- `bolt-hardware.csv` describes current catalog bolt stacks plus shop hole-range columns.

Use numerical coordinates, not image scale. Left and right use their own physical
minimum-X datum: do not mirror a datum convention blindly. Kickers remain whole.
All timber profiles assume fresh stock; previous holes are not repair instructions.

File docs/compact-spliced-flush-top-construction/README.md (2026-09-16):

# Compact spliced flush-top construction coordinates

**Development package. Six fresh listed assembled cases meet their stated
splice/member criteria. Retained ML24Z/SDS separation and flange-couple
applicability remain an open completion gate. Do not fabricate from this packet.**

Candidate: `compact-spliced-flush-top-development`. See
[the matching build package](../compact-spliced-flush-top-build-package.md).

- Rear-leg tops are flush to the side-rim rear faces; side rims retain 7 mm rear reserve.
- Two half-inch upper bolts per leg use the relocated 56 mm-pitch pair.
- Four independent unnotched 2x6 knee pieces and all sixteen 3/8-inch knee bolts remain.
- All 20 complete bolt stacks point nuts and tips away from the climbing space.
- `stock-profiles.json` and `profile-corner-datums.csv` describe exact fresh-stock profiles.
- Eight bolt sheets and `bolt-member-datums.csv` dimension current bolt centres.
- `bolt-hardware.csv` names exact catalog candidates and delivered-part
  full-body/thread-transition acceptance thresholds for nominal-diameter use.
- Panel, kicker and service schedules retain 66 attachment axes and current passages.
- Fas-n-Tite/Hillman model 42605 screws are selected within the accepted panel
  scope. Their nominal 45.24375 mm timber penetration remains contained in the
  139.7 mm receivers; actual head/shank/thread geometry and product-specific
  design values remain unpublished and are not substituted into archived analysis.

Use numerical coordinates, not image scale. Left and right use their own physical
minimum-X datum. Do not reuse old upper holes or transfer prior case acceptance.
Catalog identity alone does not accept a delivered bolt. Measure full-body shank
through transition, count transition/runout as threaded, and verify nut seating
and full usable formed-thread engagement per the matching build package.

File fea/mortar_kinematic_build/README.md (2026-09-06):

# Separate kinematic observer build

This directory owns new v2 build/cube evidence only. It does not replace the
unmodified upstream baseline or v1 observer sources, images, binaries or reports.
The full-frame observer run remains on hold pending cube replay and review.

`python -m fea.mortar_kinematic_build.build` verifies immutable upstream image
`sha256:5adec98a0bb4f4cffbcc3fa15f5014db08621f1204b65cf1f130ff46d9cd32b0`,
snapshots the v1 and v2 generators and all build support, and builds with two
workers under a 300-second cap. The distinct tag is
`mini-moonboard-fea:ccx-kinematic-observer-2.21-v1`; the new binary is
`/usr/local/bin/ccx-kinematic-observer-2.21`. Existing tags are not overwritten.

The build manifest verifies the entire original 1176-file source inventory,
allowing only the two exact declared patched C files. Both patch generators,
the patched files, original binaries, linked libraries and compiler Makefile
are hash-bound; unchanged original binaries and libraries must remain intact.
The inherited baseline manifest records compiler and original-source details.

`python -m fea.mortar_kinematic_build.compare_cube BUILD_DIRECTORY` resolves the
successful build's immutable ID and verifies its actual manifest/binaries
before four bounded runs: two unchanged archived sliding cube decks, each with
unmodified upstream and the new observer. All printed displacement/reaction
coverage and values, STA histories and existing cube global checks are compared
against the retained original archive. Runs and source snapshots go to a unique
directory. None of these checks is a physical frame/joint capacity approval.

`uv run pytest tests/test_mortar_kinematic_build.py` tests failed-build exit
propagation and exact source-inventory rejection without Docker.

## Completed bounded evidence

`build-sxz5mfwe` completed successfully; immutable new image:
`sha256:8e84d8ad546cd98a861ceba3ccbf4c486b88f38a8b7e4c45f7784ace4cea21e1`.
`cube-9bidnnnr` preserves all four new runs. Both schedules exactly match the
archived printed displacement/reaction fields and STA histories, and pass the
existing global cube checks. The v2 reader checked all 28/45 calls, including
8/16 accepted coupling states, without checker or tolerance changes.

`report.json` binds the successful build, both generators, source/compiler
support, all raw comparison evidence and two complete replay artifacts in
`replay-lj6k7w_c`. The original publication and replay directory remain retained
as `initial-report.json` and `replay-cube-9bidnnnr`; the current publication uses
repository-relative references so evidence can be checked in another checkout.
The publication regression rehashes all four raw runs
and recomputes both complete replay artifacts. Original upstream/v1 evidence
is untouched. Independent segmentation and physical frame/floor/joint capacity
are not established; the full-frame run is still held for runner qualification.

Independent correctness, testing, and architecture/publication reviews found
no substantial remaining findings after portable references and default-CI test
collection were fixed. The focused patch, replay, and build/publication suite
passed 50 tests, including replay from a relocated checkout without Docker.

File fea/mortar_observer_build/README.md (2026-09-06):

# Separate diagnostic observer build

This is the build path for the [logging-only source patch](../mortar_observer/README.md),
not a validated solver or a new frame result. It uses the previously verified
unmodified upstream image by immutable ID and preserves both installed original
solver binaries. No packages, compiler flags or upstream Makefile are changed.

```sh
uv run python -m fea.mortar_observer_build.build
uv run python -m fea.mortar_observer_build.compare_cube
uv run python -m fea.mortar_observer_build.publish
uv run pytest tests/test_mortar_observer_patch.py tests/test_mortar_observer_build.py
```

The launcher refuses conflicting base/output tags. It creates a unique evidence
directory containing the exact Docker context, launch script, log and result.
The build is bounded to 300 seconds with two compiler workers. Only the two
patched source files are copied into the new image's build tree; all original
archive source hashes are checked against the upstream manifest, with precisely
those two declared exceptions. Original binaries, libraries and compiler
configuration are checked unchanged. The observer's resolved libraries must
also match that preserved inventory.

The observer executable is separately named `/usr/local/bin/ccx-observer-2.21`.
Its image must undergo unchanged small-cube output/history comparisons and
strict diagnostic replay before any full-frame diagnostic run. Compilation or
source insertion checks alone do not qualify its records, local contact law,
joint demands or the board's physical resistance.

## Retained small-cube evidence

The [publication](report.json) binds the successful build, four raw runs
(two cube decks × upstream/observer), and strict replay outputs. All printed
displacements/forces and accepted histories match the unmodified upstream
solver and original archive. Replay covers 28/45 contact calls, including
8/16 accepted increments and 72/144 eligible accepted node observations.
Neither cube has an accepted iteration-limit flag override.

Maximum absolute internal normal residual is approximately 2.603e-9 in both
cases; maximum absolute tangent component is 3.205e-6 / 1.604e-6. These are
reported internal weighted quantities, not millimetres of physical floor slip
or newly chosen acceptance thresholds. Tiny negative regularized openings and
positive friction excess remain in the reports; they are not clamped to zero.

Coverage is against the observer's declared inventory and accepted STA history.
The reader reconstructs weighted multipliers from raw arrays, but not the
full gap/displacement kinematics or contact segmentation. A full-frame run
still needs its launched deck's independent node/pair inventory and provenance
bound to the stream. No redesigned-frame result is provided by these cubes.

An independent test review found that the publication script could accept an
empty/incomplete run list. It now requires exactly four unique successful
case/binary combinations before writing outputs, with corruption regressions.
The retained solver executions and replay quantities did not change.

Independent numerical/source correctness, testing, and architecture/publication
reviews reported no remaining substantial findings after that fix. The 87
observer patch/replay/build tests passed. This review status applies to the
diagnostic implementation, not a professional structural audit.

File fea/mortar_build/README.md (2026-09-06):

# Separate unmodified CalculiX 2.21 baseline build

This build does not add an observer, change solver contact equations, replace
the packaged solver, or authorize a full-frame analysis. It prepares a known
upstream baseline for a later, separately reviewed instrumentation patch.

The parent image must have ID
`sha256:37671083a88ded305c4fcd83960a767dad4c2acb480976cb75fab5df261e2646`.
BuildKit needs a local image name rather than a bare image ID, so `build.py`
creates the separate alias `mini-moonboard-fea:base-37671083a88d` directly from
that ID and verifies the final image contains its complete filesystem-layer
prefix. It never changes `mini-moonboard-fea:box-v1`. Existing conflicting alias
or output tags are rejected rather than overwritten.

The [official upstream source](https://www.dhondt.de/ccx_2.21.src.tar.bz2) must
hash to `52a20ef7216c6e2de75eae460539915640e3140ec4a2f631a9301e01eda605ad`.
`Makefile.upstream` changes build configuration only: system SPOOLES/ARPACK/
LAPACK paths and modern gfortran's legacy-argument compatibility option.
It compiles the original upstream file lists, does not call the version-rewriting
`date.pl`, and verifies every original archive file is unchanged after building.
Compiler warnings are retained in the build log, not treated as validation.

```sh
uv run python fea/mortar_build/build.py
uv run python -m fea.mortar_build.compare_cube
uv run pytest tests/test_mortar_build.py
```

The build has a 900-second subprocess bound and uses two make workers. Evidence
goes into unique `baseline-*` directories. `/usr/bin/ccx` is checked unchanged
before/after dependency installation; the new binary is separately installed
as `/usr/local/bin/ccx-upstream-2.21`. Its manifest records the source archive,
every original source file, compiler versions, installed package versions,
resolved shared-library hashes, executable hashes and build-support hashes.
Dependency repository versions are recorded, not assumed forever immutable;
the resulting image ID identifies the actual build.

The comparison runs only the two existing archived bottom-supported sliding
cube MORTAR decks (increments 0.25 and 0.125), each with a 60-second bound and
two OpenMP threads. It compares original packaged solver/image, packaged solver
with newly installed libraries, and the new upstream solver. That three-way
split exposes library drift separately from upstream/build differences. Input
bytes are unchanged. Raw outputs, accepted-history equality, maximum printed
U/RF differences from the archived reference and existing external force/moment
checks are retained. Local weak-law validation remains explicitly open.

Do not infer bitwise equivalence or physical correctness from compilation.
Review the actual comparison report before using this image as an observer
baseline. A future observer must be built/tagged separately and compared with
this unmodified build first; no patch or modified binary belongs under its tag.

## Completed baseline

The [published build/comparison manifest](report.json) identifies image
`sha256:5adec98a0bb4f4cffbcc3fa15f5014db08621f1204b65cf1f130ff46d9cd32b0`.
All six cube executions matched the archived parsed U/RF values exactly and
had identical accepted-increment histories. Existing endpoint global checks
passed. This is printed-output equality on two small cases, not bitwise binary
equivalence or a local-law certificate. Tests replay every retained cube output
against the original archive and bind the build/support/evidence hashes.

The first two failed build attempts are retained: a BuildKit local-image-ID
resolution failure, then a missing `bzip2` extraction dependency. Neither reached
solver compilation. The successful build log, source/compiler/library manifest
and raw cube outputs remain in their uniquely named evidence directories.

### Review fixes and chronology

The reviewed launcher now exits nonzero after persisting a failed Docker build.
Before any comparison solve, it binds the successful build result and manifest
to publication hashes and checks the actual binaries inside the immutable image.
Every solve uses an image ID, never the mutable tag. Six new ID-bound cube runs
again matched the archived U/RF and accepted histories exactly; no rebuild was
needed. `report.json` points to those new runs and retains the original ones.

`pre-review-snapshot/` preserves the original two launcher scripts and original
publication with their original hashes. The successful image was built by that
older build launcher, not by the corrected current script. The new comparison
also contains its exact `compare_cube.launch.py` snapshot. These distinctions
prevent later support fixes from being presented as the source of earlier runs.

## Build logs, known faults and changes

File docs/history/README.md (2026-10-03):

# History

Older designs, experiments and lessons. The previous options remain available
in the [interactive viewer](https://mckayreedmoore.github.io/mini-moonboard/):
use its **Design** menu to compare them.

Start with the [design-history catalog](design-history.md) for milestones,
viewer links, successes, failures and sources for a presentation or writeup.
For the selected baseline, use [builder documents](../README.md). For the
ongoing candidate, use [wood-joint development](../wood-joints-mvp/README.md).

The [latest conditional wood-joint milestone](design-history.md#milestones-and-what-they-taught-us)
records completion of the working model/shop packet, including the separate
108-bolt knee proposal. The reviewed 104-bolt authority remains unchanged;
complete splitting, panel and delivered-hardware qualification remain open.
Packet completion does not establish a fabrication or climbing release.

Use the catalog's [archive reading groups](design-history.md#archive-reading-groups)
for earlier coordination snapshots, WJ layout studies and solver-method
research. These groups preserve the writeup trail without making old work
orders the starting point for ongoing work.

The chronological working-agreement log is [decision-log.md](decision-log.md).
Files in this folder keep their old names. Some internal links still use
previous paths; use the catalog's evidence links or locate the original path
in Git history. A historical document calling itself “current” does not change
the authority in [current-candidate.json](../../current-candidate.json).

Keep original geometry, viewer assets, results and rejected attempts alongside
the explanatory history. Numerical convergence, geometry fit and strength
acceptance describe different outcomes; preserve those distinctions when
retelling the project.

Archive grouping does not authorize removal or relocation. Earlier helpers,
geometry and saved receipts can still be consumed by the current packet.
Keep their original paths and frozen bytes; follow the
[archive and recovery workflow](../../CONTRIBUTING.md) before pruning any
closed raw run.

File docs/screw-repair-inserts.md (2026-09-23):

# Later insert option (not this build)

Build with the specified wood screws and the twelve bolt stacks. This note is
only a **later option**: if you take the plywood off often, or a wood screw
wears out, those screw holes can become threaded inserts. Do **not** drill
insert pilots now.

The twelve frame bolts already come apart. They stay bolts.

## What was checked

On `compact-floor-flush-development`, every **wood-screw** axis was screened
against the old E-Z LOK **801420-13** envelope (1/4-20, 13 mm long, 11.5 mm
outside diameter, drawing ±0.635 mm). The insert sits in the timber after the
plywood or after the ML24Z steel. Uncut receivers, current stations.

| Family | Count | Body in the wood | Inserts overlapping each other or a bolt |
| --- | --- | --- | --- |
| Hillman 42605 panel/kicker | 66 | Yes, including max drawing size | None |
| SDS25112 in ML24Z | 144 | Yes, including max drawing size | None |
| Frame bolts | 12 | Not an insert job | — |

Smaller hex inserts in the same family (10-24 **801024-13**, 8-32 **800832-10**)
also fit. Depth is not the limiter: after a 13 mm insert there is still about
126 mm of 2×6 behind every panel/kicker screw, and at least 24 mm behind every
SDS.

The tightest SDS axes are about **12.5 mm** from a wood surface (~6.7 mm of
wood outside a 1/4-20 body). Panel/kicker axes are about **19 mm** from a
surface (~13 mm outside that body). The header kicker row goes into the
**139.7 mm** depth of `base_header`, not through the 38 mm face height.

`tests/test_floor_flush_later_inserts.py` repeats the occupancy screen. Occupancy
is not a strength rating, split check, or machining release.

## Guides and numbers (revisited)

E-Z LOK’s own hex-drive page is for furniture, drawer pulls, display cases and
crating. Their [testing page](https://www.ezlok.com/testing) states that
results for hex-drive inserts **are not offered**; they send samples. There is
therefore **no published withdrawal, lateral, or edge-distance allowable** for
801420-13 in Douglas-fir. Metal-insert tensile tests (bolt breaks in aluminum
at about 5,000 lbf for 1/4-20) are not wood values.

What *is* published, and how our walls sit:

**Furniture (Woodcraft brass-insert guide, 2013).** Cross-grain: centerline at
least **2 × pilot diameter** from an edge. For their 1/4-20 (pilot 3/8 in) that
is **19.05 mm**. End grain: 1 × pilot. Spacing 4 × pilot. That guide is
knock-down furniture, not a climbing frame.

**Structural timber inserts (EOTA EAD 130324-00-0603).** Load-bearing inserts
are **steel**, outer thread 8–40 mm, outer length at least **1.2 d**, tip
penetration **3 d**, pre-drill 0.5–1 mm over the *inner* thread. Edge distances
default to Eurocode 5 Table 8.2 for **pre-drilled nails**, using the **outer**
diameter: unloaded edge **3 d**, loaded edge **(3+4 sin α) d**. For d = 11.5 mm
that is **34.5 mm** unloaded and up to **80 mm** loaded. A 13 mm zinc hex is
not that product (too short, wrong metal, inner/outer ratio ~0.55 vs the EAD
0.75–0.94 band). The EAD is the closest *structural* insert document; it does
not qualify this SKU.

**NDS analogue (dowel-type, D = insert OD).** Bolts/lags: unloaded edge
**1.5 D**, loaded edge perpendicular to grain **4 D**. For 11.5 mm that is
**17.3 mm** and **46 mm**. Wood screws smaller than 1/4 in have no NDS table;
commentary C12.1.5.7 suggests **2.5 D** edge when prebored. NDS 12.1.5.7 for
wood screws is “sufficient to prevent splitting.”

**What the SDS already is.** Simpson SDS25112 in DF: reference withdrawal
**172 lbf/in** of thread, **Wmax 170 lbf** for the 1-1/2 in screw (ESR-2236 /
C-F catalog). Steel-side shear about **250 lbf** (ESR-2236) to a few hundred
pounds depending on plate thickness. The **ML24Z** with six of those screws is
rated **595 lbf** F1 in DF (L-C-MLZ25). Those numbers apply to the SDS in that
angle, not to an insert.

**Our stations versus those rules (1/4-20, OD 11.5 mm, pilot 23/64 in):**

| Station | Axis to face | vs Woodcraft 2×pilot (19 mm) | vs NDS 1.5 D (17 mm) | vs EC5 3 d (35 mm) | vs NDS 4 D (46 mm) |
| --- | --- | --- | --- | --- | --- |
| 66 panel/kicker | **19 mm** | Meets | Meets | No 2×6 face can | No |
| 110 SDS | ≥19.5 mm (most ≥25 mm) | Meets | Meets | 86 of 144 meet 3 d | No |
| **34 SDS** (outer ML24Z holes, front of 2×6) | **12.5 mm** | Miss | Miss | Miss | Miss |

Pilot clearance is not the issue: even at 12.5 mm there is ~8 mm of wood
outside the 23/64 in bit. The 34 tight SDS holes leave ~6.8 mm of fir outside
a 1/4-20 *body*. That is enough for occupancy, not enough for the furniture
2×pilot rule or a timber 1.5 D / 3 d wall. An 8-32 hex (OD 6.9 mm) is the
only size in this family that meets Woodcraft 2×pilot at those 34; it still
misses EC5 3 d.

So: panel conversion at 19 mm matches the only published *furniture* edge
rule for this insert size. SDS conversion has no catalog strength, drops the
Simpson joint, and at 34 holes does not have the wall those guides want for a
1/4-20 body. Do not move the frame for this. Leave SDS as SDS unless you
accept an unrated angle joint and, on those 34, a smaller insert.

Inserts that **publish** timber strengths and edge distances (RAMPA
ETA-12/0481 and related paths) are sketched in
[structural-insert-options.md](structural-insert-options.md). That study does
not change this build.

## If you convert later

1. **Bolts:** replace the bolt.
2. **Hillman (66):** take the plywood off. Open the plywood hole to a machine-screw
   clearance (the old study used 7 mm; that is a size check, not a bit call).
   Drill the timber to the insert pilot (23/64 in for 801420-13, 9/32 in for
   801024-13, 15/64 in for 800832-10). Seat the insert in the timber, slightly
   below the wood face. Use a 1/4-20, 10-24, or 8-32 machine screw through the
   plywood into the insert. Measure the real edge before driving an 11.5 mm
   body at a 19 mm row.
3. **SDS (144):** leave the ML24Z holes as they are (**6.731 mm**). Do not
   enlarge the steel. A 1/4-20 screw (major diameter up to 6.32 mm) is a snug
   pass through that hole; 10-24 or 8-32 pass more easily. The insert goes in
   the timber under the angle. This is **not** a Simpson SDS25112 joint any
   more: listed ML24Z values do not apply to an insert plus a machine screw.
   At the 34 outer-hole stations with only 12.5 mm to the front of the 2×6,
   do not use 1/4-20 if you care about insert wall; 8-32 is the size that
   meets the furniture 2×pilot rule there.

Do not mix leftover Hillman or SDS into an insert hole. Do not pre-drill
insert pilots “just in case” while you are still using wood screws.

## What this does not do

It does not install inserts, pick a repair kit, or give torque, engagement, or
allowable load. The old `round-insert-development` study used 56 panel screws
on a different frame; do not copy its counts or resistance. Repeated assembly
of the **angles** is a different connection once the SDS are gone. Whole-wall
moves should still separate at the twelve bolts and lift the plywood; you do
not have to convert SDS in order to move.

Inserts that **publish** timber strengths and edge distances are sketched in
[structural-insert-options.md](structural-insert-options.md). That study does
not change this build.

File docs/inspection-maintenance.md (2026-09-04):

# Inspection and maintenance program

This is a release-gated record format, not an approved inspection interval or
structural assessment. The qualified reviewer must set the final inspection
scope, acceptance criteria, responsibilities, and intervals after the frame,
connections, floor interface, and impact area are designed.

## Before construction is released

The final program must identify:

- the responsible owner and the person qualified to inspect structural items;
- the applicable standard editions and reviewer-specified inspection intervals;
- every load-bearing member, connection, floor interface, and panel attachment;
- every hold, T-nut, LED, cable, control box, and power supply to be checked;
- the impact-attenuating surface and fall-zone arrangement; and
- the shutdown and repair authority if a defect is found.

## Commissioning record

Before climbing, record the approved commit/tag, installation date, reviewer,
as-built measurements, pad arrangement, and photographs of all sides and
connections. The reviewer must confirm that the built assembly matches the
released design or has approved every recorded deviation.

Do not commission the wall if the frame, connections, pads, electrical system,
or installation record is incomplete.

## User pre-climb check

Before use, the responsible user should confirm that:

- the crash pads and fall area are in their approved deployed arrangement,
  without gaps, displaced sections, or new obstructions;
- no panel, hold, fastener, support, or foot appears loose, damaged, wet,
  cracked, delaminated, or displaced; and
- no LED wiring, connector, control box, or power-supply component is exposed,
  damaged, or hot.

If any item is questionable, keep the wall out of service until the responsible
person and, where relevant, the reviewer evaluate it. Disconnect electrical
power before electrical inspection or repair, and follow the LED-system
manufacturer's instructions.

## Periodic and event-triggered inspection

The final reviewer-approved checklist must cover at least these groups:

| Group | Record observable condition and action |
| --- | --- |
| Climbing panels | Surface damage, splits, delamination, swelling, edge damage, mounting condition, seams, and insert integrity |
| Holds and hold hardware | Loose, spinning, damaged, or missing parts; do not invent torque values without the selected hardware specification |
| Frame and joints | Cracks, delamination, crushing, member movement, loose fasteners, connector damage, and changes to bracing |
| Feet and floor interface | Wear, sliding, indentation, uneven support, floor damage, and moisture; anchoring is not permitted in V1, and any future attachment requires a controlled scope revision |
| Impact surface | Coverage, pad gaps, compression damage, migration, moisture, tears, and obstruction-free fall zone |
| LEDs and electrical system | Damaged lights, wires, connectors, strain relief, control box, and power supply; use only the applicable official guide |

Perform an additional inspection after relocation, a significant impact or
collision, water exposure, a suspected overload, a new structural noise or
movement, any alteration, or an extended period out of use.

## Inspection record

| Field | Record |
| --- | --- |
| Date and time | **unresolved** |
| Inspector and qualification | **unresolved** |
| Approved commit/tag | **unresolved** |
| Trigger or interval | **unresolved** |
| Items inspected | **unresolved** |
| Defects or deviations | **unresolved** |
| Wall status: in service / restricted / out of service | **unresolved** |
| Corrective action and due date | **unresolved** |
| Reviewer disposition, if required | **unresolved** |

Link every corrective action to a record in
[`change-control.md`](change-control.md). A repair that alters any structural
or controlled component must follow the same review process as a design change.

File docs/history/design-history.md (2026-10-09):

# Design history: models, results and lessons

This catalog keeps the previous options explorable and provides starting
material for a presentation or writeup. It is a reading order, not a claim that
every design was built or tested physically. The selected baseline is governed
by [current-candidate.json](../../current-candidate.json); the active compact bolted-frame
candidate has a [separate entry point](../bolted-frame-development/README.md).

Open the [interactive viewer](https://mckayreedmoore.github.io/mini-moonboard/)
and use **Design** to compare options. Historical menu choices are retained;
the complete link list below preserves the viewer's descriptive labels. Labels
such as “selected” or “current” in historical names are not today's authority.
The [decision log](decision-log.md) records the sequence and changing constraints.

## Milestones and what they taught us

| Design question | Result worth preserving | Models and primary records |
| --- | --- | --- |
| How should the original wall and backing fit together? | The plywood/hybrid and early connector studies preserve the geometry exploration. Their presence in the viewer is not a strength pass. | [Plywood reference](https://mckayreedmoore.github.io/mini-moonboard/?model=plywood), [early joint study](https://mckayreedmoore.github.io/mini-moonboard/?model=joint-development), [reference analysis](reference-analysis.md) |
| Could a compact lumber frame also accommodate wiring and removable panels? | Separate service-passage, panel attachment and insert options made the tradeoffs visible. Insert studies remain unqualified alternatives. | [Horizontal service frame](https://mckayreedmoore.github.io/mini-moonboard/?model=horizontal-service-development), [round passages](https://mckayreedmoore.github.io/mini-moonboard/?model=round-bore-service-development), [insert study](round-insert-analysis.md), [service analysis](round-service-analysis.md) |
| Was a passing leg-member check enough? | No. The assessed single 2×6 member passed its chosen case, but its connection failed. A longer-bolt/washer revision fit geometrically without solving the connection problem. | [Four-bolt frame](https://mckayreedmoore.github.io/mini-moonboard/?model=round-reinforcement-development), [leg assessment decision](leg-completion-decision.md) |
| Would larger bolts and wider patterns fix that joint? | No passing candidate was found within the investigated four-bolt family while retaining the single 2×6 leg and rim. This is a bounded negative result, not a verdict on every possible bolted joint. | [Bolt-pattern investigation](leg-bolt-pattern-decision.md), [wider-leg direction](wider-leg-decision.md), [2×8 model](https://mckayreedmoore.github.io/mini-moonboard/?model=wider-leg-development) |
| Could knees and splices improve the compact frame? | The knee trial recorded an initial interference and a revised fit; its machined-joint mechanics still required separate checks. The later spliced flush-top candidate passed all 21 listed conditional checks in six fresh cases, with bracket actions still unresolved. | [Knee trial](compact-knee-study.md), [spliced-knee model](https://mckayreedmoore.github.io/mini-moonboard/?model=compact-spliced-knee-development), [flush-top results](compact-spliced-flush-top-study.md), [flush-top model](https://mckayreedmoore.github.io/mini-moonboard/?model=compact-spliced-flush-top-development) |
| Could the floor-runner version reach a bounded analytical target? | The selected screw-and-bracket baseline has six authenticated no-slip cases passing 36 adopted checks. Unlisted bracket separation/couple actions and other recorded assumptions remain limitations. | [Selected model](https://mckayreedmoore.github.io/mini-moonboard/?model=compact-floor-flush-development), [case record](../floor-runner-mvp-case-log.md), [criteria](../floor-runner-mvp-criteria.md), [completion ledger](../floor-runner-mvp-completion-ledger.md) |
| What happened when a solve did not converge? | A12-forward had three rejected contact searches before a fourth converged in 69 cycles under the same physical assumptions and final gates. A numerical search failure was not silently treated as a physical failure or an accepted result. | [Search history](../floor-runner-mvp-case-log.md#numerical-search-history), [six-case evidence](../floor-runner-mvp-evidence.json) |
| Could routine structural wood-screw removal be replaced by bolted connections? | V4, corner-block and barrel-nut layouts explored different paths. The later direction selected wood blocks for development; their predecessors remain valuable geometry and access studies, not accepted block capacities. | [Bolted plan](../bolted-candidate-plan.md), [V4 model](https://mckayreedmoore.github.io/mini-moonboard/?model=bolted-v4-development), [corner model](https://mckayreedmoore.github.io/mini-moonboard/?model=owner-corner-layout), [barrel model](https://mckayreedmoore.github.io/mini-moonboard/?model=owner-barrel-layout) |
| What did the detailed wood-joint simulation effort achieve and cost? | It produced useful method checks and exposed numerical problems, but did not establish a passing current joint. The September 29 direction uses whole-frame static demands and applicable connection checks, with detailed local work reserved for unresolved mechanisms. | [Reviewed WJ24 viewer](https://mckayreedmoore.github.io/mini-moonboard/wood-joints-wj24-viewer.html), [solver assessment](../wood-joints-mvp/solver-reuse-assessment-2026-09-27.md), [analysis reassessment](../wood-joints-mvp/hypotheses/mvp-acceleration-2026-09-28/README.md) |
| Could the simpler wood-joint route finish a coherent conditional model and shop packet? | The conditional packet is complete: six zero/nominal cases, joined joint/member actions, finite fit checks, assembly/removal, transport, BOM and cost terms. The reviewed authority remains 104 bolts / 208 washers; the unadopted knee proposal has 108 bolts / 216 washers. Both retain 50 bodies and 66 Hillman screws. Complete splitting resistance, the panel reference exception, actual hardware properties and compatibility remain unqualified; all 47 formal criteria remain pending and all eight release flags remain false. | [Goal disposition](../wood-joints-mvp/hypotheses/mvp-resume-2026-10-01/upper-corner-screw-layout/mvp-joint-disposition.md), [bound proposal packet](../wood-joints-mvp/hypotheses/mvp-resume-2026-10-01/upper-corner-screw-layout/knee-bridge-working-package.md), [reviewed authority](../../wood-joints-candidate.json), [conditional shop guide](../wood-joints-mvp/hypotheses/mvp-resume-2026-10-01/assembly-package/shop-guide.md) |

## Eoere development sequence

The current geometry is **`eoere-raised-kicker-screws-v1`**:
[current viewer](https://mckayreedmoore.github.io/mini-moonboard/?model=eoere-kicker-clearance-frame-development&view=rear).
Use the [maintained revision map](../bolted-frame-development/README.md#revision-map) and
[checked index](../bolted-frame-development/development-revisions.json) for the separate
shop, response and proposal scopes. These milestones preserve preceding questions, changes
and evidence boundaries; their design history can still supply active inputs.

| Milestone | Change and useful result | Primary record / viewer |
| --- | --- | --- |
| Original Eoere proposal | Replaced earlier connector concepts with 22 angles and two exterior cleats; retained 100 through-bolt stacks and 66 Hillman screws. Original A12 evidence stays scoped to that geometry. | [Frozen proposal contract](../../eoere-bolted-candidate.json) · [original viewer](https://mckayreedmoore.github.io/mini-moonboard/?model=eoere-bolted-development&view=rear) |
| Raised lower rails | Moved the lower rails and dependent stations for T-nut clearance. Completed the conditional six-case response and nominal shop packet, retaining exceedances and unknown complete joint resistance. | [Six-case receipt](../wood-joints-mvp/hypotheses/hl35-candidate/thin-frame-comparison/eoere-successor-v1/fixed-floor-numerical-mvp-v1.json) · [raised-rail viewer](https://mckayreedmoore.github.io/mini-moonboard/?model=eoere-bolted-bottom-rail-development&view=rear) |
| Trimmed cleats | Cut projecting rear corners while retaining thickness and axes. Geometric containment and display results do not transfer the raised-rail response. | [Trim receipt](../wood-joints-mvp/hypotheses/hl35-candidate/thin-frame-comparison/eoere-successor-v1/occupied-cleat-trim-v1.json) · [trimmed-cleat viewer](https://mckayreedmoore.github.io/mini-moonboard/?model=eoere-bolted-trimmed-cleats-development&view=rear) |
| Aligned wire passages | Aligned 30 rail routes to the original grid, preserving endpoints and bolt/screw axes. This introduced a distinct service-cut revision. | [Aligned-wire receipt](../wood-joints-mvp/hypotheses/hl35-candidate/thin-frame-comparison/eoere-successor-v1/occupied-aligned-wire-v1.json) · [aligned-wire viewer](https://mckayreedmoore.github.io/mini-moonboard/?model=eoere-bolted-aligned-wire-development&view=rear) |
| Adjusted base v3 | Shifted the right principal 39.2 mm and coordinated three longer rails, 22 moved shafts and ten moved screws. Nominal backing/contact checks pass; no matching response is admitted. | [Base receipt](../wood-joints-mvp/hypotheses/hl35-candidate/thin-frame-comparison/eoere-successor-v1/occupied-adjusted-base-v3.json) · [adjusted-base viewer](https://mckayreedmoore.github.io/mini-moonboard/?model=eoere-adjusted-frame-development&view=rear) |
| Optional 2026 midpoint grid | Added an unofficial preview of 120 T-nuts/lights and 119 cable links. Exact midpoints and actual hold availability remain provisional; this is a separate layer. | [Extra-grid receipt](../wood-joints-mvp/hypotheses/hl35-candidate/thin-frame-comparison/eoere-successor-v1/occupied-2026-adjustments-v3.json) · [pre-extension extra-grid viewer](https://mckayreedmoore.github.io/mini-moonboard/?model=eoere-new-2026-adjustments&view=rear) |
| Extended side cleats and matching shop records | Extended two full-thickness cleats to the sloping side edge and issued profiles, datums and nesting. Four cleat/post stations remain held in that packet; later response and geometry revisions keep their own bindings. | [Extension receipt](../wood-joints-mvp/hypotheses/hl35-candidate/thin-frame-comparison/eoere-successor-v1/occupied-extended-cleats-v1.json) · [preserved viewer](https://mckayreedmoore.github.io/mini-moonboard/?model=eoere-extended-cleat-frame-development&view=rear) · [preceding shop packet](../wood-joints-mvp/hypotheses/hl35-candidate/thin-frame-comparison/eoere-successor-v1/shop-assembly-v1/extended-cleat-followup-v1/README.md) |
| Fresh extended-cleat numerical packet | Completed six own-case equilibrium/recovery audits and twelve component reports. Exceedances, first-order/floor assumptions, four held cleat/post stations and unknown complete-joint resistance remain explicit. | [Current result and review bindings](../wood-joints-mvp/completion-ledger.md#current-extended-cleat-numerical-completion) |

The [pre-compaction Eoere summary](eoere-development-summary-before-compaction.md)
preserves the full 1,270-line text from `845e2e0c`, including its thin-frame
predecessors and old next actions. Its original payload SHA-256 is
`179f917091aeb555c5c95e99916c94fa0dbdae1356e88bfd9f5482f1a571052f`.
Relative links inside that payload use its original directory, as stated in
the snapshot. [Browse the original summary at its frozen commit](https://github.com/mckayreedmoore/mini-moonboard/blob/845e2e0cf2bf1514398e115c382865579fd77141/docs/wood-joints-mvp/README.md)
to follow those links in their original context. The [earlier wood-joint summary](wood-joint-development-summary-before-navigation-cleanup.md)
retains the separate WJ24 working-model record. Neither snapshot is a current
task queue.

## Archive reading groups

Use these groups to follow the decisions and methods behind the latest packet.
For ongoing work, start at [Eoere development](../bolted-frame-development/README.md)
and follow its current disposition. Earlier documents retain their original
titles, labels, force sources and work orders. A historical “current” label or
unfinished next-step instruction describes that snapshot; it does not reopen
a task or change today's authority.

| Reading group | What to preserve and learn | Starting records |
| --- | --- | --- |
| Eoere and thin-frame predecessors | Preserve each geometry/response boundary and the old-action limits of bounded component studies. Keep inherited geometry, source banks and methods live wherever current work consumes them. | [Eoere sequence](#eoere-development-sequence), [full preserved summary](eoere-development-summary-before-compaction.md), [bounded studies](../wood-joints-mvp/hypotheses/hl35-candidate/thin-frame-comparison/eoere-successor-v1/bounded-strength-v1/README.md) |
| Superseded coordination and publication snapshots | Earlier ownership, restart sequence and publication boundaries explain how the work progressed. Their task queues and next actions are historical instructions; preserve any still-applicable engineering requirements separately from old execution order. | [Orchestration handoff](../wood-joints-mvp/orchestration-handoff.md), [full MVP handoff](../wood-joints-mvp/luna-max-completion-handoff.md), [September 29 checkpoint](../wood-joints-mvp/hypotheses/mvp-acceleration-2026-09-28/LUNA-MAX-COORDINATOR-CURRENT-CHECKPOINT-2026-09-29.md), [source-only publication checkpoint](../wood-joints-mvp/code-summary-checkpoint-2026-09-30.md), [earlier parallel-owner handoff](../wood-joints-mvp/parallel-owner-handoff-2026-10-01.md) |
| Earlier WJ layouts and integration trials | Preserve geometry, access conflicts, receiver changes and the distinction between a static diagnostic and an accepted joint. These predecessors also contain inherited sources used by later work. | [WJ-03 / WJ-04 / WJ-05 viewer](https://mckayreedmoore.github.io/mini-moonboard/wood-joints-outer-viewer.html), [WJ16 inputs](../wood-joints-mvp/hypotheses/wj16-full-stock-mechanics-inputs/README.md), [WJ18 diagnostic](../wood-joints-mvp/hypotheses/wj18-integrated-static/README.md), [WJ24 diagnostic](../wood-joints-mvp/hypotheses/wj24-integrated-static/README.md) |
| Code_Aster and closed solver-method investigations | Keep passing primitive fixtures, numerical failures and output/source findings with their exact applicability limits. A passing method fixture is reusable evidence, not complete-joint acceptance or a standing instruction to repeat the experiment. | [Solver reuse decision](../wood-joints-mvp/solver-reuse-assessment-2026-09-27.md), [Code_Aster primitive results](../wood-joints-mvp/hypotheses/code-aster-stock-trial-2026-09-27/RESULTS.md), [shared-edge MORTAR failure](../wood-joints-mvp/hypotheses/evaluation-resume-2026-09-24/contact-mortar-shared-edge-known-answer-attempt02/README.md), [elastic matrix export method](../wood-joints-mvp/hypotheses/elastic-matrix-export-method-2026-09-30/README.md) |

This is an archive reading order, not a list of directories safe to prune.
Current producers still consume some earlier geometry, operators, helpers and
receipts. All primary evidence stays at its original paths; no frozen bytes,
viewer choices or sources are moved by this catalog. Closed bulky raw runs
can be archived only after ownership and consumer checks and verified recovery
under the [contributor workflow](../../CONTRIBUTING.md). Existing archive
locations and recovery instructions are in the
[cleanup record](../repository-cleanup-evaluation-2026-09-28.md).

## Material for a presentation or writeup

Use the milestones as chapters: initial constraints, geometry exploration,
connection failures, the bracketed baseline's bounded success, removable-joint
alternatives, analysis-method lessons and the completed conditional wood-joint
packet with its remaining qualification limits. Keep the limitations
beside each result rather than combining different revisions into one pass.

For each chapter, preserve the exact candidate/revision, the problem it aimed
to solve, the model link, a front/rear or joint-detail image, the result and its
source, and the reason for the next change. Existing visual material includes
the [baseline diagrams](../floor-flush-diagrams/), the two
[4×4](../floor-flush-construction/) / [kerf-right](../floor-flush-construction-kerf-right/)
construction packets, [historical exports](../../exports/), and meshes and
metadata under [site/hybrid](../../site/hybrid/). The interactive viewers supply
the source scenes for future comparable screenshots; this catalog does not
claim to have captured new images.

Retain original result bundles under [fea/results](../../fea/results/) and the
[wood-joint experiments](../wood-joints-mvp/hypotheses/), including failed runs
that support the narrative. Older documents can contain obsolete relative paths;
locate their source by original path/commit instead of rewriting frozen evidence.

Distinguish these outcomes explicitly:

- **Geometry or access result:** whether modeled parts, holes or tools fit.
- **Numerical result:** whether a method solved its stated equations and met its
  numerical checks.
- **Strength result:** whether applicable resistance checks passed under the
  recorded loads and assumptions.
- **Open question or preference:** missing evidence or an owner design choice,
  neither of which proves physical failure.

No cleanup should remove a currently available viewer choice, its required
assets, or the evidence needed to explain a success or failure. Archive complete
studies together; delete only scratch files established to be redundant and
unused. See the [retention evaluation](../repository-cleanup-evaluation-2026-09-28.md).

## Complete viewer collection

These are the 70 main-viewer choices recorded on September 29, 2026, in menu
creation order. Their original descriptive labels are retained as historical
metadata, not independently renewed engineering claims. The two wood-joint
viewers are separate pages:

- [Reviewed WJ24 block layout](https://mckayreedmoore.github.io/mini-moonboard/wood-joints-wj24-viewer.html)
- [Earlier WJ-03 / WJ-04 / WJ-05 trials](https://mckayreedmoore.github.io/mini-moonboard/wood-joints-outer-viewer.html)

The `2x10`, `2x12`, `2x8-shallow` and `2x8-foot100` assets are generated by the
[Pages workflow](../../.github/workflows/static.yml); those four manifests are
not present in this local checkout. The published viewer links are retained.
This catalog update does not rerun their CAD exporters or verify the live site.

| Viewer option | Stable model key |
| --- | --- |
| [Plywood reference](https://mckayreedmoore.github.io/mini-moonboard/?model=plywood) | `plywood` |
| [2×12 hybrid candidate](https://mckayreedmoore.github.io/mini-moonboard/?model=2x12) | `2x12` |
| [2×10 hybrid candidate](https://mckayreedmoore.github.io/mini-moonboard/?model=2x10) | `2x10` |
| [2×8 rotated-rear candidate](https://mckayreedmoore.github.io/mini-moonboard/?model=2x8-shallow) | `2x8-shallow` |
| [2×8 with 100 mm extended feet](https://mckayreedmoore.github.io/mini-moonboard/?model=2x8-foot100) | `2x8-foot100` |
| [Joint redesign · provisional](https://mckayreedmoore.github.io/mini-moonboard/?model=joint-development) | `joint-development` |
| [Independent leg plies · provisional](https://mckayreedmoore.github.io/mini-moonboard/?model=independent-leg-development) | `independent-leg-development` |
| [Revised screw spacing · provisional](https://mckayreedmoore.github.io/mini-moonboard/?model=screw-spacing-development) | `screw-spacing-development` |
| [Mid-batten clips · unselected hardware](https://mckayreedmoore.github.io/mini-moonboard/?model=mid-batten-clip-development) | `mid-batten-clip-development` |
| [Perimeter transitions · unselected hardware](https://mckayreedmoore.github.io/mini-moonboard/?model=lower-transition-development) | `lower-transition-development` |
| [Selected products · fit unqualified](https://mckayreedmoore.github.io/mini-moonboard/?model=selected-hardware-development) | `selected-hardware-development` |
| [Revised top joint · strength unqualified](https://mckayreedmoore.github.io/mini-moonboard/?model=top-joint-development) | `top-joint-development` |
| [Wood-first MVP · housed joints](https://mckayreedmoore.github.io/mini-moonboard/?model=wood-first-mvp) | `wood-first-mvp` |
| [Commercial-bracket MVP · factory connectors](https://mckayreedmoore.github.io/mini-moonboard/?model=commercial-bracket-mvp) | `commercial-bracket-mvp` |
| [Square-cut A · purchased connectors](https://mckayreedmoore.github.io/mini-moonboard/?model=square-cut-bracket) | `square-cut-bracket` |
| [Square-cut B · bolted wood blocks](https://mckayreedmoore.github.io/mini-moonboard/?model=square-cut-wood-blocks) | `square-cut-wood-blocks` |
| [Wider bolted A · purchased clips](https://mckayreedmoore.github.io/mini-moonboard/?model=bolted-clip-frame) | `bolted-clip-frame` |
| [Wider bolted B · wood blocks](https://mckayreedmoore.github.io/mini-moonboard/?model=bolted-block-frame) | `bolted-block-frame` |
| [Lean · 1½-in stock, single main layer](https://mckayreedmoore.github.io/mini-moonboard/?model=lean-38mm-frame) | `lean-38mm-frame` |
| [Lean · continuous top and bottom rails](https://mckayreedmoore.github.io/mini-moonboard/?model=continuous-lean-frame) | `continuous-lean-frame` |
| [Lean · lower bearing and ledge angles](https://mckayreedmoore.github.io/mini-moonboard/?model=bearing-lean-frame) | `bearing-lean-frame` |
| [Horizontal base · corrected grid · layout only](https://mckayreedmoore.github.io/mini-moonboard/?model=base-bearing-concept) | `base-bearing-concept` |
| [Lumber base · backing and connections](https://mckayreedmoore.github.io/mini-moonboard/?model=timber-base-development) | `timber-base-development` |
| [Lumber base · removable panel inserts](https://mckayreedmoore.github.io/mini-moonboard/?model=panel-insert-development) | `panel-insert-development` |
| [Wider central supports · backing bolt clearance](https://mckayreedmoore.github.io/mini-moonboard/?model=wide-principal-development) | `wide-principal-development` |
| [2x6 straight legs · +0 mm (0.00 in) · unqualified](https://mckayreedmoore.github.io/mini-moonboard/?model=lumber-leg-2x6-e0) | `lumber-leg-2x6-e0` |
| [2x6 straight legs · +150 mm (5.91 in) · unqualified](https://mckayreedmoore.github.io/mini-moonboard/?model=lumber-leg-2x6-e150) | `lumber-leg-2x6-e150` |
| [2x6 straight legs · +300 mm (11.81 in) · unqualified](https://mckayreedmoore.github.io/mini-moonboard/?model=lumber-leg-2x6-e300) | `lumber-leg-2x6-e300` |
| [2x8 straight legs · +0 mm (0.00 in) · unqualified](https://mckayreedmoore.github.io/mini-moonboard/?model=lumber-leg-2x8-e0) | `lumber-leg-2x8-e0` |
| [2x8 straight legs · +150 mm (5.91 in) · unqualified](https://mckayreedmoore.github.io/mini-moonboard/?model=lumber-leg-2x8-e150) | `lumber-leg-2x8-e150` |
| [2x8 straight legs · +300 mm (11.81 in) · unqualified](https://mckayreedmoore.github.io/mini-moonboard/?model=lumber-leg-2x8-e300) | `lumber-leg-2x8-e300` |
| [2x10 straight legs · +0 mm (0.00 in) · unqualified](https://mckayreedmoore.github.io/mini-moonboard/?model=lumber-leg-2x10-e0) | `lumber-leg-2x10-e0` |
| [2x10 straight legs · +150 mm (5.91 in) · unqualified](https://mckayreedmoore.github.io/mini-moonboard/?model=lumber-leg-2x10-e150) | `lumber-leg-2x10-e150` |
| [2x10 straight legs · +300 mm (11.81 in) · unqualified](https://mckayreedmoore.github.io/mini-moonboard/?model=lumber-leg-2x10-e300) | `lumber-leg-2x10-e300` |
| [2x12 straight legs · +0 mm (0.00 in) · unqualified](https://mckayreedmoore.github.io/mini-moonboard/?model=lumber-leg-2x12-e0) | `lumber-leg-2x12-e0` |
| [2x12 straight legs · +150 mm (5.91 in) · unqualified](https://mckayreedmoore.github.io/mini-moonboard/?model=lumber-leg-2x12-e150) | `lumber-leg-2x12-e150` |
| [2x12 straight legs · +300 mm (11.81 in) · unqualified](https://mckayreedmoore.github.io/mini-moonboard/?model=lumber-leg-2x12-e300) | `lumber-leg-2x12-e300` |
| [2x8 +300 mm · spread100×50 / top150 · unqualified](https://mckayreedmoore.github.io/mini-moonboard/?model=lumber-leg-spread-2x8-e300) | `lumber-leg-spread-2x8-e300` |
| [2x6 +300 mm · spread100×50 / top150 · unqualified](https://mckayreedmoore.github.io/mini-moonboard/?model=lumber-leg-spread-2x6-e300) | `lumber-leg-spread-2x6-e300` |
| [2x6 +0 mm (0 in) · long bolts / four washers · geometry only](https://mckayreedmoore.github.io/mini-moonboard/?model=lumber-leg-hardware-2x6-e0) | `lumber-leg-hardware-2x6-e0` |
| [Historical 2×6 · paired seam rails · failed baseline](https://mckayreedmoore.github.io/mini-moonboard/?model=square-2x6-development) | `square-2x6-development` |
| [Historical 2×6 · paired seam rails · revised connections](https://mckayreedmoore.github.io/mini-moonboard/?model=square-2x6-revised-development) | `square-2x6-revised-development` |
| [Single 2×6 · retained baseline · seam / bearing failures](https://mckayreedmoore.github.io/mini-moonboard/?model=single-2x6-development) | `single-2x6-development` |
| [2×6 base · selective single 3×6 / 2×10 · historical unqualified](https://mckayreedmoore.github.io/mini-moonboard/?model=selective-2x6-development) | `selective-2x6-development` |
| [2×6 paired rails · center base bracket · unqualified](https://mckayreedmoore.github.io/mini-moonboard/?model=paired-rail-base-development) | `paired-rail-base-development` |
| [2×6 vertical principals · open middle bays · unqualified](https://mckayreedmoore.github.io/mini-moonboard/?model=vertical-principal-development) | `vertical-principal-development` |
| [2×6 split center · open service corridor · unqualified](https://mckayreedmoore.github.io/mini-moonboard/?model=split-center-development) | `split-center-development` |
| [2×6 split center · panel screw infill · unqualified](https://mckayreedmoore.github.io/mini-moonboard/?model=infill-panel-development) | `infill-panel-development` |
| [2×6 split center · base angles · unqualified](https://mckayreedmoore.github.io/mini-moonboard/?model=angle-base-development) | `angle-base-development` |
| [2×6 horizontal rails · lights and wiring · unqualified](https://mckayreedmoore.github.io/mini-moonboard/?model=horizontal-service-development) | `horizontal-service-development` |
| [2×6 round passages · 12 screws per face · unqualified](https://mckayreedmoore.github.io/mini-moonboard/?model=round-bore-service-development) | `round-bore-service-development` |
| [Historical removable-panel inserts · unqualified](https://mckayreedmoore.github.io/mini-moonboard/?model=round-insert-development) | `round-insert-development` |
| [Structural screws · 1½-inch 2×6 passages · future insert space](https://mckayreedmoore.github.io/mini-moonboard/?model=round-structural-development) | `round-structural-development` |
| [Historical 2×6 with shoes · four bolts per leg · assessed / unqualified](https://mckayreedmoore.github.io/mini-moonboard/?model=round-reinforcement-development) | `round-reinforcement-development` |
| [Historical 2×8 with shoes · six bolts per leg · assessed / unqualified](https://mckayreedmoore.github.io/mini-moonboard/?model=wider-leg-development) | `wider-leg-development` |
| [2×6 legs · standard base angles · no custom shoes · unassessed](https://mckayreedmoore.github.io/mini-moonboard/?model=no-shoes-development) | `no-shoes-development` |
| [4×6 legs / rims · centered ⅝-inch pivot · development](https://mckayreedmoore.github.io/mini-moonboard/?model=thick-leg-centered-pivot-development) | `thick-leg-centered-pivot-development` |
| [Historical 4×6 compact frame · three bolts per leg · unqualified](https://mckayreedmoore.github.io/mini-moonboard/?model=compact-thick-development) | `compact-thick-development` |
| [Previous 4×6 frame · inboard spliced knees · conditional package](https://mckayreedmoore.github.io/mini-moonboard/?model=compact-spliced-knee-development) | `compact-spliced-knee-development` |
| [Bought 4×4 plywood · official Mini faces](https://mckayreedmoore.github.io/mini-moonboard/?model=compact-floor-flush-development) | `compact-floor-flush-development` |
| [Cut from 4×8 · kerf on the right](https://mckayreedmoore.github.io/mini-moonboard/?model=compact-floor-flush-kerf-right) | `compact-floor-flush-kerf-right` |
| [Historical 4×6 frame · spliced knees · flush leg tops](https://mckayreedmoore.github.io/mini-moonboard/?model=compact-spliced-flush-top-development) | `compact-spliced-flush-top-development` |
| [Previous 2×6 floor rails · conditional no-slip package](https://mckayreedmoore.github.io/mini-moonboard/?model=compact-floor-rail-development) | `compact-floor-rail-development` |
| [Previous exterior knees · conditional μ=0.4 package](https://mckayreedmoore.github.io/mini-moonboard/?model=compact-exterior-brace-development) | `compact-exterior-brace-development` |
| [2×4 floor rails · numerical response rejected · NOT ACCEPTED](https://mckayreedmoore.github.io/mini-moonboard/?model=compact-floor-rail-2x4-development) | `compact-floor-rail-2x4-development` |
| [Outboard floor rails · recessed leg ends · development / unaccepted](https://mckayreedmoore.github.io/mini-moonboard/?model=compact-floor-recess-development) | `compact-floor-recess-development` |
| [Tapered leg recess · 2×6 floor rails · development](https://mckayreedmoore.github.io/mini-moonboard/?model=compact-floor-taper-development) | `compact-floor-taper-development` |
| [DEVELOPMENT V4 · PB02/PB04 center + PB05 outer scene](https://mckayreedmoore.github.io/mini-moonboard/?model=bolted-v4-development) | `bolted-v4-development` |
| [Corner-block layout · complete concept · NOT build-ready](https://mckayreedmoore.github.io/mini-moonboard/?model=owner-corner-layout) | `owner-corner-layout` |
| [Barrel-nut layout · 24 duties · NOT build-ready](https://mckayreedmoore.github.io/mini-moonboard/?model=owner-barrel-layout) | `owner-barrel-layout` |

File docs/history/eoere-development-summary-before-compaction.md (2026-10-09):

# Historical Eoere development summary

This immutable copy preserves the complete development summary from `845e2e0c`
before the owner-authorized navigation compaction. Its “current” descriptions
and next actions belong to that checkpoint. Use the
[maintained Eoere entry](../wood-joints-mvp/README.md) for ongoing work.

Original path: `docs/wood-joints-mvp/README.md`. Original payload SHA-256:
`179f917091aeb555c5c95e99916c94fa0dbdae1356e88bfd9f5482f1a571052f`.
The original 96,499 bytes / 1,270 lines follow unchanged. Relative links in
that payload resolve from the original `docs/wood-joints-mvp/` directory.

---

# Eoere bolted-frame development

This is the active development summary for the Mini MoonBoard project's
eoere through-bolted frame and numerical completion:
`compact-floor-flush-eoere-bolted-development`. The retained `wood-joints-mvp`
folder also preserves earlier wood-joint and bracket studies. Start here for
the current engineering record. The selected screw-and-bracket baseline remains a separate
[preserved reference](../../current-candidate.json); its passes do not transfer.

## Active builder reading path

| Need | Record and revision boundary |
| --- | --- |
| Latest frame and service geometry | [Extended-cleat viewer](../../site/index.html?model=eoere-extended-cleat-frame-development&view=rear) and [geometry receipt](hypotheses/hl35-candidate/thin-frame-comparison/eoere-successor-v1/occupied-extended-cleats-v1.json): both full-thickness cleats reach the sloping side edge. The [preceding adjusted base](../../site/index.html?model=eoere-adjusted-frame-development&view=rear) and [aligned-wire model](../../site/index.html?model=eoere-bolted-aligned-wire-development&view=rear) remain available. Geometry evidence only. |
| Optional extra hold/light grid | [Extended-cleat 2026 preview](../../site/index.html?model=eoere-extended-cleat-2026-development&view=rear): **unofficial, provisional** positions. Exact midpoints are assumed for the preview; they are not fully greenlit and may differ by hold. The checkbox switches the extra holes, hardware, lights and service cuts together while retaining the extended cleats. |
| Drilling setups, fixtures and templates | [Current shop datums and drawings](hypotheses/hl35-candidate/thin-frame-comparison/eoere-successor-v1/shop-assembly-v1/extended-cleat-followup-v1/README.md) and [builder-support guide](eoere-builder-drilling-guide.md): proposed methods and unresolved tool access/tolerances. Use the current tables for moved stations; the earlier leg-corner sheets cover only their unchanged members and axes. |
| Assembly dependencies and nominal hardware | [Extended-cleat shop packet](hypotheses/hl35-candidate/thin-frame-comparison/eoere-successor-v1/shop-assembly-v1/extended-cleat-followup-v1/README.md): current profiles, hole datums, stock nesting, hardware, assembly/removal dependencies and four held cleat stations. The [raised-rail guide](eoere-shop-assembly-guide.md) remains preserved evidence. |
| Numerical findings | [Six-case receipt](hypotheses/hl35-candidate/thin-frame-comparison/eoere-successor-v1/fixed-floor-numerical-mvp-v1.json): preserved untrimmed raised-rail geometry, reference exceedances and null complete joint resistance. |
| Local strength followups | [Four bounded studies](hypotheses/hl35-candidate/thin-frame-comparison/eoere-successor-v1/bounded-strength-v1/README.md) and [component resistance followup](hypotheses/hl35-candidate/thin-frame-comparison/eoere-successor-v1/bounded-strength-v1/resistance-followup-v1/README.md): old admitted actions with preserved aligned-wire local geometry; complete joint resistance remains unresolved. |
| Documentation gaps and evidence recovery | [Completion ledger](completion-ledger.md#build-package-completion): current builder work, frozen reporting scope and separate subsequent revisions. |

## Current disposition

Owner-directed builder-support work now starts with the
[extended-cleat shop packet](hypotheses/hl35-candidate/thin-frame-comparison/eoere-successor-v1/shop-assembly-v1/extended-cleat-followup-v1/README.md)
and [drilling and fixture development guide](eoere-builder-drilling-guide.md).
The current 100-axis census has 80 single-timber and 20 two-timber shafts;
the latter include both two-bolt leg connection families. Matched-part drilling
and fixture methods are proposals with tool access and tolerances unresolved.
Keep current geometry and frozen shop/evidence packets; this work does not
assert structural qualification. The first [leg/runner/side overview](eoere-builder-drawings/leg-corner-overview.svg)
and three 190 × 260-mm printable nominal layout sheets now use the owner's
pull-saw/handheld-drill/clamp policy. Eight source hashes bind the three unchanged
members and four bolt axes. Lower timber grip is 88.9 mm; upper grip is 177.8 mm.
The current packet adds the tapered-recess definition and proposed supported
hand-tool method, 28 member/panel profiles, 120 receiver-hole occurrences,
66 screw datums, 100 bolt stacks and 200 unverified access sides. Nine drawings
and all tables pass three independent reviews. Its revised nesting fits the
same **13 sticks / 150 nominal board feet**, with at least **46.05 mm** remaining
after the recorded blanks, kerfs and end trims. Nominal mass is **219.115940 kg**,
including the retained 25-kg accessory allowance and excluding pads; actual
weight is unmeasured.

**Four dedicated cleat/post stations remain held.** Their 0.340625-mm nominal
bore/screw gap becomes **−0.05625 mm** with the maximum wood-hole scenario.
The existing Z180 bolt-move study is unadopted. Next: report and review an
affected geometry change, identify actual tool/bit envelopes, and dimension
the supported fixture and interface tolerances. No panel/screw remedy is resumed.

The separate [bolt-window followup](hypotheses/hl35-candidate/thin-frame-comparison/eoere-successor-v1/shop-assembly-v1/bolt-window-followup-v1/result.json)
screens unadopted 4¾/6½/8½-inch partially threaded Grade 5 proposals for the 24
tight catalog comparisons. Only nominal length/gage boxes clear; delivered body,
threads, coating, seating, longer-tip/tool access and strength remain unresolved.
Current bolt recipes and geometry stay unchanged.

The [four bounded strength studies](hypotheses/hl35-candidate/thin-frame-comparison/eoere-successor-v1/bounded-strength-v1/README.md)
are complete and independently reviewed. They reproduce the old six-case
actions and quantify local sensitivities to the trimmed cleats and revised
rail cuts; they do not calculate a matching revised frame response. The cleat
opening-force bound reaches 27.769 N, the nominal heel comparison retains only
0.17% margin, and four long members need justified restraint assumptions.
Washer/contact and finished-member resistance also remain incomplete. The
[ledger](completion-ledger.md#current-model-completion-scope-and-qualification-status)
records the review, source bindings and active evidence. No hardware or geometry
change follows from these studies.

The independently reviewed [component resistance followup](hypotheses/hl35-candidate/thin-frame-comparison/eoere-successor-v1/bounded-strength-v1/resistance-followup-v1/README.md)
adds finite wood-bearing and connection-shear references for the preserved
aligned-wire geometry under those same old actions. All 112 wood washer seats
have nominal geometric support; the 44 blanket service-cut landing warnings are
resolved within that revision. The highest catalog mean-bearing comparison is
0.2659; the conservative reduced-depth cleat-shear sensitivity is 0.3070.
Actual contact and complete joint resistance remain open. These results do not
evaluate the separate adjusted base or optional extra grid.

The separate [adjusted-base audit](hypotheses/hl35-candidate/thin-frame-comparison/eoere-successor-v1/bounded-strength-v1/revised-base-audit-v1/README.md)
checks the preceding v3 base with the extra grid off. All 112 wood washer seats
have nominal support: 36 changed-host queries and 76 unchanged-seat proofs.
It also records the coherent 22-shaft/ten-screw moves and the missing strength
and stiffness of four members' possible restraint paths. This does not evaluate
the subsequent cleat extension or establish new frame forces.

The [connected-stack followup](hypotheses/hl35-candidate/thin-frame-comparison/eoere-successor-v1/bounded-strength-v1/connected-stack-followup-v1/README.md)
reproduces all 48 old shaft/case combinations with 144 continuous member-bearing
trials. The largest trial wood bearing parameter is 3.990 MPa. Its comparison
with a dowel-bearing material input is not an allowable-pressure or joint-strength
check. All eight complete joint resistances remain unknown; deformation,
bolt-yield and interacting failure modes still need a compatible calculation.
These statics trials use the original admitted actions and geometry.
The [separate reproduction guide](hypotheses/hl35-candidate/thin-frame-comparison/eoere-successor-v1/bounded-strength-v1/revised-base-audit-v1/reproduction-guard-v1/README.md)
provides the guarded future entrypoints and exact verification provenance for
both followups. Three independent final reviews report no substantial findings
within those bounded scopes; the original packet bytes remain frozen.

**The latest geometry extends both full-thickness side cleats to the sloping
side-member edge.** Their bottom seats, 38.1-mm thickness, 139.7-mm front/rear
span, all bolt positions and both viewer modes' wiring stay unchanged. Maximum
nominal blank length increases from 289.7 to **361.186 mm**. Saved-solid and
mesh reviews verify the two changed bodies, all eight cleat bore/washer lands
and nominal clearance of the added volume. This changes the cleat cutting and
stock-nesting inputs; the preceding shop sheets are not current cleat templates.
The matching shop packet now supplies the revised cutting and nesting datums;
it supplies no revised forces or joint resistance. See the
[geometry receipt](hypotheses/hl35-candidate/thin-frame-comparison/eoere-successor-v1/occupied-extended-cleats-v1.json)
and [existing ledger](completion-ledger.md#extended-side-cleats).
The [live viewer](https://mckayreedmoore.github.io/mini-moonboard/?model=eoere-extended-cleat-frame-development&view=rear)
is published at `bca5f988`. Pages deployment and exact served-file checks pass;
these confirm publication of the reviewed geometry, not matching mechanical results.

**The adjusted base moves the right principal 39.2 mm left toward the seam**, viewed
from the climbing side. Three right split rails extend inward to restore their
end contacts; the right kicker post, six bracket arrangements, twenty-two
bolt stacks and ten panel/kicker center screws move coherently. Counts remain **100 bolt axes / 66 Hillman screws**.
The [base geometry receipt](hypotheses/hl35-candidate/thin-frame-comparison/eoere-successor-v1/occupied-adjusted-base-v3.json)
records restored nominal contacts, full modeled screw-body backing and zero
checked moved-bracket/hardware intersections with wood and all hardware
components with all angles. All 405 retained service bodies clear the seven
changed finished timbers; eleven retained F-column cable routes receive new
cutouts in the moved principal. Revised forces,
resistance, tolerances and operations remain unevaluated; no historical pass transfers.

The **“Show unofficial 2026 holes, T-nuts and lights”** checkbox adds **120 main-panel
T-nuts, 120 lights and 119 modeled cable links**, with 240 panel bores and their
additional service cuts. Turning it off restores the adjusted base's original
hold/light pattern and service geometry; the member/connection changes remain.
These positions are **unofficial and not fully greenlit**. Exact horizontal
midpoints are a preview assumption; actual new holds may not exist at every
midpoint. Kicker positions stay unchanged. Ten original wire links detour around
new lights only when the extra layer is enabled, and the second cable route uses
a separate modeled depth. Nominal CAD and real mesh checks report no checked
intersections; controller/strand selection, connectors, slack, actual feeding,
machining and revised strength remain unqualified. The
[extra-layer receipt](hypotheses/hl35-candidate/thin-frame-comparison/eoere-successor-v1/occupied-2026-adjustments-v3.json)
and [implementation/retention entry](completion-ledger.md#adjusted-base-and-unofficial-2026-toggle)
bind the preceding v3 geometry and tests. Its frozen bytes are committed at
`29404b05`; the extension replaces only its two cleat meshes in separate viewer
choices. Deployment observations are recorded in the ledger.

**The preserved preceding geometry aligns 30 wire passages on six rails to the original grid
columns, retaining the two already-aligned center-upright passages.** The
[aligned-wire viewer](../../site/index.html?model=eoere-bolted-aligned-wire-development&view=rear)
and [geometry receipt](hypotheses/hl35-candidate/thin-frame-comparison/eoere-successor-v1/occupied-aligned-wire-v1.json)
form the distinct `eoere-grid-aligned-wire-cutouts-v1` revision. Six raw rails
are recut rather than retaining their old channels; 30 rounded routes change.
All 132 LED endpoints, 131 links, the two connector-bearing links, 100 bolt
positions and 66 screw axes remain unchanged. Saved CAD rail/route geometry,
nominal interference, bore and screw backing, mesh and browser checks pass.
The passages have a 20.427677-mm nominal front width and 14.35-mm rear depth;
the cable center remains at N8 with the recorded 8-mm fillets. These are CAD
envelopes, not routing-tool, delivered harness or installation instructions.
The two upright links follow their LED rows, which differ from the corresponding
T-nut rows. The center principal stays in its existing position.
The earlier owner-requested [midpoint relocation screen](completion-ledger.md#right-principal-midpoint-relocation-screen)
identified the **39.2 mm leftward shift** as an unadopted investigation pose.
The adjusted base above now incorporates its coordinated geometry changes;
the preceding published model and its frozen evidence remain unchanged.
That preceding geometry is published at `78685125`; deployment and served-file
verification pass, as recorded in the existing ledger.

The preceding geometry step trims both exterior 2×6 cleats to the sloping sides'
rear edges, with full 38.1-mm thickness and all bolt positions retained.
The [trimmed-cleat viewer](../../site/index.html?model=eoere-bolted-trimmed-cleats-development&view=rear)
and [geometry receipt](hypotheses/hl35-candidate/thin-frame-comparison/eoere-successor-v1/occupied-cleat-trim-v1.json)
form a distinct `eoere-rear-trimmed-cleats-v1` revision. Saved CAD,
independent output review, genuine mesh checks and front/rear browser navigation
pass their geometric/display checks. Only two cleat solids change; 26 other
wood/panel bodies, all 100 bolt axes and all 66 screw axes remain unchanged.
The nearest upper bore edge is 23.948653 mm from the cut and the washer outer
edge is 16.027028 mm away, measured perpendicular to the cut. These are nominal
containment distances, not joint-strength references. The existing lower
bore/kicker-screw gap remains 0.340625 mm. No angle or bolt relocation is adopted.
The later wire revision retains these two cleats byte-for-byte. Its source
bindings, independent review, limits and recovery are in the
[existing ledger](completion-ledger.md#build-package-completion).

**The preserved untrimmed raised-rail numerical MVP and nominal shop/assembly
packet are published at `2cab2be5`.** Their source bytes, results, cut profiles
and reviews stay frozen; their six-case calculations do not evaluate the new
cleat geometry. The completed reporting scope retains exceedances and unknown
resistance. The owner-directed scope was to finish and publish that packet. The
six-case evaluation is complete. Its frozen evidence retains
exceedances and unknown resistance; panel/screw remedies are stopped and
backer/cross-support proposals remain unadopted studies. The completed packet
records hardware/receiving guidance, 100-bolt/200-side access dispositions,
cut/hole datums and missing tolerances, assembly/removal order and BOM/cost/mass limits.
Physical testing and engineer approval are outside this completion scope.
Actual observations stay blank. Coherent reviewed reporting completes this
scope; full physical resistance qualification is not its completion criterion.
The earlier complete-build strength-pass objective is superseded. See the
[active sequence](completion-ledger.md#build-package-completion).
The [nominal shop/assembly packet](eoere-shop-assembly-guide.md) is now complete
within that reporting scope. Its raised-rail cut/hole and 100-stack/200-side tables,
receiving guidance, dependency order and cost/mass limits pass independent
review. Tool paths, delivered parts, missing tolerances and complete joint
resistance remain explicit unresolved inputs. Both heel scenarios and their
reviews stay frozen; active retention and verified external recovery are in
the [existing ledger](completion-ledger.md#build-package-completion).
**The raised-rail conditional numerical MVP is now complete for all six
original loaded cases.** Its [compact six-case receipt](hypotheses/hl35-candidate/thin-frame-comparison/eoere-successor-v1/fixed-floor-numerical-mvp-v1.json)
binds the fresh fields, independent floor/component reviews and final joint
review. Exceedances remain recorded and every complete joint resistance
remains null. The evaluated geometry and 66-screw policy stay frozen separately
from the subsequent trim.

Use eoere B0C7V7VS89 angles with the far transverse pair on each
flange: four 3/8-inch through bolts per angle. Sixteen main angles sit inside
the four panel boxes. The owner's later clarification makes the lower corner
purpose clear: matching upper/lower holes. A 2×6 block is 12.7 mm thinner
than the required 50.8-mm offset. Following the owner's suggestion to forgo
the lower bracket, the current layout uses two exterior 2×6 cleats above the
runners and retains the upper inside angles. Two lower outside angles become
cleat connections: **22 angles plus two cleats** account for the 24 starting
duties. Two additional 3/8-inch bolts attach each cleat to its outer post;
the retained angle's side bolts also cross the cleat. Current-case component
dispositions cover both corners; complete physical resistance remains
unqualified. Preserve the climbing surface, panel
outlines and 66 Hillman screws, and recheck the twelve starting frame bolts
and every changed receiver. See the [active sequence](completion-ledger.md#build-package-completion).

Previous geometry helpers, material methods, panel coordinates and assembly
methods are reused within their limits. The B103/B104 geometry, forces,
takeoff and viewer below remain preserved predecessor evidence; their passes
do not transfer. No unexecuted predecessor contact preparation, profile or
response is being run. The nominal four-port fitting layout has its own
reviewed geometry and six-case mechanics. Published hole pitches are available; absolute heel
offsets, bend geometry, tolerances and actual steel resistance remain missing.
Reference exceedances stay recorded; actual product qualification remains unresolved. A
failed criterion, missing load path or incompatible part still governs the
affected operation; conditional comparisons do not release physical work.
The completed numerical MVP supplies a coherent review layout, six bounded
admitted fields, joint/component findings and practical cost, hardware and
assembly implications. The current scope completes the existing model's
joint/component findings and applicable hardware inputs. Modeling errors,
incompatible source joins and missing actions still require correction;
reference exceedances are retained outcomes. Candidate-specific evidence and
practical implications follow the existing raised-rail model without panel redesign.
The selected baseline and frozen earlier eoere packet remain unchanged.
Candidate selection and physical work remain separate.

Preserved panel-remedy screens rule out moving perimeter screws alone as a
complete panel remedy. The best screened cluster brings the generic head
comparison to 1.036619, while bending and rolling shear remain above their
references. The first connected rear-support screen also fails: its head
comparison rises to 2.884227 and the spatial checks remain above their
references. That backer is not adopted. A same-wrench flange-envelope
diagnostic leaves the spatial and head comparisons effectively unchanged.
The subsequent cross-support proposal and pending screening preparation are
stopped under the owner's latest scope; no support or screw change is adopted.
Independent geometry review supports a separate four-cleat-bolt
Z180 proposal, with 3.94375 mm clearance at the larger bore sensitivity;
the Z200 bore locations remain unchanged. The preceding model direction
raises only the two bottom rails above the first T-nut row, retaining the
existing wire cutouts and routes. The completed nominal rebuild uses a
30.625-mm rise along the board, giving 6.35 mm above the service envelope.
Four dependent Hillman axes and sixteen bottom-angle stacks move; all checked
intersections are empty and the screw/bore bodies retain full modeled backing.
Its [separate viewer](../../site/index.html?model=eoere-bolted-bottom-rail-development&view=rear)
passes the actual scene, front/rear browser and connection-inspection checks.
The old A12 field remains bound to the preserved earlier geometry.
See the [active evidence and revision sequence](completion-ledger.md#build-package-completion).

The preserved raised-rail metadata inventory gives **218.912854 kg**, including the
25-kg allowance and excluding pads. This is not a reconciled mass inventory for
the later trimmed-cleat/aligned-wire geometry. All 100 hardware recipes remain unchanged;
the recorded complete bolt/nut/washer purchase comparison is **$109.93**,
plus six four-pack angle prices and unpriced wood and other items. Catalog
tolerance corners leave 24 short stack comparisons; the existing per-stack
receiving windows remain applicable, with actual observations blank.

The same source-bound inventory gives this nominal bolt count. These are
model recipes and catalog comparisons; delivered fit remains unresolved.

| Nominal bolt diameter × length | Quantity |
| --- | ---: |
| 3/8 × 2½ inch | 60 |
| 3/8 × 3 inch | 4 |
| 3/8 × 4 inch | 8 |
| 3/8 × 4½ inch | 20 |
| 3/8 × 6 inch | 4 |
| 1/2 × 8 inch | 4 |
| Total physical bolts | **100** |

The inventory records 100 nuts, 200 washers and six four-packs of angles:
22 installed and two spare. Each delivered stack must satisfy
`L >= S + w_head + w_nut + h_nut + 2*pitch`, where S is the receiver-plus-plate
stack. Full nut seating, smooth-shank reach, thread/runout and washer support
remain separate checks; this length equation supplies no tool or removal pass.

The [preserved raised-rail shop and assembly guide](eoere-shop-assembly-guide.md) organizes
that revision's 22 timbers, 22 angles, two cleats and 100 shafts, including the
four moved lower screws and sixteen moved stacks. Each of the 200 head/nut
sides has an explicit nominal disposition; actual tool and continuous-removal
paths remain unverified. The preserved construction tables cover 20 timbers,
70 shafts and 36 fittings, and their old 140 tool-side passes do not transfer.
The thirteen-stick, 150-board-foot stock scenario nominally fits both
289.7-mm cleats in runner offcuts; its tightest earlier nesting margin is
2.649 mm. Actual stock, panel dimensions, factory datums, tool outlines and
assembly/removal corridors remain unobserved or unverified. These practical
gaps are recorded in the [existing completion sequence](completion-ledger.md#build-package-completion).

The joint source review also identifies a modeling correction: all 88 elastic
half-strip neutral datums lie on the backing plane, omitting the nominal
3.175-mm steel centroid offset. Actual contact/seat point maps and centroid
gravity already retain their eccentricity. The distinct corrected operator
passes its independent first-order method review, and the fresh raised-rail
A12-rear field passes the independent original-law check for all 150 bodies.
The old field is preserved.
The corrected gross strip/heel analogy still does not qualify the physical
formed heel or complete fitting strength.

The preserved original-law raised-rail A12-rear comparisons are **2.559349** for the generic screw-head
reference, **4.591412 / 2.437017** for panel bending / rolling shear, and
**0.486363 / 0.858186** for sampled gross-member normal / shear-torsion.
All 24 joint duties and twelve starting frame bolts have current-case
component dispositions. Full joint resistance remains unqualified. The forward
case exhausted 64 distinct support patterns, each with a converged fixed branch
but incompatible whole-foot activation. The owner-directed serial stop preserved
the sideways case after 18 completed conflicting patterns and an interrupted
nineteenth. The other three cases were not started. No actions from those failed
or interrupted searches are admitted; the bounded search does not prove that
every possible pattern is incompatible.

The completed packet uses the owner's distinct simpler analytical floor scenario: retain
all **32 compression-only normal contacts** and credit horizontal restraint
only at the two rear-leg centroids. The other six feet are normal-only; both
credited legs must have positive normal bearing in every admitted case.
Geometry, loads and internal joint laws remain unchanged. Source-only global
statics finds a feasible nonnegative vertical reaction distribution in all six
loaded cases and the separate gravity diagnostic; the minimum support-polygon
edge margin is **329.975 mm**. This does not establish compatible elastic
reactions or physical sliding resistance. The corrected runner and admission
gate pass independent method review. All six fresh fields pass the unchanged
**1e-5 N** full-coordinate residual threshold, all 150-body/global closures,
source identities and own force recovery. Maximum residual is
**9.939765e-6 N**; minimum credited rear-leg bearing is **592.856590 N**.
The largest individual leg horizontal/normal demand is **0.324737**; it is
a reaction diagnostic, not measured friction or a sliding rating. All twelve
disabled XY forces and energies are exactly zero in every case. No old-law
field or receipt fills this roster. No-slip remains unverified.
See the [current case evidence](completion-ledger.md#build-package-completion).

| Six-case governing conditional comparison | Result | Scope |
| --- | ---: | --- |
| Generic Hillman head, CD1 | **2.571946**, A12-rear | Own screw actions are 1492.481 N withdrawal and 706.895 N lateral. Required generic effective thread is 62.953 mm versus 45.244 mm nominal length after the panel; actual product resistance/engagement is unknown. |
| Spatial panel bending / rolling shear, CD1 | **4.613058 / 2.451408**, A12-rear / A12-forward | Exceedances are retained. Local holes, head seats, punching and edge-transfer resistance remain unqualified. |
| Sampled gross-member normal / shear-torsion, CD1 | **0.526047 / 0.977592**, K12-rear / K12-right | Assumed bracing and intact rectangular cuts; actual restraint, net cuts and fracture remain unresolved. Four weak-column domains remain unqualified. |
| Unadjusted timber bolt-component reference | **0.699104**, A12-rear | Separate Cdelta=0.5/Cg=1 sensitivity reaches **1.398208**; actual factors, group/splitting and complete joint resistance are unknown. |
| Straight-steel / original representative t6/Ri6-mm heel reference | **0.850480 / 1.113498**, A12-left | Seven original heel-scenario rows exceed across three cases. Actual formed heel, continuity and complete fitting resistance remain unqualified. |
| Owner-requested t6.35/Ri6.35-mm heel reference scenario | **0.998300**, A12-left | 140.479342 MPa against 140.718563 MPa; zero of 528 screen rows exceed, only **0.170000%** below the reference. Catalog thickness is the working nominal; inside radius equal to thickness is assumed. |
| Specified smooth/catalog-minimum-body shaft first-yield marker | **0.514158**, A12-forward | Grade 5 reference and declared body/root regions; delivered shank, threads, fillet and complete bolt resistance remain unqualified. |
| Axial-only catalog washer required Fy | **156.175807 MPa**, K12-right | Actual washer Fy, pressure couples, peak pressure and combined washer strength remain unknown. |

Each case records all **24 joint duties and twelve starting frame bolts**.
The independent reviews verify saved case joins and scoped calculations;
the joint review does not independently qualify every formula or physical
failure mode. First-order interaction-point motion markers reach
**53.573 mm**, and relative rotation reaches **0.107818 rad**. They include
assembly motion and do not establish physical movement or finite-contact
applicability. Reference exceedances and null resistance do not trigger further
panel-remedy work under the owner's numerical scope.

The separate [heel assumption study](hypotheses/hl35-candidate/thin-frame-comparison/eoere-successor-v1/heel-assumptions-v1/README.md)
replays all 528 original comparisons exactly and verifies 647 source pins.
Its unchanged-action t6.35/Ri6 and t6.35/Ri8 sensitivities are 1.008988 and
0.959419. The [owner-requested nominal supplement](hypotheses/hl35-candidate/thin-frame-comparison/eoere-successor-v1/heel-assumptions-v1/nominal-scenario.md)
verifies 650 pins and records t6.35/Ri6.35 separately; it does not replace
the closed results or change geometry, actions, stiffness or material
acceptance. Radius near thickness is a manufacturing inference, not a product
measurement. Minimum thickness, inside/outside radius, thinning and heel/hole
datums remain useful receiving inputs; complete 3D heel and joint resistance
remain unqualified. The earlier proposed component test is unperformed and
outside the current scope.

The compact receipt stays in the working documentation. Full case fields,
operators, methods, reviews and failed revisions remain active ignored evidence
with verified external recovery recorded in the existing ledger. Nothing is
pruned; selected-baseline and historical viewer/evidence bytes stay unchanged.

## Preserved earlier eoere A12 packet

The preserved [eoere cleat-corner A12 model](../../site/index.html?model=eoere-bolted-development&view=rear)
remains published under its separate [development contract](../../eoere-bolted-candidate.json).
The [complete occupied-geometry result](hypotheses/hl35-candidate/thin-frame-comparison/eoere-successor-v1/occupied-geometry-v2.json)
has **22 angles, two added cleats and 100 physical bolt stacks**. All five
intersection lists are empty. All 120 receiver bore bodies and 132 screw
penetration checks, covering CAT 23/32 and nominal 3/4-inch plywood, retain
full modeled backing. All 66 Hillman axes and existing stock sections stay
unchanged in that frozen revision. The four new cleat/post bolts are at Z200 mm; their minimum nominal
bore/screw gap is only **0.340625 mm**. The short post's 38.9-mm top end
retains the named compression reference, but complete tension geometry and
delivered tolerances remain unresolved. The failed first layout is preserved.

Genuine Three.js checks verify 1,021 parts, all 176 factory holes and 100
complete stacks; 477 unchanged panel, screw and service parts are shared.
Front/rear browser checks and bolt inspection pass without page errors or
failed requests. These are nominal geometry and display checks. Washer seats,
tools, removal, actual hardware and complete joint resistance remain open.

The independently checked [inventory](hypotheses/hl35-candidate/thin-frame-comparison/eoere-successor-v1/inventory-v2.json)
gives a conditional **218.90 kg** planning total, including the existing
25-kg accessory allowance and excluding pads. Both cleats nominally fit
runner offcuts. The current partial cost is **six four-pack prices, plus
$61.93 and unpriced items**. The angle price, 68 new bolts, 24 legacy washers,
wood and other receipts remain unpriced. Nominal SKU matches do not establish
delivered fit. Four 8-inch bolt comparisons still require a delivered-length
check. Fresh extraction now binds 150 physical owners, 120 receiver-bearing
records and 1,631 hole-clipped reference contact points. Its source inputs
pass independent review. The new A12 calculation converges after three
support patterns and now passes independent admission for all **150 bodies**.
The same-byte component review also passes. Both gate compatibility failures
are preserved; corrected flag, ownership and source-order checks reuse the
unchanged field and physical laws. The scope retains **250 lb ×2, 300 N
horizontal and a 100-mm hold arm**, with complete modeled gravity and an
unverified no-slip floor assumption. The prior response does not transfer.

| Preserved earlier eoere conditional A12 finding | Result | Limit |
| --- | ---: | --- |
| 66 Hillman axes, generic head comparison | **2.563273**, two exceeding axes | Governing upper-left screw has **1487.448 N** withdrawal and simultaneous **644.659 N** lateral. Actual Hillman resistance is unavailable. |
| Generic withdrawal, CD1 | **62.741 mm** required effective thread | Nominal length after the panel is **45.244 mm**; delivered thread engagement is unknown. |
| Six-panel spatial bending / rolling shear, CD1 | **4.595869 / 2.438902** | Both govern on the upper-left panel; sampled fields do not qualify local holes, head seats or punching. |
| 22 gross-member fully braced normal / sufficient shear-torsion witnesses, CD1 | **0.486487 / 0.856880** | Net cuts, actual restraint, fracture and continuous maxima remain unresolved. Four full-length weak-column sensitivity domains are exceeded; actual bracing is unqualified. |
| 88 nominal gross fitting half-strips | **93.809 MPa** peak stress envelope | Upper-left fitting root; actual steel strength, holes, formed heel, plate continuity and prying remain unqualified. |
| 100 nominal shaft circles | **218.134 MPa** for 3/8 inch; **162.442 MPa** for 1/2 inch | Own same-cut markers; actual grade, roots, threads and complete bolt/joint resistance remain unavailable. |
| 200 washer capture diagnostics | **0.886903 MPa** peak full-annulus mean | This does not evaluate pressure couples, peak pressure, washer bending or seat resistance. |

The complete **22-angle plus two-cleat** resistance remains **UNQUALIFIED**.
The cleat/post force components permit reduced end-distance markers, but all
sixteen selected own-member resultants are oblique; no complete Cdelta or
group resistance is adopted. Both rim resultants act away from their short
edge in this case, so the bare 4D comparison is not a current signed failure.
The nominal 10-mm steel holes are below the pinned NDS general bolt-hole
oversize range for 3/8-inch bolts; installation applicability remains open.

Preserved first-order motion diagnostics reach **28.273 mm** at an owned
interaction point and **0.071714 rad** relative timber/fitting-strip rotation.
They include assembly motion and are not physical movement predictions.
No physical demand bound, complete joint acceptance or fabrication release
follows. The [compact numerical receipt](../../fea/generated/thin-bolted-current-contact-v1/eoere-successor-v1/a12-first-order-v2/assessment.json)
contains every duty and the governing component findings. Its reproduction and
recovery record is in the [existing ledger](completion-ledger.md#build-package-completion).
The development contract and raw field retain their creation-time planned or
pending flags; the subsequent receipts establish conditional numerical closure.
Panel load transfer, lower-hole clearance, actual hardware/material datums,
changed net sections and contact/stability applicability remain the next
design and qualification questions. No structural stock increase is proposed.

## Preserved thin B103/B104 predecessor

The [construction coordinates and takeoff](hypotheses/hl35-candidate/thin-frame-comparison/access-takeoff-v4.md)
now include fifteen independently checked tables: twenty timber datums and
profiles, seventy physical bolt stacks, thirty-six fittings, sixty-six Hillman
stations and 140 washer sides. The nominal packet retains blank actual
measurements. Updated known partial hardware is **$314.17**; conditional dead
mass remains **216.75–218.27 kg**. Four nominal 8-inch bolts require a delivered
length check; current panel dimensions also need reconciliation with the
already cut panels. No purchase or physical work is released by these tables.

New same-state timber comparisons give **0.667979** for fully braced normal
interaction and **0.701151** for a sufficient shear/torsion bound on 226
intact rectangular cuts. These do not clear net cuts, cut effects or actual
bracing. An independently checked fixed-load allocation can reduce the
upper-left panel's necessary peak screw tension to **299.883 N**, against
the **580.292-N** generic head reference. It proves possible static sharing,
without producing compatible forces or changing the current **1939.743-N**
peak. Exact saved-face classification finds thirteen old master footprints
outside occupied wood, ten with a conditional **736.146-N** compression
census. Current overlap and edge behavior therefore remain active mechanics
work. The finite eight-centroid floor and closest-normal contact methods
pass their bounded known-answer checks; a fresh candidate response has not
been admitted from those method results.

**The compact conditional A12 joint assessment is complete.** The
[current numerical receipt](../../fea/generated/thin-bolted-direct-contact-a12-v1/observer-isolation-v2/assessment.json)
covers all twenty-four duties in the reviewed B103/B104 layout, including
single, paired and shared-shaft families. The corrected current-common-shaft
field, component reductions and motion diagnostics are independently reviewed.
Complete joint resistance and physical contact applicability remain
**UNQUALIFIED**; the current actions are not established physical demand
bounds. This closes the bounded conditional assessment, with exceedances and
missing inputs recorded. Broader candidate acceptance remains open.

**The owner now requests a thinner frame closer to the earlier screw-and-angle
layout, while retaining through-bolted structural joints.** The comparison
basis is the selected frame's solid 4×6 legs/rims, single 2×6 receiving members
and split center. The enlarged HL35 stock proposal is preserved research;
no thinner successor has been selected. The conditional mixed-fitting layout
now has an [integrated review model](../../site/index.html?model=thin-bolted-development),
bound by its separate [development contract](../../thin-bolted-candidate.json).
Use the [earlier kerf-right frame](../../site/index.html?model=compact-floor-flush-kerf-right)
as a geometry reference; its ML24Z/SDS attachments are not a bolted proposal.
A single 2×6 does not meet the HL35 catalog's minimum 3½-inch wood thickness
for table loads. Other through-bolt details need their own wood, steel,
hole-placement and complete-joint checks. The mixed B104/B103 fitting proposal
below was the thinner-frame development model before the eoere scope change. See the
[recorded direction](../../hl35-candidate.json).

The owner has started a **lean numerical MVP goal, with joint validation first
and a separate floor-contact worker**, and later authorized further bounded
cycles, online research and reuse. The reviewed geometry, access/takeoff,
material references and passing method checks remain the starting point. The
failed response model has seventy common shafts, six timber compression
interfaces and centroid no-slip floor springs with whole-foot release. A new
cached-solid audit proves **30** positive-area timber interfaces: the six
retained interfaces plus **24 omitted end/rail bearing paths**. The complete
contact extension retains the declared normal bedding. Its first bounded A12
case stops at export because the floor monitor sorts eight sparse rows in
place while reading them. A separately reviewed copied-row observer adapter
preserves the original operators in a distinct, same-physics execution.
That current field now passes the complete independent gate: **5.38e-7 N**
generalized residual, all **132 bodies**, global equilibrium and the unchanged
same-q floor activation law. The largest body residual is **7.84e-7 N /
0.000938 N·mm**. The reviewed geometry remains unchanged. Current component
and motion reductions use those exact admitted bytes. Component exceedances and unqualified
capacities are useful findings; neither is structural acceptance. The previous
broader goal and interrupted six-hour finite attempt remain historical evidence.

The current A12 comparisons below use the retained **250 lb ×2 / 300 N /
100 mm arm** envelope. Ratios compare demand with the named conditional
reference; steel yield and wood allowable-strength bases differ.

| Current conditional check | Result | Disposition |
| --- | ---: | --- |
| B104 / B103 sampled nominal flange yield | **0.797272 / 0.008422** | Includes the original operator's own fitting gravity interpolation. Physical leg-weight distribution, hole/heel effects and actual product resistance remain unqualified. |
| Same-cut flange torsion scenarios | Gross **0.801668**; two-ligament proxy **0.848322** | Includes the same gravity interpolation. Conditional ideal-section references; restrained warping, prying and the actual formed heel remain unresolved. |
| Seventy shaft same-cut circular yield scenarios | Half-inch maximum **0.265473**; three-eighth-inch **0.0448845** | Assumed Grade 5, each shaft's own nominal diameter: 62 half-inch and eight three-eighth-inch circles. Actual root/thread placement and complete bolt/joint resistance remain unqualified. |
| Sixty-six panel/kicker screw axes | Generic head index **3.342699**, two exceeding axes | Governing upper-left screw: **1939.743 N** withdrawal and simultaneous **669.664 N** lateral. Actual Hillman resistance remains unavailable. |
| Generic withdrawal comparison | Required effective thread **81.819 mm** at CD1 | Nominal screw length after the panel is **45.244 mm**; effective threaded engagement remains unmeasured. Conditional CD1.6 still requires 51.137 mm. |
| Six-panel spatial section diagnostics | Bending **5.501986**; rolling shear **2.777902** at CD1 | Sampled spline resultants retain local-hole, head-seat and derivative-jump limits. Mean net-cut indices **0.621706 / 0.270134** do not clear those spatial findings. |
| Own wood-side washer captures | Ideal full-annulus index **0.362247** | Own axis-019 nut/header force is **1256.060 N**. Actual pressure, prying moments, washer bending and seating remain unresolved; no duration increase is applied. |
| Twenty timber axial-average diagnostics | Tension **0.028431**; compression **0.049667** at CD1 | These averages omit bending/shear/fracture/stability acceptance. Four terminal planes are outside the reference-span cut replay. |
| Fourteen shared shafts / complete joints | **Resistance unavailable** | Unequal shared-shaft actions cannot use summed single-shear ratings. All twenty-four angle duties remain unqualified as complete joints. |

The admitted coordinate replay gives **27.507 mm** maximum timber-face
tangential motion and **0.230788 rad** maximum relative rotation among the
representative fitting/receiver markers. The base-left B104's internal
two-flange marker is **0.024070 rad**; it does not recover heel curvature.
Updating point arms and normals at the fixed q changes the contact-side
markers of eleven loaded timber cells and thirteen loaded representative
flange points to opening. This leaves current contact overlap and first-order
physical applicability **UNQUALIFIED**. The replay supplies diagnostic geometry,
without a new equilibrated force field or physical movement prediction.
Bracket body-weight bookkeeping now matches all thirty-six fittings' original
applied-vector entries exactly. All **802 scoped net-section normal bounds**
are now below the conditional CD1 fully braced reference, maximum **0.940811**.
The refinement reused five exact sections, preserved 751 sufficient bounds
and measured only the 46 inconclusive sections on five cached timbers; those
46 refined comparisons peak at **0.605572**. The original loose 9.804 bound
remains preserved. All **18 partial-end normal comparisons** are also below
the same conditional reference, maximum **0.620943**. One additional exact
section replaces the loose 2.205688 bound with **0.0150304** while preserving
the other seventeen findings. These results reuse the admitted field; local stress
concentrations, contact-loaded tips, shear, torsion, fracture and
actual restraint remain separate. Complete timber resistance is unresolved.
The necessary combined shear/torque check on 52 already measured sections
peaks at **0.256048**; a lower bound below the reference establishes no shear
pass. All twenty saved timber maps meet the computed sufficient injectivity
criterion on their source-bound boxes, maximum L **0.318528**. This supports
inverse-map development without qualifying contact or a fresh response.
The twenty finished timber solids also pass the closed-topology census;
ten bottom-rail torus faces retain unsupported ordinary distance jets. A
distinct grouped rule reduces the reference bedding from 10,502 to 1,504
points while conserving area and first moments. All 644 new centroids now pass
their own native face and inward-occupancy checks, with an independent saved
result review. Candidate response remains pending. The sparse inverse-map bedding
method passes its independent work/gradient/tangent checks; those synthetic
results do not supply candidate forces.
The corrected panel pose diagnostic finds **496 geometrically interior,
eight exterior and twenty-six unresolved** backing stations. Only **479**
have certified opposed smooth projections. Three exterior stations retain
**69.967 N** of old compression; five unresolved locations retain **27.011 N**.
Another interior station retains **70.444 N** but misses the unchanged
stationarity tolerance. These are applicability findings at the saved pose;
the spring forces are preserved. The next engineering decision is how to revise
panel load transfer and establish current contact and washer behavior before
using these model actions as complete-joint strength demands. Exact fitting
geometry/material, bolt root/shank/thread placement, washer seating and
unequal shared-shaft/group resistance remain required inputs. The reviewed
geometry has not changed. The ledger records the
[conditional closure and verified evidence recovery](completion-ledger.md#compact-current-a12-assessment-and-recovery).

**The six-interface model's unchanged-law support search is closed.** Four authenticated failed
fields contain **256 unique ended masks / 241 resolved**. Reviewed normal-force
statics separately excludes 113 masks, including twelve of the fifteen
unresolved. Three fresh cold-start diagnostics resolve the other three, but
all conflict with their prescribed activation. All 143 statically undecided
masks now have an observed resolved activation conflict. Independent production
review passes for that six-interface model. These results close the
coverage and inherited-initialization questions within the recorded numerical
checks. They do not prove exact nonexistence or physical frame instability.
The cold diagnostics have **160–188 mm** reference node translations,
**0.477–0.554 rad** rotations and **51–59 mm** relative timber-face tangential
motion. Those are unaccepted linear coordinates, not physical movement
predictions. Source geometry, tolerances and failed evidence remain unchanged.

The small contact-law counterexample now proves that original-reference
activation can lack a fixed point even when both fixed branches are strictly
convex. A separate proposed recontact-reference convention passes prescribed
history checks; it remains a changed, unadopted scenario requiring its own
admission. The saved-coordinate joint review confirms genuine relative motion:
the base-left B104/receiver marker reaches **0.747 rad**, while its internal
beam/post heel marker is **0.0142 rad**. Replaying finite point geometry changes
contact sides; current trimmed-face overlap remains unestablished. The
first-order actions cannot be cleared by residual convergence alone. These
are diagnostic pose checks, not predicted physical rotations.

The unequal three-member shaft response/recovery seam now matches an
independent hand solution, including own member couples and shaft cuts.
It establishes elastic-method readiness, without an asymmetric ASD resistance.
The completed eccentric-annulus contact fixture now supplies verified own
contact force and moment recovery. Its immutable native outputs replay exactly;
whole-model residuals are **7.27e-7 N / 0.000715 N·mm**. This method pass does
not qualify washer bending or a candidate joint. Local hardware, material
frames and remote cut/neighbor inputs are now prepared. State-consistent
response of the B104 holes, sharp modeled heel, timber backing and own washer
sectors remains open. Product heel stresses need the actual bend geometry.
No further identical mask sweep, threshold
relaxation or floor rebuild is justified by a coverage gap. Parent-owned
freezes, serialized heavy execution and final review remain required. Commands,
frozen failures and exact missing inputs are in the existing
[ledger](completion-ledger.md#compact-bracket-and-joint-mvp).

The independently reviewed contact atlas covers all **190 pairs of twenty
cached timbers**, reuses nine proved pairs and queries the remaining candidates.
Its thirty positive interfaces supply **584 occupied reference cells**. This
resolves a specific omitted compression path, without proving current overlap
or contact pressure. The added faces include end-grain, cross-grain and 40°
bearing; the previous six faces' strength classification does not transfer.
The complete adapter, independent admission and minimal component bridge pass
97 focused checks. The observer fix passes 34 additional focused checks and
the real solve/recovery/export seam. The corrected field has distinct source,
state, gradient, floor and body admission. All 1,570 saved pre-response operator
arrays match the first attempt exactly; no floor-law or tolerance change was
used to obtain that result. The reviewed frame dimensions remain unchanged.

The revised nominal occupied layout clears the enumerated interference and
support checks. The review model is exported and its file-backed viewer loader
is validated. The
[access/takeoff packet](hypotheses/hl35-candidate/thin-frame-comparison/access-takeoff-v4.md)
now records conditional initial removal paths for all six panels, seventy bolt
stacks, thirty-six fittings and twenty individual timber members. Complete-joint
mechanics remain incomplete. The catalog drawings now visually corroborate
the nominal outside-corner leg lengths and general hole-offset construction;
Eaton's SKU discrepancies, bend radii and tolerances remain unresolved.
The [goal and sequence](completion-ledger.md#hl35-replacement-candidate)
record scope, source limits and remaining work. The owner has viewed the latest
model and requested GPT-6.1 Sol agents at xhigh to work in parallel with the
parent toward numerical MVP completion. The joint-first sequence uses parallel
joint-method, timber, floor-contact and independent-review workers; existing
steel/hardware, panel and access/takeoff results remain reusable.
The parent owns shared frozen inputs, serialized heavy execution and final
integration. This review permits candidate-specific analysis; it does not
select the candidate or establish a physical release.

The owner's latest direction keeps **joint mechanics first** and reuses the
bulk of floor work. The eight finished footprints, thirty-two normal ports,
centroid restraint operators and existing audits remain applicable. The old
and current A12 applied floor wrenches match to rounding; individual-foot
reactions do not transfer to the changed joint model. No floor rebuild or
corner refinement is required for joint method and resistance work. Existing
bolt-yield curves, fitting/washer coefficients, exact timber sections and
contact/force-recovery fixtures provide the joint starting point. They still
need their recorded material/applicability conditions before a strength
disposition. The admitted current field now supplies fresh demands. Its
joint motions are being checked separately from the earlier failed iterate's
large-motion diagnostics. Reuse the pure component calculations through the
new linear-face gate on the same immutable field bytes. The older common-shaft wrappers do
not authenticate this added face law, and the older panel/finite wrappers
require their different field contracts. The detailed reuse mapping and
current gaps are in the existing ledger.

The earlier independently gated, 62-body A12-rear spring model supplies these
usable comparisons. They retain its original state and stiffness assumptions;
none is a demand bound or an acceptance result for the changed 132-body
common-shaft model. Ratios below are component demand divided by the stated
reference, with 1.0 as the comparison threshold. Steel first-yield and timber
allowable-strength references use different bases; these ratios are not a
common joint safety factor.

| Existing conditional joint evidence | Result | Meaning and remaining gap |
| --- | ---: | --- |
| B104 nominal sampled flange steel, 48 ports | **0.538894**, 122.613 MPa at assumed Fy=227.527 MPa | Below the nominal yield reference; actual heel/hole effects, restrained warping, prying and product conformance are not qualified. |
| B103 nominal sampled flange steel, 24 ports | **0.005347**, 1.217 MPa at the same Fy | Small in this old force allocation; this is not the paired joint's reserve or a strut load rating. |
| New B104 same-cut torsion references | Gross **0.553946**; two-ligament proxy **0.871991** | Reuses all saved signed cuts; actual heel, hole concentrations and restrained warping remain unqualified. |
| New B103 same-cut torsion references | Gross **0.004585**; two-ligament proxy **0.005636** | Same old force scope and explicit ideal-section limits. |
| Isolated wood/steel bolt component, 44 shafts | **0.251391** at CD1; **0.309218** for explicit 0.8D sensitivity | Conditional bolt/wood/material/thread assumptions and edge/group/splitting resistance remain. |
| Retained wood/wood bolt component, 12 shafts | **1.018150** at CD1; **1.286932** for 0.8D sensitivity | Above these unadjusted references; conditional CD1.6 gives 0.636343 / 0.804333, without adopting that duration factor. |
| Shared shafts and complete joints | **Resistance unavailable** | Fourteen unequal shared shafts cannot use summed single-shear ratings. Own shaft/washer actions and complete joint behavior still need evidence. |

The [compact joint evidence and next checks](completion-ledger.md#compact-bracket-and-joint-mvp)
record representative single, paired and shared-shaft duties, reusable unit
coefficients, provenance and exact missing inputs. Nominal bracket steel
does not currently identify a redesign requirement by itself. Complete-joint
adequacy remains unestablished, so the steel ratios cannot clear the joint.

The [isolated-joint kinematics](hypotheses/hl35-candidate/thin-frame-comparison/isolated-joint-kinematics-v4.json)
uses friction-free revolute bolt connectors: three point translations and two
rotations are constrained, while shaft rotation is free. All twelve single
fitting duties retain two local free motions; all twelve paired duties retain
one. A representative saved-state virtual-work check adds all local
flange-normal contacts and still finds two / one free motions. The old external
wrenches do essentially zero work along them. Current-geometry point projections
show potential coupling through other shafts and panel attachments, with
neighbors held fixed; they do not establish assembled restraint. Current
interbody response and contact activation remain needed. These are local
diagnostics rather than an assembled-frame instability result. The
[independent method audit](hypotheses/hl35-candidate/thin-frame-comparison/independent-method-audit-v4.json)
checks the underlying transformations and source census. Static equilibrium
witnesses, compatible stiffness results and resistance checks remain separate
evidence gates.

Workers share [authenticated exact solids](hypotheses/hl35-candidate/thin-frame-comparison/native-geometry-v4.json)
from one reconstruction of the reviewed model. The ignored BREP cache contains
all 883 parts, twenty raw timber profiles and six panel outlines; all 909 files
were reimported and independently rehashed. It is an active analysis input,
not a new geometry selection or machining packet.

The issued frame, panel, timber and steel method packets reuse that cache and
validated helpers. Independent review found four raw leg-foot corners inside
the existing rear recess. The first coupled state, its equilibrium receipt
and its steel comparison are preserved as **failed support-geometry evidence**;
their arithmetic closure does not qualify their physical load routing. The
[finished-contact audit](hypotheses/hl35-candidate/thin-frame-comparison/frame-contact-geometry-v4.json)
authenticates all eight finished footprints and confirms all 288 nominal
flange corners have timber backing. A new driver applies those footprints,
binds their provenance into a distinct state identity, and reuses the frozen
mechanics writer. The
[corrected A12-rear case](hypotheses/hl35-candidate/thin-frame-comparison/compatible-frame-a12-rear-finished-floor-v4.json)
passes the independent finished-support and arithmetic gate. Its simultaneous
panel-screw peak is **2,014.269 N tension / 361.801 N lateral**: generic head
indices **3.471 at CD1 / 2.169 at conditional CD1.6**. Nominal fitting-steel
yield reaches **0.539**. These are one first-order, parameterized-stiffness
case's component diagnostics. Physical shared-shaft behavior, rotation/contact
applicability, remaining cases and complete resistance checks still need
evidence before numerical MVP completion.
Those diagnostics remain usable within their recorded scope: the generic
panel-head and withdrawal references exceed, while nominal fitting yield is
below its reference. Reporting that bounded outcome does not require the
finite framework, and does not complete the changed model's assessment.

The continuous-shaft method now represents all seventy bolts, with separate
bearing in each of 82 wood and 72 steel spans and 140 own end captures. Its
seventeen fixtures and source-bound 132-body export gate are ready. The
[first common-shaft attempt](hypotheses/hl35-candidate/thin-frame-comparison/compatible-common-shaft-a12-rear-v4.json)
stopped at the Newton iteration limit with residual 21.829 N. It retains
inputs and failure provenance, with no recovered coefficients or actions;
it is numerical nonconvergence, not a strength result or instability proof.
The [stable-energy continuation](hypotheses/hl35-candidate/thin-frame-comparison/compatible-common-shaft-a12-rear-incremental-v4.json)
now closes each fixed support pattern below 2.3e-7 N, but the centroid-floor
activation pattern repeats. It remains a failed numerical experiment with no
accepted coefficients or actions. A separate contact method places horizontal
restraints at the actual bearing corners, retaining compression-only normal
contact and the declared no-slip assumption. Its stiffness distribution and
activation need their own validation; no floor capacity or anchor is inferred.
Independent review does not establish this refinement as necessary for a
bounded conditional MVP. The centroid approximation already releases a
wholly lifted foot; corner activation changes yaw and partial-bearing transfer.
The finished footprints, normal-port geometry and applicable method checks
are reusable, but reactions do not transfer across changed mechanics laws.

The finite panel adapter reproduces all six saved reference tangents and all
66 screw ports. A new circular-shaft method also resolves the bent-shaft
material-roll artifact without a torsional clamp. Their integrated finite
response, contact, local curvature/refinement and complete resistance remain
open. The first finite execution was stopped after review found that removing
the twelve retained-bolt proxies also removed direct compression between six
mating timber pairs. Radial shaft bearing and outer end captures do not supply
that path. The [interruption receipt](hypotheses/hl35-candidate/thin-frame-comparison/finite-a12-rear-omitted-timber-contact-v4.json)
preserves the frozen inputs and observed iterations; it contains no accepted
force field. The [targeted query](hypotheses/hl35-candidate/thin-frame-comparison/timber-face-contact-geometry-v4.json)
of eight finished cached timbers found six occupied patches with their bolt
holes excluded. A validated adapter adds 272 compression-only cells using the
existing finite connector law, with a declared 1 N/mm³ bedding scenario and
zero friction/preload. Its independent admission extension and three result
wrappers are frozen. Its poor saved-initial-guess attempt was stopped and
preserved. The corrected model's zero-reference attempt has identity
`thin-finite-v4-ac64687d3665d6a4c818457d`. It was interrupted at the six-hour
wall limit, exit 130, without an exported coefficient/action field or admission.
The six-contact omission was an implementation error when replacing the
retained-bolt proxies, not evidence of physical frame instability.
Three fixed floor branches reached the residual tolerance. Floor-activation
feedback changed all three. The fourth branch's last published residual was
0.000160812 N against 0.00001 N; current equilibrium remains unresolved.
Two targeted cached leg-section queries show why gross timber stiffness
cannot be a bound: at the existing recess station, the weaker centroidal
bending inertia is only 17.2% of gross. Unchanged geometry, access, material
references and unit-resistance methods continue to be reused. Detailed method
receipts and the interrupted attempts are in the existing
[completion ledger](completion-ledger.md#hl35-replacement-candidate).
Three further [existing receiver sections](hypotheses/hl35-candidate/thin-frame-comparison/timber-service-cut-sections-v4.json)
now have exact centroid and cross-inertia properties, obtained through the
same helper without repeating the inventory. At the queried lower-service
and center-principal sections, the stronger principal bending inertia is
72.2% of the nominal uncut rectangle. These geometry-only properties are
available for later same-cut recovery; they do not establish complete member
compliance or a strength result.

The previous finite A12-rear attempt is closed and will not be restarted.
The joint-first lean sequence has validated the shared-shaft and restored
timber-face method paths, their off-axis force recovery and independent
admission. The floor worker independently authenticated the new failed
support cycle `2→3→4→2`. The current blocker is finding a self-consistent
support state under the declared centroid law; this failure does not prove
the absence of one or physical frame instability. Its first lean case is
closed, with the failed field and transcript preserved in ignored output.
The new branch search tests each pattern against its own normal resultants;
it does not relax the residual tolerance or credit historical reactions.
The previous conditional findings and exact hardware/resistance gaps remain
in scope; old reactions do not supply the changed model's joint demands.
Existing panel/timber/steel calculations remain gated on the new admitted
field. Advanced checks and broader cases are deferred unless they can change
the governing decision. Contact
cycles, unresolved physical load paths or failed
applicable criteria stop extension. Selected timber stresses can reuse the
exact section helper. Washer seating pressure still needs a current own-face patch
and wrench; the connector's director couple cannot supply that missing input.
An unadopted DIN 433 M14 factory-washer option fits within the current external
seat envelope and clears the maximum head fillet when centered. Its larger
bore, changed bearing footprint and thickness require a seating/stack and
resistance recheck; no exact researched product yet binds tolerances, numeric
yield strength and price together. The existing ledger records the primary
product sources and keeps the reviewed model unchanged.
The four retained 8-inch leg bolts have an unadopted 8½-inch catalog comparison.
At its minimum catalog length, the unchanged modeled stack leaves 15.6464 mm
beyond the nut against the recorded two-pitch minimum of 3.9077 mm. The added
tips fit inside existing solid socket corridors under the original overlap
screen; this reuses saved geometry without another CAD query. A reviewed
bounds-only supplement now covers all added serial extraction regions through
217.9 mm travel, including other proposed longer tips as obstacles. It reuses
the old corridors and removes the four leg stacks first. This closes the
frozen-profile translation gap; delivered thread/shank geometry, seating,
actual handling and changed mechanics remain open. Details and source limits
are in the existing ledger.
General solver optimization and broad arbitrary stiffness sweeps are deferred.
The reviewed [finite initializer](../../scripts/thin_bolted_finite_seed.py)
can copy an admitted coordinate vector for later cases when the complete
prepared coordinate map and body order match. It keeps source and target
scenarios separate and requires fresh target equilibrium/admission. The
closed zero-reference attempt did not use it; future orchestration remains
unimplemented.
Two narrow post-admission methods are now frozen after parallel author/reviewer
work: [contact-centre kinematics](hypotheses/hl35-candidate/thin-frame-comparison/timber-contact-centre-kinematics-method-v4.json)
and the [corrected original-tangent admission wrapper](hypotheses/hl35-candidate/thin-frame-comparison/timber-contact-original-tangent-method-v4.json).
Their 38 and 53 focused synthetic fixtures passed. They reuse existing poses,
admission and matrix diagnostics; neither has consumed a candidate field.
The centre pullback remains a local inverse approximation with a forward
residual, and numerical tangent directions cannot establish stability.

The [thin-frame raw comparison](hypotheses/hl35-candidate/thin-frame-comparison/mixed-far-hole-raw-v2.json)
uses **24 B104ZN and 12 B103ZN angles**, all original timber sections, and two
bottom rails shifted **2 inches upslope**. All 72 flange attachments have full
raw-wood bore/rectangular-seat support, with no ideal plate/plate or plate/wood
collisions. They use 58 new physical bolt axes plus the twelve starting frame
axes. Conditional 5 mm screw bodies remain backed at all 66 locations; four
axes move from the original layout and eight differ from the reviewed block
layout. Brackets alone list at **$174.84 / 25.44 lb**; the twenty raw frame
members are **240.89 lb at 500 kg/m³**, excluding panels and hardware. These
are nominal raw-geometry results, not an integrated-model, access or strength
pass. Shared rail bores require explicit rotational/contact behavior, and
the lower-rail shift needs a panel-edge support calculation. The preceding
B102-only trial's eight collisions remain preserved.

The [revised occupied comparison](hypotheses/hl35-candidate/thin-frame-comparison/mixed-offset-rows-shallow-wires-v4.json)
separates the four outer-header fitting rows by a local 18 mm shift, proposes
fourteen smaller SAE washers, and routes all 131 wires through shallow,
front-open timber channels at the retained LED endpoints. All 72 flange bores
and seats and 140 washer seats outside intentional openings are supported;
the checked steel/steel, steel/wood, steel/screw and service intersections are
zero. These are conditional CAD results, not joint resistance or verified
removal access. The original centered wire passages are not cut in this new
timber proposal. Existing frozen failures remain unchanged.

The preserved panel geometry uses **CAT 23/32 inch (18.25625 mm)** plywood;
the owner described it as **3/4 inch**. The first screw-backing comparisons
used nominal 19.05 mm panels and 44.45 mm penetration. The
[integrated model evidence](hypotheses/hl35-candidate/thin-frame-comparison/integrated-model-v4.json)
now checks the full 45.24375 mm penetration at the preserved thinner panels:
**66/66** conditional screw bodies have receivers in both thickness scenarios.
Panel outlines are retained; all 142 T-nut, 132 LED and 66 mounting openings
are rebuilt at their current world datums. Actual thickness, screw-body
profile and head height have not been measured.

The latest viewer option is **Thin bolted frame**: twenty original-size frame
members, six panels, 36 fittings, 70 complete bolt stacks, 66 Hillman screw
envelopes and 405 service bodies. Its lossless 6.98 MB gzip scene preserves
every byte of the 15.16 MB raw export; unchanged lights and T-nuts share
existing source assets. The raw export is ignored and recoverable without CAD
using `scripts.thin_bolted_viewer_transport --restore-raw`. File-backed checks
verify all 883 visible parts and reject invalid census, transforms, stack roles
and hashes. They used existing bundled Three.js r184 geometry; the browser
viewer uses its existing r161 import. No browser/WebGL launch was possible in
this environment. Joint strength and physical access remain unqualified.

For a local Windows browser, start the viewer from a WSL terminal:

```sh
python3 -m http.server 8767 --bind 127.0.0.1 --directory /home/mckay-linux/repos/mini-moonboard/site
```

Then open
`http://localhost:8767/index.html?model=thin-bolted-development`.
The agent's sandbox blocked server sockets, so it did not leave a server
running. The updated option and data are local; no remote publication occurred.

The owner prioritizes cost while retaining adequate strength and dimensional
fit. Compare complete installed joint costs, including bracket quantity,
through-bolts, nuts/washers, stock changes and shipping. Current Eaton
comparison listings range from $3.53 for B103ZN to $6.92 for B115ZN; the
cheaper BR904 and more expensive specialized fittings remain comparison
leads, not selected details.
The ledger records current prices and quantity sensitivities.

**The earlier overnight HL35 attempt remains unqualified.**
`compact-floor-flush-hl35-development` is now a separate, unadopted development
candidate, preserving the selected baseline and reviewed wood-joint authority.
Its [preserved v8 proposal](hypotheses/hl35-candidate/counterbore-fit-v8/README.md)
maps 24 former block duties to 22 joints with **30 HL35s / 112 planning bolt
axes / 66 Hillman screws**. Complete checked angle, metal, screw and service
clashes now clear. **Four lower corner joints still need revision:** after
washer recesses only **112/120** receiving-wood probes and **52/60** nominal
flange seats meet the full-support comparison. The eight affected seats retain
about 86–87% bearing area; no reduced-area resistance is established.

Earlier v7 zero-clash and wood-support claims covered a narrower subset.
Its supplemental tip check found eight angle contacts and four unrelated-timber
contacts. V8 clears those contacts with deeper seats and adds the missing
post-recess wood assessment; it does not inherit the narrower pass.
Eight screw shifts, three wire proposals and changed stock/stacks remain confined
to this candidate. All distinct failed inputs and original authorities remain
preserved.

This is **REVISE / UNQUALIFIED**. Fourteen single-angle ends still need complete
reverse/contact and force/moment paths. Actual hardware, machining/access,
net wood sections and candidate-specific forces remain open. The sixteen
receivers alone are roughly **342 lb at an assumed 500 kg/m³**, excluding
legs/runners, panels and hardware. No native solve or release exists.
The owner's thinner-frame direction supersedes further development of this
enlarged-stock layout. Its four failed lower interfaces and remaining
engineering gates stay recorded; their results cannot qualify a successor.
Read the [HL35 development entry](completion-ledger.md#hl35-replacement-candidate).

**An aluminum-extrusion alternative is under consideration.** The owner has
bought no structural wood and proposed a demountable frame based on a Mini
MoonBoard video. Supplied creator comments identify SUS SF-series 40×40 mm
profiles, supplied cut to length by Frame DIY Lab; exact sections, connectors
and frame drawings remain unknown. The owner describes an outer cube containing
the sloped board. An audit of the assumed 2.6 m cube gives **64.969 m / 56
pieces** after one explicit butt-joint end-offset example, or **62.7306 m / 52
pieces** if a suitable detail can share the kicker-top/sloped-face-bottom row.
The original 55–70 m range remains a planning sensitivity, not validated bounds.
Eleven 6 m sticks fit the assumed pieces with 3 mm kerf; a conservative end-trim
packing example uses twelve for the separate-row case. Current Framing Tech
list prices put **11–12 sticks at $1,925–2,340 for extrusion alone**, depending
on section; cutting, hardware, freight and tax are additional. Parco bundles
and AutomationDirect short members provide further comparisons. Reusing the
original whole-frame allowances at the audited lengths gives **$2,600–3,700**
for the assumed TNUTZ price scaling and **$4,500–6,200** for 80/20 examples.
The SUS 40×40 example gives **250–280 lb** of frame including assumed hardware;
its US price remains unquoted. Each profile has its own mass and section
properties. These are concept quantities, not an observed video inventory or
a configured supplier quote. The video/screenshot attempt remains unsuccessful.
This is a separate, unselected concept retaining the owned plywood. Next work
needs actual room/video dimensions and member counts, a matched supplier quote,
connector evidence, panel attachment/support and stability checks at the
original 250 lb envelope. See the
[aluminum alternative](completion-ledger.md#quantity-audit-and-lower-cost-suppliers).

**The corrected 250 lb assessment remains the design basis and does not pass.**
The owner clarified that a full 145 lb evaluation is unnecessary; the completed
145 lb subset below remains a secondary comparison. At the corrected 250 lb
clearance-law basis, head pull-through is **2.373 at CD1.0 / 1.483 at conditional
CD1.6**, net rolling shear is **1.542**, and the supported bolt maximum is
**1.053**. The development recommendation is to revise panel load transfer and
central receiver/joint details, while completing the applicable resistance and
contact methods. Tested screw redistribution and added screws did not supply
a passing remedy. No revised geometry or hardware is selected.

**The owner's 145 lb comparison improves the supported numerical results.**
It retains the 2× downward multiplier, 300 N horizontal force, 100 mm hold lever
and source dead/accessory loads. Twelve source-available fields satisfy the
original physical gates. Peak head tension falls to **858.820 N**, giving
**1.480 at CD1.0 / 0.925 at conditional CD1.6**; normal-duration pull-through
still exceeds its reference. Net rolling shear falls to **0.957**, and the
supported scalar bolt maximum to **0.687**, with zero exceedances in those
comparisons. Two source-unavailable floor states remain unassessed at 145 lb.
The 250 lb envelope remains preserved.

The central post's NDS transverse-component maximum remains **1.758**, with
two definite exceedances. Relocating two existing screws reduces head tension
to **774.746 N**, but its **1.335 CD1.0** comparison still exceeds. The tested
98-screw fallback gives **1087.824 N / 1.875 CD1.0**, also exceeding conditional
CD1.6 at **1.172**. Neither layout is adopted.
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

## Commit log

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2026-09-04 fix: align v1 frame and stock-controlled cuts
    [mini_moonboard_v1_bom.csv, mini_moonboard_v1_concept.step, mini_moonboard_v1_cut_list.csv]
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2026-09-04 fix: reconcile v1 leg audit geometry
    [mini_moonboard_v1_concept.step, mini_moonboard_v1_connection_schedule.csv, mini_moonboard_v1_cut_list.csv]
2026-09-04 fix: close v1 audit traceability gaps
    [mini_moonboard_v1_bom.csv, mini_moonboard_v1_concept.step, mini_moonboard_v1_connection_schedule.csv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]
2026-09-04 fix: center v1 structural bolt datums
    [mini_moonboard_v1_concept.step, mini_moonboard_v1_connection_schedule.csv]
2026-09-04 fix: align v1 bolt stack and audit scope
    [mini_moonboard_v1_concept.step, mini_moonboard_v1_connection_schedule.csv]
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2026-09-04 fix: present v1 CAD render from climbing face
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2026-09-04 fix: orient v1 plans around underside climbing face
    [mini_moonboard_v1_connection_schedule.csv]
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2026-09-04 fix: model underside face and non-overlapping supports
    [mini_moonboard_reference.step, mini_moonboard_v1_concept.step, mini_moonboard_v1_connection_schedule.csv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]
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2026-09-04 fix: connect kicker seam and rear ties
    [mini_moonboard_v1_concept.step, mini_moonboard_v1_cut_list.csv]
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2026-09-04 fix: align climbing faces and rail load path
    [mini_moonboard_reference.step, mini_moonboard_v1_concept.step, mini_moonboard_v1_connection_schedule.csv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]
2026-09-04 fix: bridge rail segment splices
    [mini_moonboard_v1_concept.step, mini_moonboard_v1_cut_list.csv]
2026-09-04 fix: leave saw kerf in V1 sheet cuts
    [mini_moonboard_v1_concept.step, mini_moonboard_v1_connection_schedule.csv, mini_moonboard_v1_cut_list.csv]
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2026-09-04 fix: unify V1 structural bolt lengths
    [mini_moonboard_v1_connection_schedule.csv]
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2026-09-04 fix: size V1 kicker gusset blanks
    [mini_moonboard_v1_cut_list.csv]
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2026-09-04 fix: clarify V1 leg laminate orientation
    [mini_moonboard_v1_leg_cut_schedule.csv]
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2026-09-04 fix: reconcile V1 LED kit surplus
    [mini_moonboard_v1_bom.csv]
2026-09-04 fix: preserve full-width V1 main panels
    [mini_moonboard_v1_assembly_layout.csv, mini_moonboard_v1_concept.step, mini_moonboard_v1_connection_schedule.csv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]
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2026-09-04 fix: clear climber envelope and improve viewer cuts
    [face_rail_1_lower.stl, face_rail_1_upper.stl, face_rail_2_lower.stl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]
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2026-09-04 fix: establish climbing-face orientation convention
    [mini_moonboard_v1_assembly_layout.csv, mini_moonboard_v1_connection_schedule.csv]
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2026-09-04 fix: move viewer board another 500 mm rearward
2026-09-04 feat: replace rail frame with laminated box and perimeter fastening
    [analysis_batten_end_left_1.stl, analysis_batten_end_left_2.stl, analysis_batten_end_left_3.stl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]
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2026-09-05 fix: audit stability load basis and use four panel screws per edge
    [analysis_panel_screw_10.stl, analysis_panel_screw_11.stl, analysis_panel_screw_12.stl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]
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2026-09-05 fix: share panel corner screws and reduce kicker fasteners
    [analysis_kicker_screw_left_bottom_1.stl, analysis_kicker_screw_left_bottom_2.stl, analysis_kicker_screw_left_bottom_3.stl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]
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2026-09-06 fea: publish bent-leg independent-ply compliance and energy comparison
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2026-09-06 docs: identify catalogued short leg stitch bolt lead
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2026-09-06 fea: qualify bounded full-frame observer runner and failure audits
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2026-09-07 design: replace ten perimeter joints with inspectable side-grain routes
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2026-09-07 publish: expose bolted redesigns with CAD audits and stability sensitivities
    [bolted-block-frame.step, bolted-block-frame_blank_groups.csv, bolted-block-frame_connections.csv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]
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2026-09-08 test: verify current washer seating and through-bolt tolerance stacks
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2026-09-08 cad: reject backing-end angle trial after complete hardware collision check
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2026-09-08 docs: resolve larger-bolt plywood bearing input from AWC TR12
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2026-09-08 analysis: rule out steel-grade-only fix under current leg assumptions
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2026-09-09 fea: verify compact spread legs across native stiffness cases
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2026-09-10 cad: retain single-2x6 screw-first baseline with square lower rails and failure audit
    [connections.csv, future-insert-reserves.csv, square-2x6.step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]
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2026-09-10 cad: remove paired 2x6 framing and expose remaining seam failures
    [base_header.stl, base_post_center.stl, base_post_outer_left.stl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]
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2026-09-11 cad: replace middle rails with supported 2x6 principals
    Retain gussets and expose unsupported panel seams. Archive benchmarked shell comparisons showing lower loaded-patch compliance but greater upper-seam movement; no structural or gusset qualification.
    [base_header.stl, base_post_center.stl, base_post_left_1.stl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]
2026-09-11 cad: split center principals and expose complete bolt stacks
    Replace the single center receiver with two independent 2x6 principals and full-depth posts. Extend outer posts to cover the header bearing footprints and expose each through-bolt head, nut and washer in the viewer.
    Publish current fit checks, rigid-floor witnesses and expanded panel comparisons. Record adverse center-seam and attachment diagnostics; construction qualification remains unresolved. Validate 38 targeted tests and actual viewer selections.
    [base_header.stl, base_post_center_left.stl, base_post_center_right.stl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]
2026-09-11 cad: replace base gussets with direct angles and audit panel screw infill
    [angle-base-development.step, base_header.stl, base_post_center_left.stl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]
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2026-09-11 cad: publish horizontal service frame, wiring and development plans
    Replace intermediate principals and posts with four service rails, retain the split center and complete bolt stacks, and model provisional LED routes and timber grooves. Include category controls, prototype weights, datum drilling sheets, stock allocation, coupled diagnostics and an independent assumptions handoff. Structural qualification and physical kit verification remain open.
    [base_header.stl, base_post_center_left.stl, base_post_center_right.stl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]
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2026-09-12 docs: add pass/fail connection-status ledger for member checks
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2026-09-12 cad: align upper service rail with fixed panel attachment row
    [base_principal_center_left.stl, base_principal_center_right.stl, base_rail_service_upper_left.stl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]
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2026-09-12 fea: bound current panel forces and document structural release shortfalls
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2026-09-12 cad: add reinforced development candidate and selectable hold T-nuts
    [base_header.stl, base_post_center_left.stl, base_post_center_right.stl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]
2026-09-12 analysis: complete reinforced frame checks and record release failures
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2026-09-13 Develop compact 4x6 frame and archive connection studies
    Add the compact 2x6 base, flush 4x6 rims, three-bolt viewer candidate and draft construction schedules. Preserve two-bolt, rail and higher-leg alternatives with reproducible native evidence and conditional resistance checks.
    Keep the failed upper-joint placement checks explicit; no build-ready drilling is released. Update current-candidate CI while retaining opt-in historical checks. Validation: 413 tests passed, 15 historical tests deselected; Ruff passed.
    [assembly.step, base_header.stl, base_post_center_left.stl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]
2026-09-13 Evaluate paired-bolt knee brace load path
    Add actual opposite end tabs and paired brace bolts, explicit receiver-bearing checks, and square-ended native member support. Archive the rejected single-bolt mechanism and accepted paired-bolt response with all-bolt and sampled net-section checks.
    The worst individual bolt ratio improves to 0.472, but an upper-leg loaded-edge shortfall and brace-tab qualification remain open. Keep the viewer and construction release unchanged. Validation: 426 tests passed, 15 historical tests deselected; Ruff passed.
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2026-09-14 Add floor-rail candidate and correct base clip placement
    Add a separate floor-rail frame with six accepted conditional load cases,
    contact-grid sensitivity, source-bound CAD exports and fabrication schedules.
    Move the outer base angles onto the header and retain the required rim-end
    reserve. Correct the native panel mesh to include the actual kicker cutouts.
    Preserve the exterior-brace alternative as explicitly unaccepted after its
    side-load contact solve failed to converge. Retain superseded geometric and
    numerical trials without transferring their results to the completed route.
    Validation: 467 default tests passed, Ruff and CadQuery smoke passed, clean
    CAD builds and the preserved basel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
    [assembly.step, base_floor_left.stl, base_floor_right.stl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]
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2026-09-15 Verify six tapered-runner cases and exterior braces; add crash pads
    [assembly.step, base_floor_left.stl, base_floor_right.stl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]
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2026-09-18 Make builder docs the front door and fix the 4x8 kerf layout
    Keep equal 1/16 in faces with the missing 1/8 in on the K/right edge,
    because Moon layout starts from the left. Point shop pages at full
    GitHub and viewer URLs, cut repeated caveats, add simple diagrams, and
    move older studies into docs/history with a docs/README map.
    [assembly.step, kicker_left.stl, kicker_right.stl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]
2026-09-18 Seat the top center header clips so the front SDS stays in the wood
    clip_split_base_center_* sat too far toward the kicker, so beam_3 broke
    out of the header front. Move those two angles back half an ML24Z pitch
    from the underside pair. Viewer and construction sheets follow. The
    frozen six-case snapshot still fingerprints the previous clip station.
    [assembly.step, base_header.stl, base_principal_center_left.stl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]
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2026-09-19 Correct A66 edge screen and leave factory hole unresolved
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2026-09-19 Export full baseline scope and correct bolted task gates
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2026-09-19 Screen nominal center screw clearance against trial steel
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2026-09-19 Correct shared bolt directions and bind diagnostic extraction
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2026-09-19 Classify provisional center bolt directions and failed case
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2026-09-20 Bound BR904 center pose by NDS hole fit and tolerance
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2026-09-20 Bound fixed center post shift by all bolt pairs and kicker axes
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2026-09-20 Bound reversible post edge clearance independently of bolt pose
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2026-09-20 Shortlist exact retail factory brackets for rail duties
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2026-09-20 Source six-inch bolt leads for shorter cleat grip
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2026-09-20 Sample PB01 face contact off-row and expose trial stiffnesses
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2026-09-20 Track timber helper drift in stale native input test
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2026-09-21 Fail recessed header pose on screw receiver loss
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2026-09-21 Check second bolts at tolerant center pose and short block net cuts
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2026-09-21 Shorten center post header block for eight-inch bolt trial
2026-09-21 Screen retail eight-inch bolt stack for shorter center block
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2026-09-21 Resolve signed PB01 bolt-pair force and couple algebra
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2026-09-21 Model seated PB04 outer bolt trial and tolerance gap
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2026-09-21 Record compact upper-block collision and revised rail disposition
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2026-09-21 Bound cross-dowel thread fit and narrow-block hardware tolerances
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2026-09-22 Bound bottom-center tool clearance under current block pose
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2026-09-22 Screen six inch bolts with shorter rail setback
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2026-09-22 Screen connected barrel frame with corrected retained interfaces
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2026-09-24 Restore fixed service holes in candidate kerf-right panels
    Rebuild displaced grid openings without changing the selected baseline or the 66 panel screw axes. Preserve the candidate kicker extension and current panel metadata. Synthetic regressions and a separate actual-source geometry check passed; consumer integration follows.
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2026-09-24 Integrate corrected candidate panels across joint reports and viewer
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2026-09-24 Record sampled local rail placement and service interference
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2026-09-24 Correct center contact face and screen ordinary bolt shaft tolerance
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2026-09-25 Map current evaluation gates and bounded thread stiffness scenarios
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2026-09-25 Classify current joint contacts and record open-clearance free motions
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2026-10-01 Document the frame stiffness export and corrected staged load maps
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2026-10-02 Reduce repository clutter while preserving historical evidence
    Share byte-identical viewer meshes with aliases and temporarily restore legacy
    paths for exporters and tests. Add verified external evidence archiving, shorten
    the current development summary, and record closed-run and scratch cleanup.
    Preserve selected candidate geometry, frozen manifests, all historical design
    choices, and work belonging to other agents.
    Validation: nine focused tests, five browser scenes, mesh hash and URL checks,
    and 49 affected integration tests passed. Existing weight-catalog and selected
    geometry-snapshot failures remain unchanged.
    [analysis_batten_end_left_1.stl, analysis_batten_end_left_2.stl, analysis_batten_end_left_3.stl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]
2026-10-02 Document agent practices to keep repository growth bounded
    Keep routine status in existing summaries, reuse applicable experiments and
    helpers, and avoid duplicate raw assets. Require verified external recovery
    before pruning closed runs and serialize shared mesh materialization.
    Preserve frozen evidence, failed results, historical viewers and other agents'
    work. Review generated file volume and stage only owned changes.
    Validation: document links and tool paths checked, git diff --check passed,
    and independent review found no substantial issues.
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2026-10-02 Calculate both top corners with coupled clearance and component demands
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2026-10-02 Integrate header checks, panel references and bounded bolt clearance
2026-10-02 Replay bounded bolt-clearance forces and publish conditional shop guide
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2026-10-02 Record finite panel-law sensitivity on the current clearance frame
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2026-10-03 Preserve historical frame mechanics methods and stopped comparison records
    Publish 148 existing sources and notes with their coordinator records. Preserve exact frozen bytes, including the inherited trailing blank line noted by diff-check. Recorded failures and historical candidate scopes remain explicit; no engineering or test runs, acceptance transfer, or release changes.
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2026-10-03 Publish historical joint evidence sources and their original scope records
    Preserve completed source worksheets, stopped A12 recovery, integration records and dated handoffs. The expanded artifact manifest remains its historical snapshot with documented operational digest drift; it is not a validated current manifest. Preserve intentional Markdown hard-break whitespace in frozen reports. No tests, native runs, acceptance transfer or release changes.
2026-10-03 Record spine opening route result and prepare supported joint boundary methods
    Publish the authenticated 12-state zero-perpendicular-tension necessary-condition failures without calling them physical fracture failures. Preserve prepared annular-column and header-pressure methods separately from executed qualification. No geometry, hardware policy, authority or release changes.
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2026-10-03 Publish finite bolt detailing and installed clearance assessments
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2026-10-04 Record wood-joint numerical comparisons and evidence validation
    Publish compatible-frame, washer, shaft, member, panel and splitting
    comparison helpers with their source-bound evidence and maintained ledgers.
    Keep the numerical extension in progress and preserve all 47 pending
    criteria, eight false release flags, original assessment scopes, reference
    exceedances and explicit method limits. Raw native runs remain ignored.
    The evidence checker authenticates 30 registered packets and 11,221 source
    bindings. All 175 focused validator tests, Python syntax checks, the CadQuery
    smoke test and shared viewer-mesh URL checks pass. Existing maintained-entry
    lint reports 151 findings; two frozen packet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
2026-10-05 Publish current-force washer results and scope receipt ownership
    Record 2,496 washer-end dispositions: 2,400 finite plate fields, 96 exact
    source-geometry limits and 18 assumed-yield reference exceedances. Join the
    wider-profile force basis to eight current consumer packets while keeping
    all 47 formal criteria pending and eight release flags false.
    Authenticate directly consumed receipt owners through their own frozen
    source redirects. Preserve historical context without flattening conflicting
    source versions, reject substitute field advertisers, and apply the recorded
    2e-12 Nmm normal-contact oracle bound.
    Validation: read-only evidence check passes 31 packets and 14,577 source
    bindings.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
2026-10-09 Publish raised-rail Eoere numerical and shop packet
    Report six fresh fixed-rear-leg cases with source-bound component and joint dispositions, retaining exceedances and unknown complete joint resistance. Add current member/hole and 100-stack/200-side tables with nominal receiving, assembly and removal guidance. Preserve original and owner-requested nominal heel scenarios and independent reviews.
    Retain the selectable raised-rail viewer and verified external evidence recovery without pruning raw inputs or changing selected authority. Scoped source, consumer, shop and documentation checks pass. Shared pytest, lint and selected-baseline configuration failures and their applicability limits are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
    [access-sides.csv, bolt-stacks.csv, member-end-datums.csv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]
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2026-10-09 Complete conditional Z180 evaluation and shop packet
    Record six fresh admitted cases, matching component comparisons and the nominal shop outputs. Preserve exceeded references, unknown complete resistance and the separate unadopted geometry scope. Retain corrected reporting methods, independent reviews and compact evidence while leaving raw runs active and ignored.
    [access-sides.csv, bolt-stacks.csv, members.csv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]
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2026-10-10 Repair CI and record bounded structural limits
    Preserve issued source bytes with exact lint waivers and a hash guard,
    restore executable shebang modes, and separate archived replay inputs
    from portable default tests. Authenticate the disclosed baseline clip
    change against all six source archives without transferring their passes.
    Record all 100 selected bolt stacks and 120 timber bearing intervals,
    retain preceding own-case exceedances, and keep current resistance unknown.
    Do not change hardware or geometry, attempt remedies, or run native solves.
    Validation: 90 focused Python tests, five portable orchestration tests,
    48 Node controls, 185 packet tests, 22 descriptor tests, lint, mesh chec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
2026-10-13 Record current qualification limits and consolidate builder guidance
    Record the owner's decision to keep the current Eoere design with its
    three qualification limits. Add the complete cleat-wrench and front-bolt
    placement investigations, preserved numerical helpers and regression controls.
    Keep recovered-source checks explicitly selectable while retaining portable
    checks in CI. Consolidate current cut, receiver and assembly records in the
    builder guide and correct reading paths for earlier design documentation.
    Route current and preserved viewer documentation separately, report missing
    historical exports, and repair the historical post chart controls. Bind Pages
    run titles to the validatin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
2026-10-15 Record bounded Eoere qualification and remaining limits
    Preserve the reviewed 100-bolt, 66-Hillman design and consolidate the
    remaining qualification decisions in the maintained summary and ledger.
    Retain completed component/member checks, recorded model failures and
    unsupported complete resistance and response qualifications. Add the 24
    rear-leg staggered-hole nominal normal comparisons and current restraint
    direction inventory without granting brace credit.
    Publish the frozen inputs, reproducible helpers and portable controls at
    their existing paths while keeping bulky raw evidence ignored. Classify
    rejected-proposal and recovered-kernel controls explicitly, preserving
    default algebra/sou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
2026-10-20 Use 4x6 front posts and narrower cable openings
    Update the two outer posts and eight bolt stacks, narrow 32 channel openings to 14 mm, and publish the matching viewer, shop datums and revision bindings. Preserve preceding candidates and recorded structural holds.
    Include the additive panel size-reference correction and current cleat, rear-foot and installation findings. No response pass or complete-joint acceptance transfers to the revised geometry.
    Validation: repository lint, 234 development/navigation controls, 27 focused Python tests, source bindings, assembled mesh checks, browser checks and compact viewer asset checks pass. The earlier full pytest run remains incomplete as recorded i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
2026-10-24 Checkpoint standard-stock bolted frame and provisional wood plan [skip ci]
    Record the standard 4x6 top-and-sides development candidate, its matched six-case evidence, preserved V5-V10 history and provisional 13-board allocation. Complete connection qualification and all physical release holds remain open.
    Validated 509 viewer/document tests, 291 focused Python tests, scoped lint, smoke, mesh aliases and source bindings. The broad baseline run was stopped after 3961 passes and is recorded as incomplete. Skip hosted CI to prevent the automatic Pages deployment; this checkpoint does not authorize deployment or physical work.
2026-10-24 Record packer-free 4x6 geometry and matched development results [skip ci]
    Retain the baseline and previous candidates while binding six fresh cases, both replay paths, current method audits, wood planning and the local results viewer. All connection, physical and release holds remain explicit.
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2026-10-27 Add V11 shorter-bolt evidence and connection assessment
    Record the matched six-case bank, twelve replays, hardware schedule and separate viewer for the owner-authorized shorter-bolt trial. Add a source-bound connection assessment while preserving historical diagnostics, unresolved criteria and release holds.
    Validation: 892 affected Node tests, publisher Ruff, 46 direct source bindings and byte-identical assessment reproduction. The connection follow-through changes no frame geometry or force case.
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2026-10-27 Integrate V11 joint method and component follow-through
    Compose the unchanged 112-axis bank with the common-work references, actual side sections, fitting states, plywood washer checks and recovered adhesive basis. Preserve V2 and all historical diagnostics; complete connection qualification remains open. Validate public source bindings and scope with 986 affected Node tests.
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2026-10-28 Bind the review-only Grade 5 option to current forces
    Evaluate the existing twelve-cleat-bolt profile bound on the 106-bolt force bank and transfer the saved head/tool feasibility using 288 independently checked separations from restored top material. Keep all current hardware, geometry, material flags and force fields unchanged pending the owner decision and matched alternate analysis.
    Correct the procurement wording: four current stacks share one conditional Grade 5 type without a qualified supplier SKU.
    Validation: 144 current-state bounds, six field hashes, 50-digit arithmetic control, 68 clearance-source references, 288 independent bounds, 21 focused Node tests, authority/source check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
2026-10-29 Evaluate the 102-bolt six-per-cleat trial
    Add the separate fresh-stock alternative that omits four short-end cleat-post
    axes while retaining the other hardware, geometry outlines and screw policy.
    Bind its six-case bank, twelve replays, connection and component calculations,
    computed viewer and provisional planning packet to their own source evidence.
    Record the rear-foot planar reference of 0.999045 and the retained diagnostic
    exceedances. Keep complete joint and actual material/contact/bond/support
    qualifications open, with selected authority and all physical releases unchanged.
    Validation: 1,378 Node contracts, 19 portable Python tests, scoped Ruff,
    CadQuery smoke, shared-mesh checks, c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
